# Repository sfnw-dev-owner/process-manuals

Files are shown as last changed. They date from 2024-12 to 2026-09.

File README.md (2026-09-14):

## Tiny Home Manuals

### Background

This is the home of all manuals used in the Sound Foundations Tiny Home build process. 

Each manual has its own separate folder. Text is stored in Markdown, and images are in a subfolder, so that they can be edited independently. 

Rendering is done through a pipeline of Pandoc and Typst, which generates a PDF file that combines the text and images into a printable document. 

### Authors

If you have questions about the manuals, please direct them to: 

* David Means (means@digitalelephant.org)
  * All manual text and home building processes
  * 2D images 
* Charlie Benditt (cbenditt@hotmail.com)
  * 3D images 
  * Whole-home model
* Ami Fischman (ami@fischman.org)
  * Technical questions related to this github repository, generating and editing manuals
* Daphne Chong (daphne.h.chong@gmail.com)
  * Originator of the 3d model for a Tiny Home

## Setup & Installation

You will need:

* Git source control software, either in [command line](https://git-scm.com/downloads) version or a [user interface like GitHub Desktop](https://github.com/apps/desktop)
* A text editor that can edit plain text without introducing other markup (eg Vi, Emacs, Notepad)
* A local computer to run this stuff on, and to keep a local copy of the repository.

## Formatting a manual

Our process begins with a text file containing the desired content, and Markdown commands to indicate formatting.  This source file is processed by a pipeline of two stages: first by Pandoc, which transform the markdown into Typst input, and then by Typst, a typesetting program that renders its input as a PDF file.  This pipeline is captured as a virtual machine, and is invoked as `render/go {source_file}`.  When this script is run, it either generates a PDF file with the same base name as the source_file, or else it coughs up some error report, saying why it could not.

### Common template file

Using a template creates a consistent look and feel for all of the manuals generated. The default settings for our documents are kept in `render/pandoc-defaults.yaml` and `render/typst-header.typ`. 

The template has instances of:

* Heading 1
* Heading 2
* Heading 3
* Heading 4
* Normal text (which bullet lists also use, see note below)
* Footer with automatic revision date insertion

### Bullet lists

Generally, a bullet list is defined in markdown with a prefix of `*` `-` or `+`. Sub-lists look the same, but indented (2 spaces, or a tab)

### Aligning images in Markdown

Images that aren't geared to letter sized paper might require adjusting. These are the current settings in `post-tilt-up` and `tilt-up` manuals (where images are generated as A5 size and designed for A4 paper, which has different dimensions than Letter).

#### Top of document 
* Treat all images in the document as "figures" 
* Align all figures in center for PDF files

#### Centering an individual image
For an individual image, you must leave an empty line before and after each image in the markdown, otherwise the center alignment won't work. 
```
// won't work for center alignment
![](images/image_39.png){width="78%" height="78%"}
![](images/image_39.png){width="78%" height="78%"}

// will work for center alignment
![](images/image_39.png){width="78%" height="78%"}

![](images/image_39.png){width="78%" height="78%"}

```
#### Resizing images to get more than one on a single page

As above, we use a **78%** scale to get more than one image on a single page, which allows for spacing for the (blank) captions generated by pandoc. 

```
![](images/image_39.png){width="78%" height="78%"}
```

This applies with the current Letter page size with 0.5" margins. 

## Generating 2-d drawings
We have moved to a mechanism that allows us to put a QCAD .dxf file under revision control, and to create PDF images automatically from the .dxf file.
The invocation for an image that is to be included is

```
`#fullpage("images/{qcad_filename}.dxf", layers:"{comma-separated list of layer names}")`{=typst}
```

By convention, the DXF file is placed in the **images** sub-folder

 The layers to be made visible in the drawing file are specified as a comma-separated list.  Spaces are allowed within each layer name, but there should not be any white-space between the layer name and the preceding or following comma.

 Also note that the `typst` syntax in the example above (anything passed to a \'#...{=typst}\` macro) requires a colon (`:`) between `layers` and the layer names, whereas the markdown syntax (e.g. ``) requires an equal sign (`=`).

## Rendering a Manual

### Generating the PDF file

Contents are taken from the `<manual_markdown_file.md>`, combined with any images referenced from the markdown, and rendered into a new `pdf` document.

To render the document:

* Open a command-line shell window
* `cd` to the directory where your markdown file is stored
* Type the command `../render/go <manual_markdown_file.md>`
* This generates a new file `<manual_markdown_file.pdf>` in the same folder as the `<manual_markdown_file.md>` file, with all of the correct formatting (based on styles in the template files), and the text and images referenced in the markdown. 

### Add the source file to source control

After generating a PDF file, check it throughly for formatting errors, correct them in the source (.md) file, and repeat the rendering, until you are satisfied.  Then, it would be good practice to delete the PDF file, before you even commit changed files locally.

Commit the source material only (the .md file and any images, qcad drawing files or other included files).  Do NOT commit the PDF generated above.

A github **workflow** will kick off an **action** which will generate a GitHub Release containing all rendered PDFs. See the latest release at https://github.com/sfnw-dev-owner/process-manuals/releases/latest.

If you create a brand-new .md file, it is good practice to add the corresponding .pdf filename to .gitignore. This will reduce the chance that
you inadvertently add a PDF to a *git commit*, polluting the source tree with a derived file.

## Editing 3D model and images used in Tilt Up & Post Tilt Up 
All of the 3D images and diagrams in the manuals are created using LayOut, based on this [Tiny Home Model](https://web.connect.trimble.com/projects/H3xXgzdyUMc/viewer/3d/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) built in SketchUp. 

You will need:

 * [SketchUp](https://www.sketchup.com) to edit the model. There are [free web-based editions of SketchUp](https://www.sketchup.com/en/plans-and-pricing/sketchup-free), although the model was built on a desktop using SketchUp Pro.
 * [LayOut](https://www.sketchup.com/en/products/layout), part of the SketchUp Pro package, for taking scenes built in the model and laying them out on to pages with various insets and annotations.
 * Permissions to edit the model. At the moment, only a limited number of people have access.

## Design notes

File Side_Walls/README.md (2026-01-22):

sidewall_[13].md correspond to the two different jigs for building
side-walls. They are nearly identical except for mirrored drawings and
funky board location being different.

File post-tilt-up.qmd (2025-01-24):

---
format:
  docx:
    reference-doc: manual-template.docx
    fig-align: center
from: markdown-implicit_figures
--- 

# Secure walls to platform

* Equip two crews of two people with screw guns and brown #10 x 3” screws, and have them install 4 screws in each bay of all four walls, through the bottom plate into the platform, as shown in the diagram.

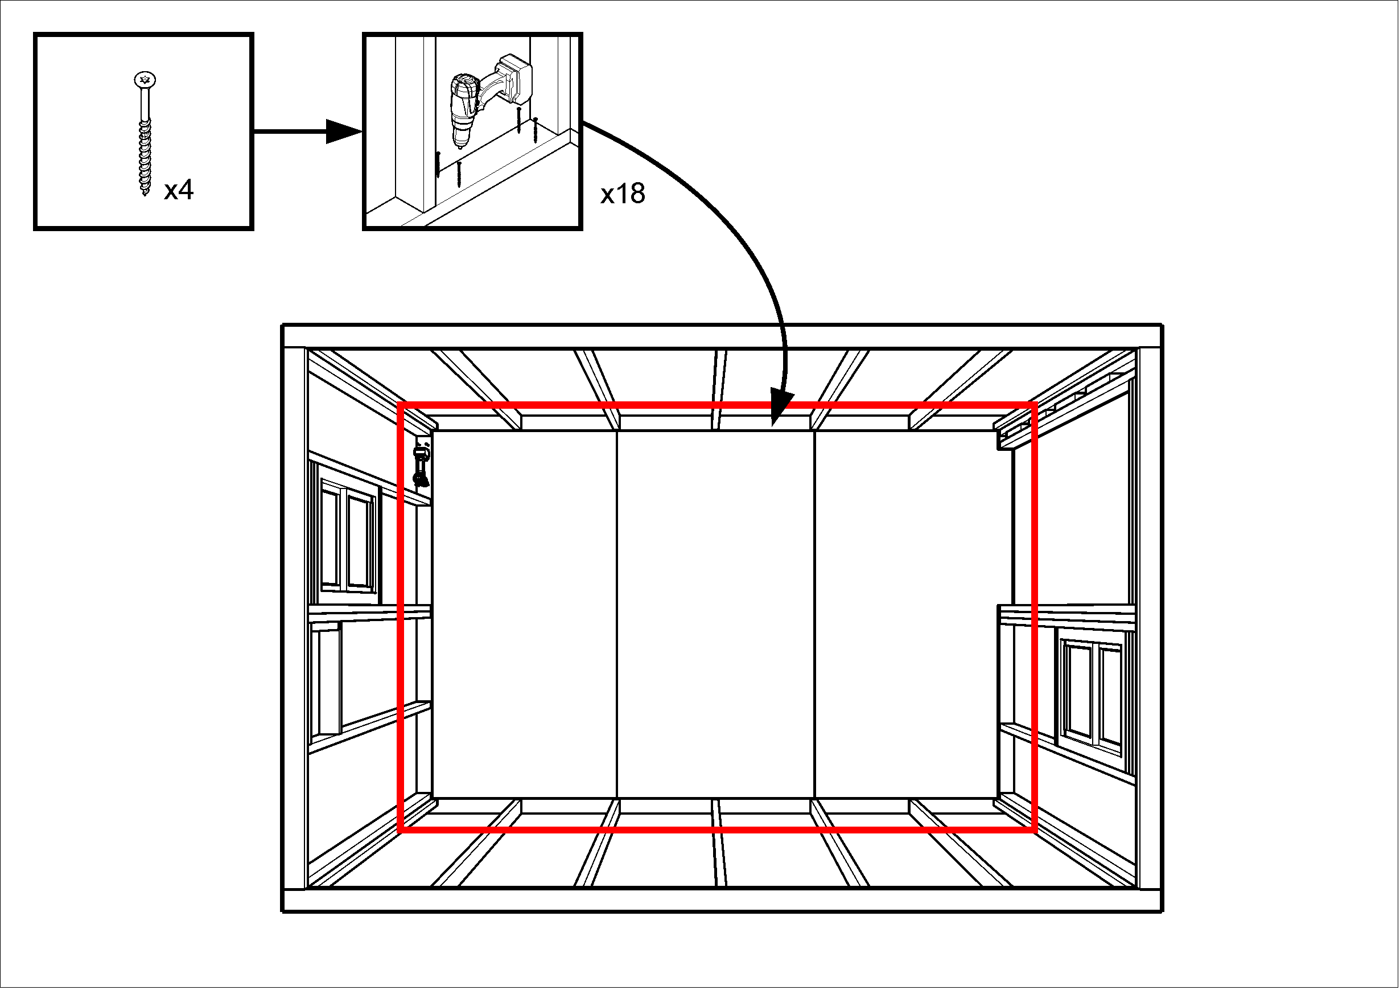
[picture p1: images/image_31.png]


{{< pagebreak >}}

* Have one person install 5 #10 x 3” screws in each wall corner, to reinforce these corners

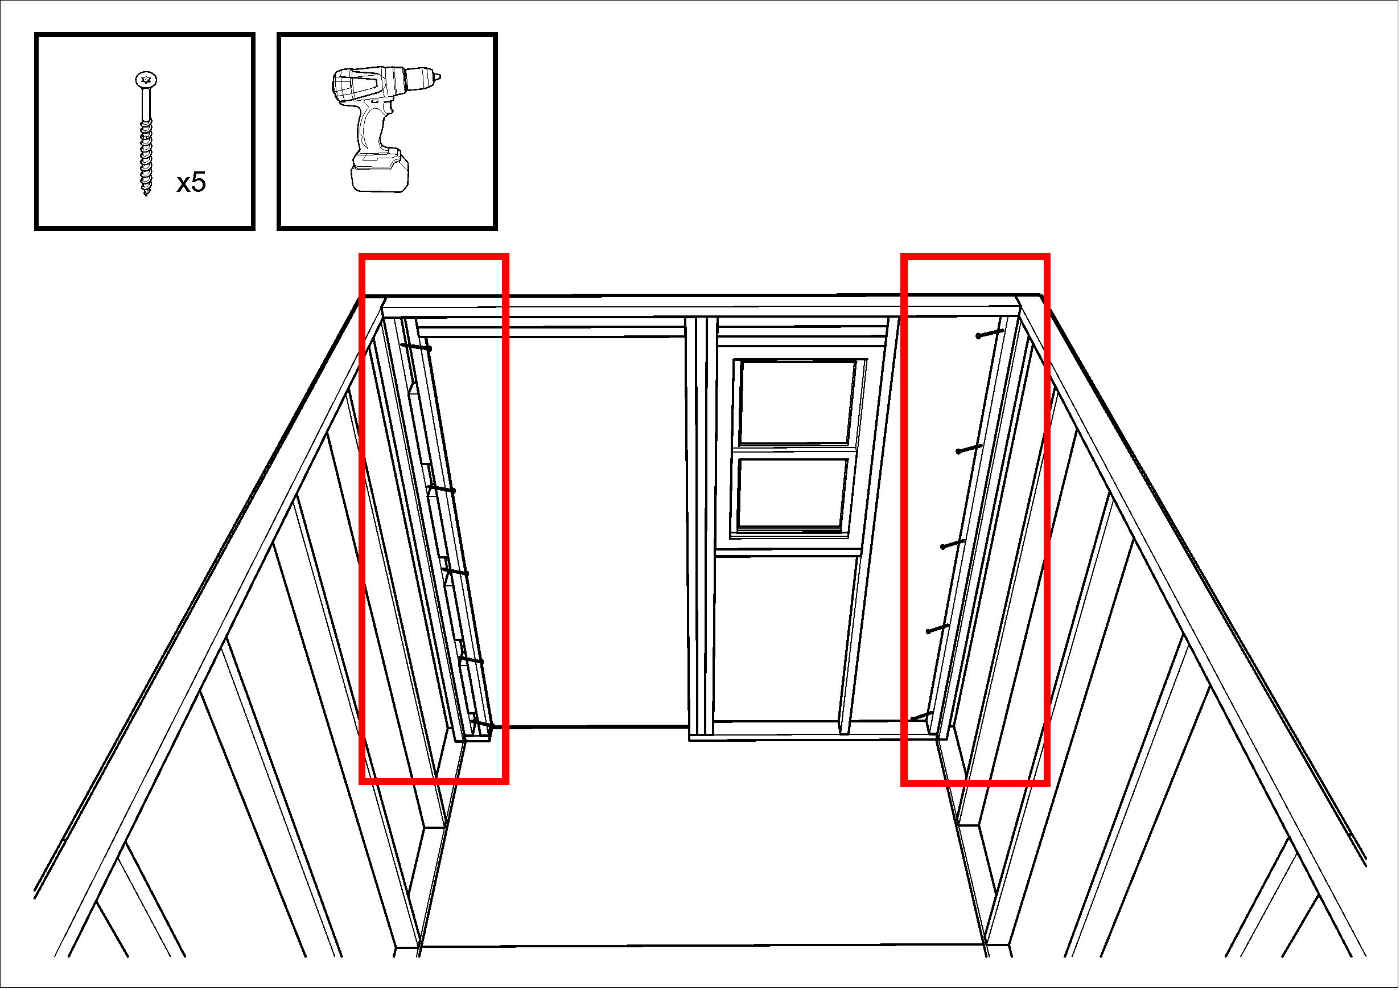
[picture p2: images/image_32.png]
 

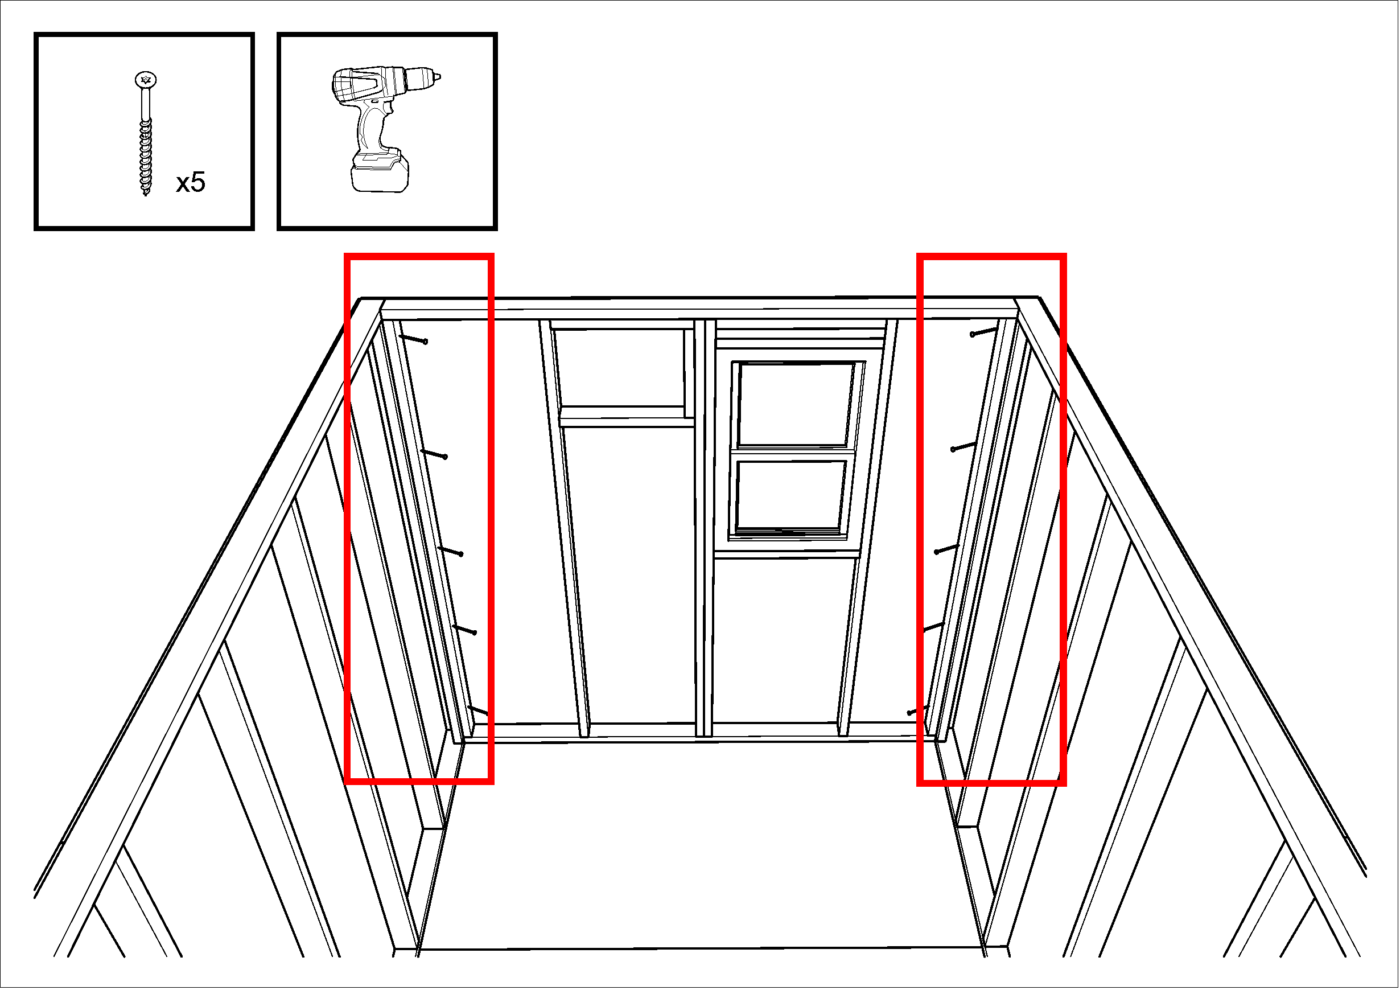
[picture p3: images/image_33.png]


<!--- 
This is an implied page break - avoids an empty page being generated
---> 

*	Using panel nails and working from the outside of the home, nail through the wall paneling into the base of the platform frame about 1” above the bottom of the paneling, every 8” all the way around the home.
*	Again, using panel nails and working from the outside of the home, nail the edges of the front and rear wall panels to the side-wall framing, about 1” in from the edges of the paneling, and 8” apart all the way from bottom to top of each corner.
*	Verify that the exterior paneling is nailed to the frame around the top and sides of the front door.  If not, nail that at this stage (every 8”).
*	Using a reciprocating saw (Sawzall), cut through the bottom plate of the front wall at each side of the doorway.  This should free the 2x4 so that it can be removed.  Use a knife to cut the Tyvek even with the top of the platform, and then use the Sawzall to cut the paneling at the bottom of the doorway so that it is flush with the top of the platform.
*	Using the angle-iron gauge (in the pencil cup in #4 workstation) and an ink marker, draw a line down the center of each of the “magic” studs.  These are the studs on the side walls at the rear of the second bay (4’ from the front wall).
*	Using a speed square, draw a 6” mark on the subfloor where the center of each stud is.  On the top plate of each wall, mark (freehand) where the center of each stud is.  These marks will be used by the people installing wall panels.
*	Using panel nails, nail the paneling to the platform across the bottom of the doorway.

{{< pagebreak >}}

# Install structural triangles

*	Position two 12-foot ladders, one at each end of the building.
*	Preset brown #10x3” screws in each of two structural triangles, as shown in the diagram a couple of pages on from here.  In the two center bays, there are four screws, angled enough that you could drive them in with an impact driver.  In the two outer bays, there are two screws angled in from one side of the triangle, starting about ¾” in from the edge of the bottom plate.  Then there are two screws driven in vertically about 1” toward the center from the seam between the bottom plate and the angled side of the triangle.

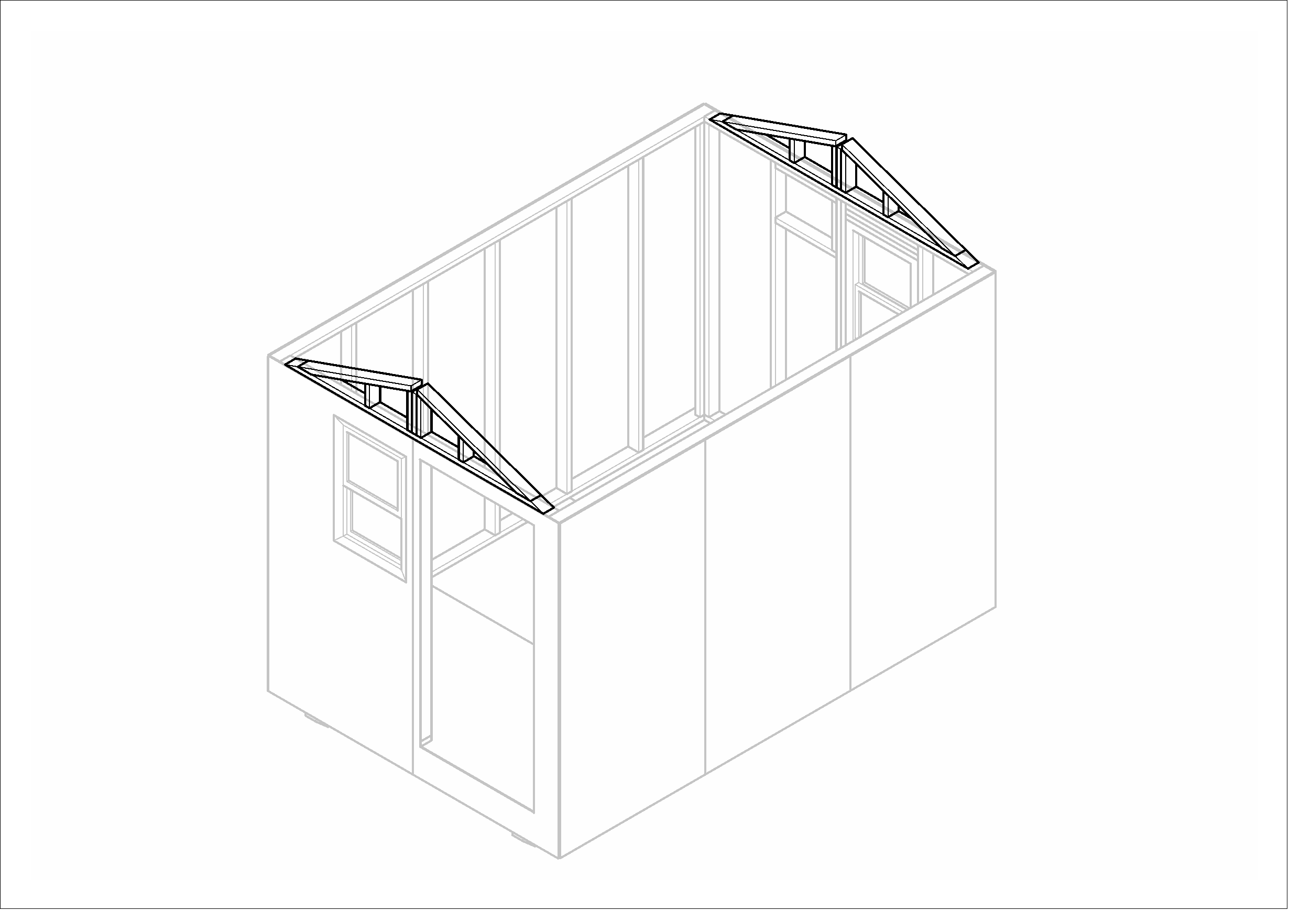
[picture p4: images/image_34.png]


{{< pagebreak >}}

*	Position a triangle on the front wall, and, with a helper inside the home, center it from side to side.

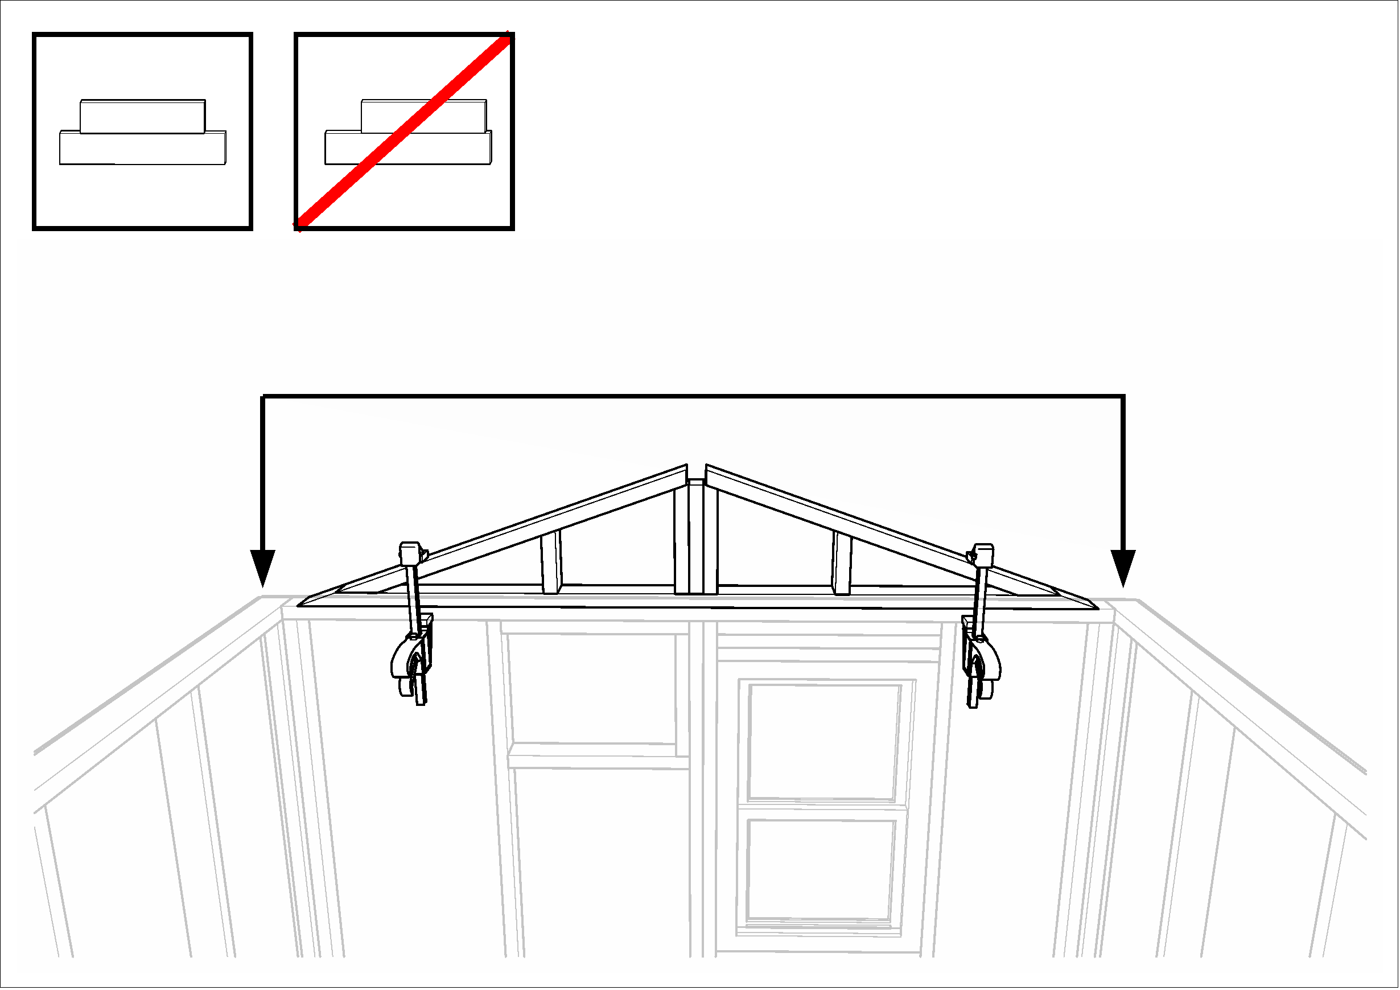
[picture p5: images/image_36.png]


{{< pagebreak >}}

*	Verify that the bottom plate of the triangle is flush with the inside wall framing all the way across the front wall.
*	Clamp the triangle to the wall top plate (or door opening) about 6" from each end.

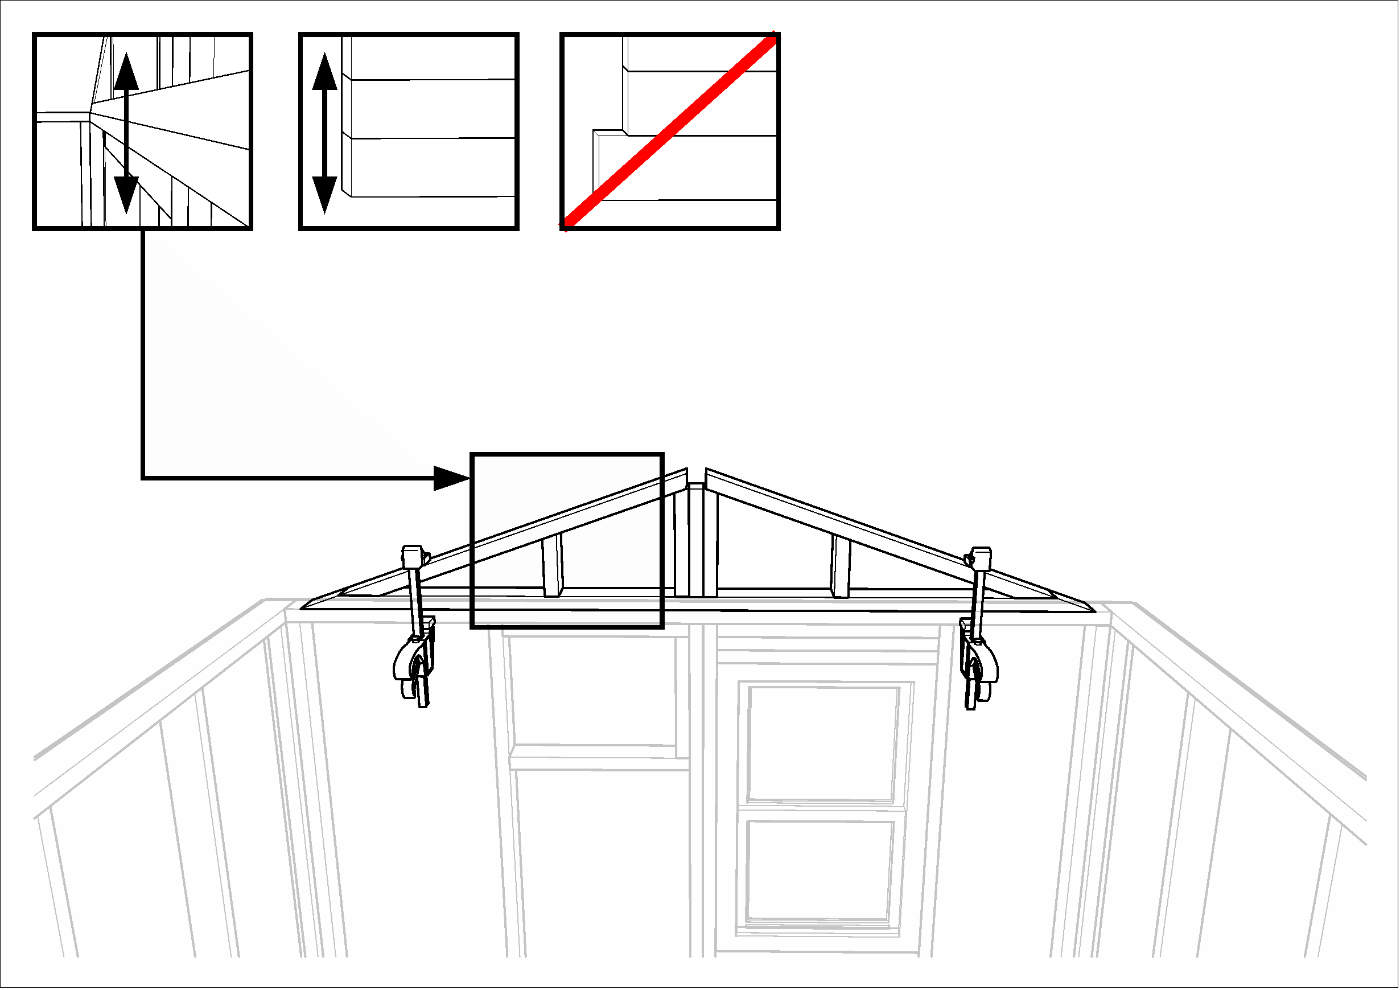
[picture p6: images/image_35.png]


{{< pagebreak >}}

*	From the ladder, drive all the preset screws into the wall framing to secure the triangle.
*	Repeat these last three steps on the rear wall.

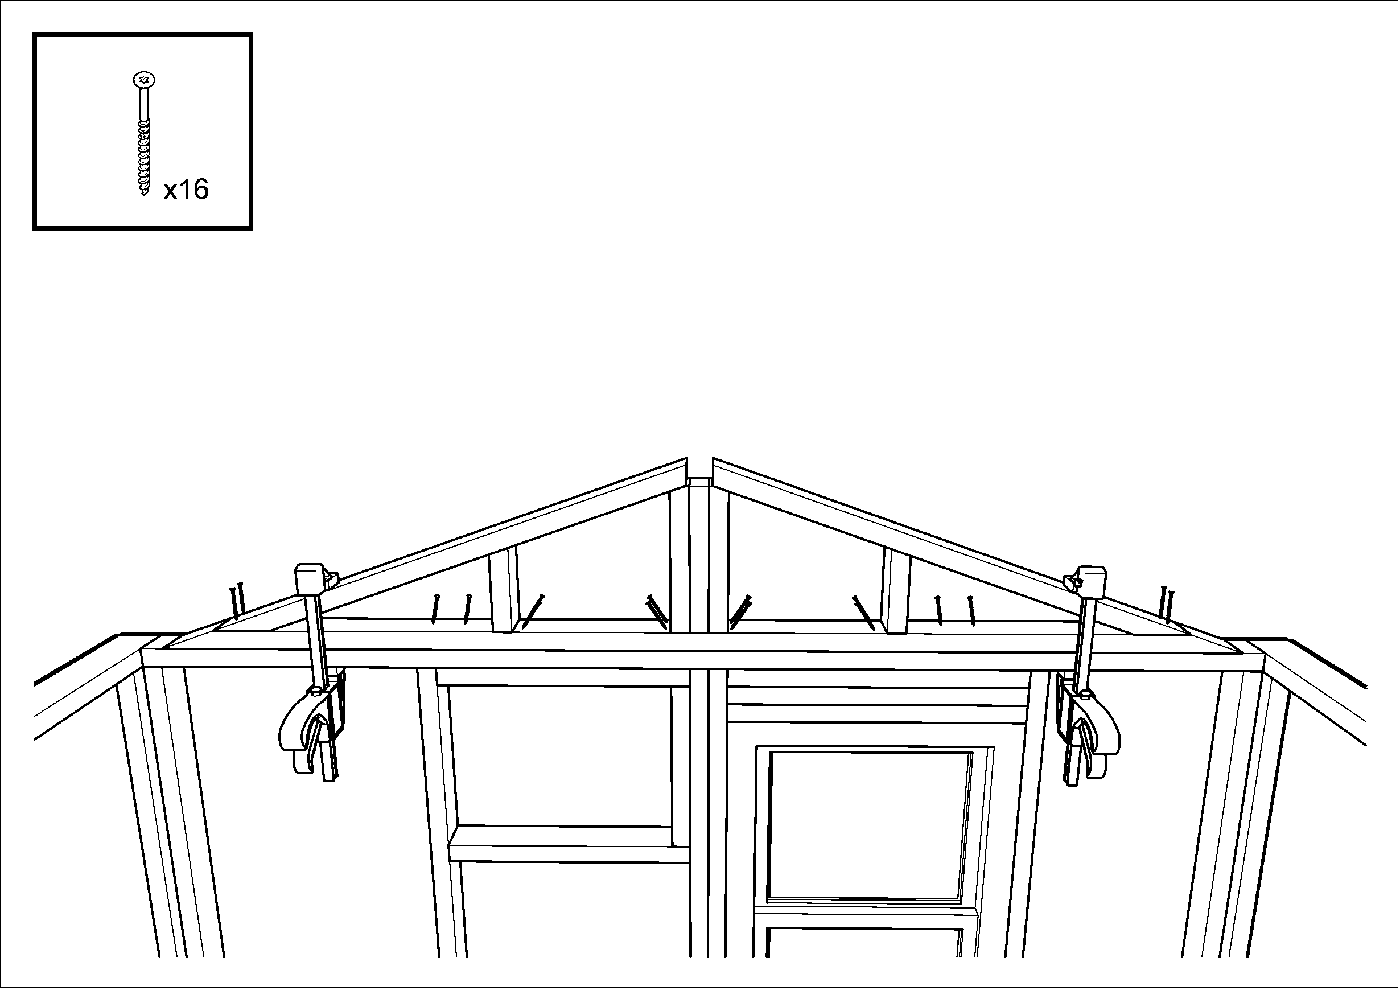
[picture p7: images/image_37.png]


{{< pagebreak >}}

While these tasks are being completed, have two crew members position a half-roof assembly against each of the side walls, with the 1x8 white board at the bottom and facing away from the wall.  Check that there is a pencil line drawn at 6 ¼” from the front of the 1x6 board (the top of the half roof) all the way down and across what will be the bottom of the half roof when it is installed

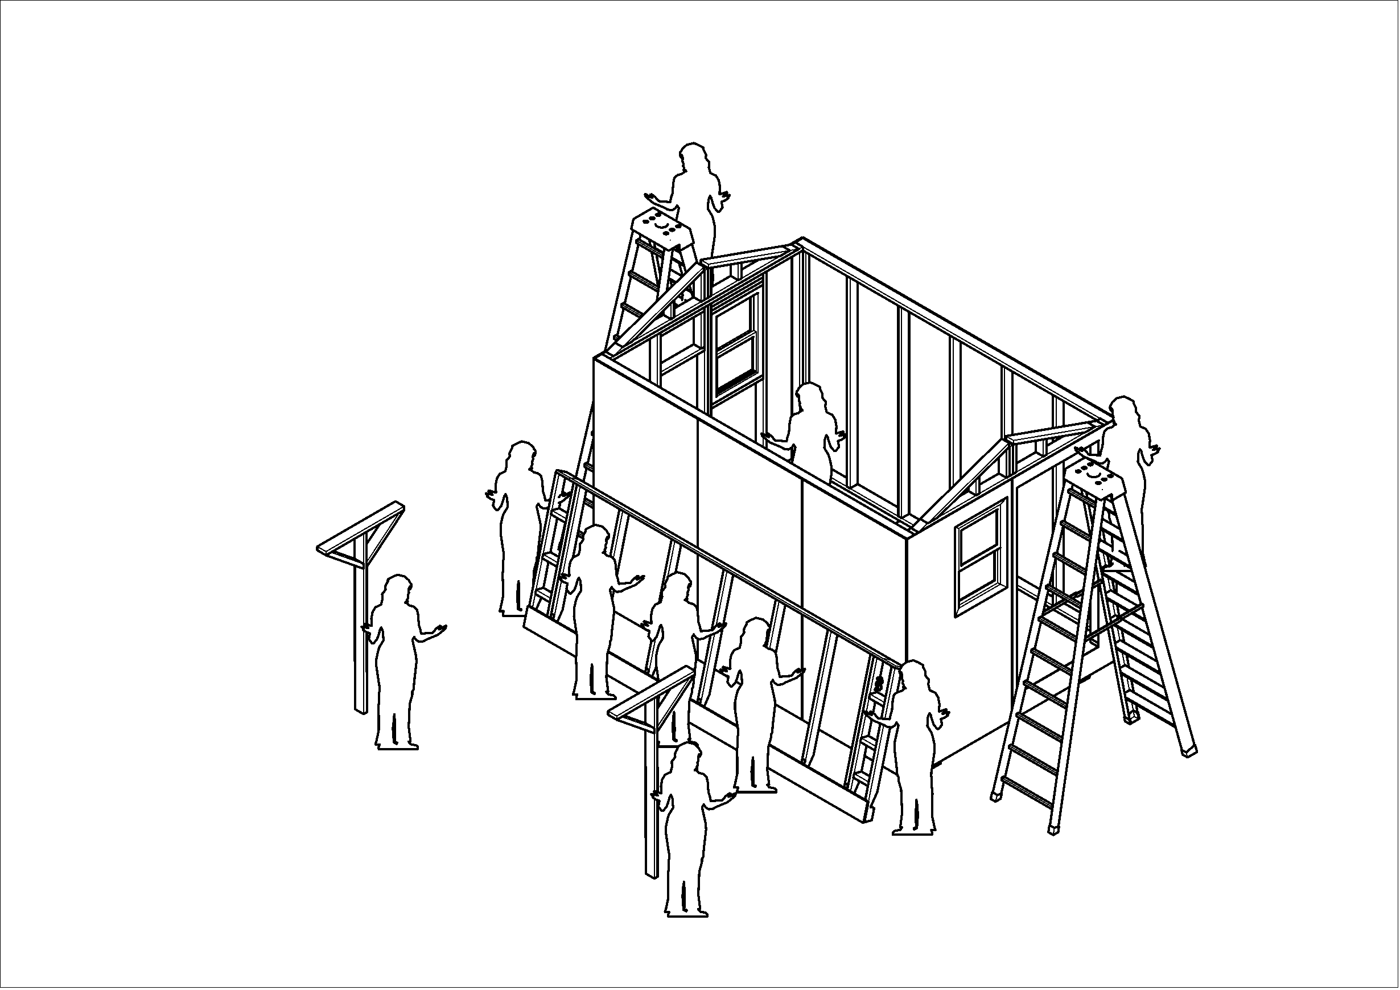
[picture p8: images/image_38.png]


{{< pagebreak >}}

# Raise half-roofs

*	Assign two experienced crew to the front and rear ladder positions.  Make sure each one has two clamps, a screw gun, and at least 4 yellow #8 x 1½" screws.
*	Assign a third crew member to a 3-step ladder inside the home, to assist in final positioning of each half roof.  Position this ladder between the studs, not aligned with a stud, to avoid having a roof rafter come down on the crew member’s head.
*	Introduce Funky Boards #3 and #4.
*	Gather the lifting crew; you will need 7 or 8 people
*	Explain to the rest of the crew how the half roof assemblies will be raised. Five or six people will lift the half roof up about 4 feet off the floor, and then two funky-board wielders will push it up so that the two ladder crew and the interior person can lift it the rest of the way up.  Warn these two to push up at a 45° angle, so that the half-roof slides onto the building instead of falling backwards onto the crew.  Remind the rest of the crew on the ground to take notes, because they will get to do the second half-roof.
*	Lift the first half-roof.

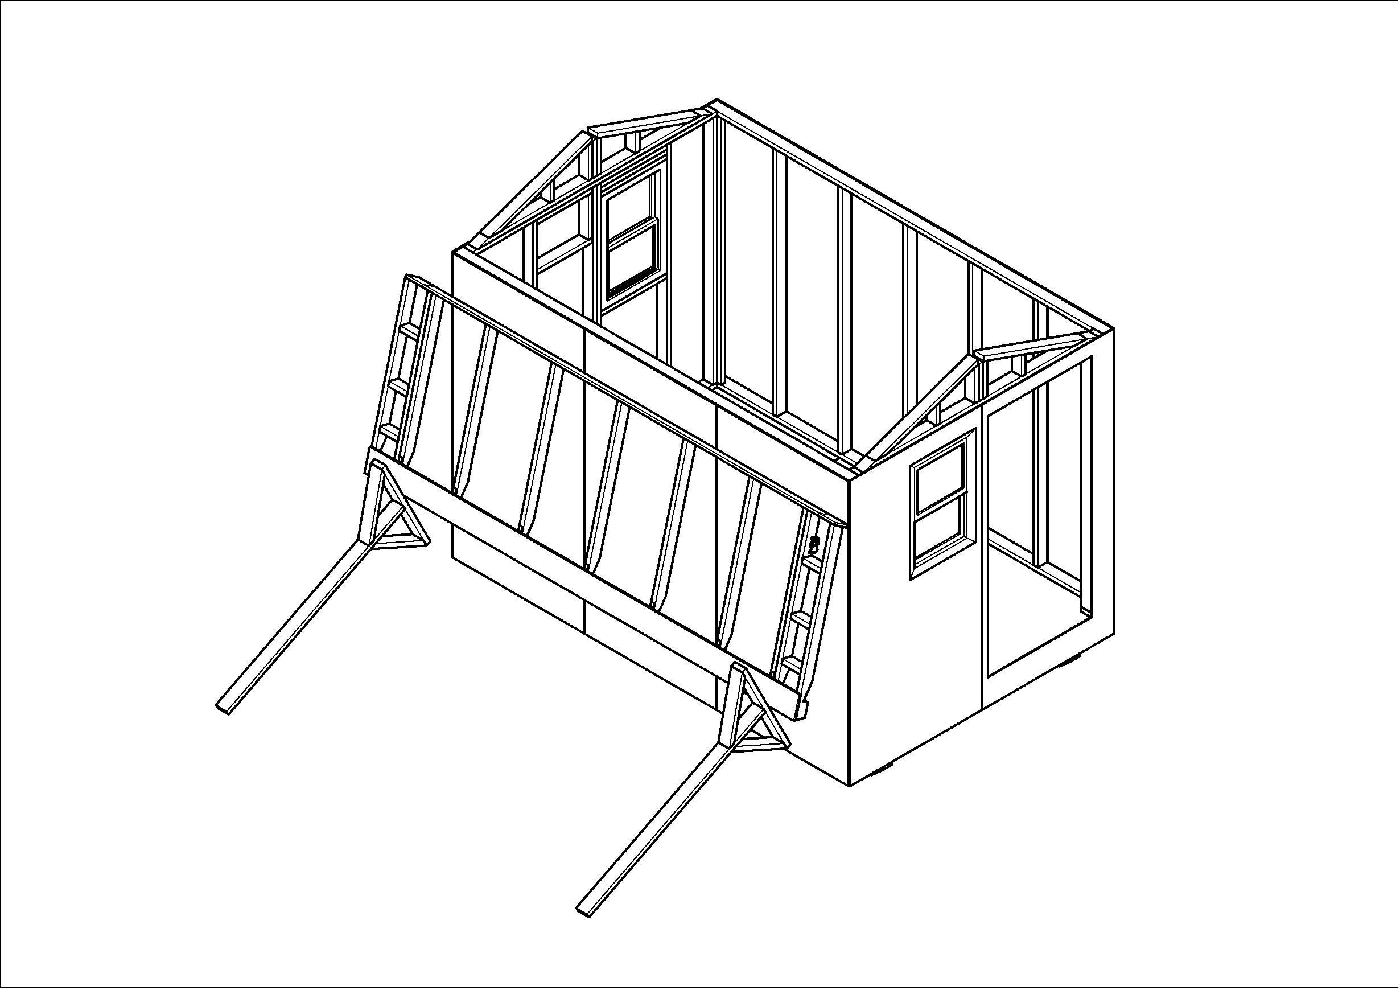
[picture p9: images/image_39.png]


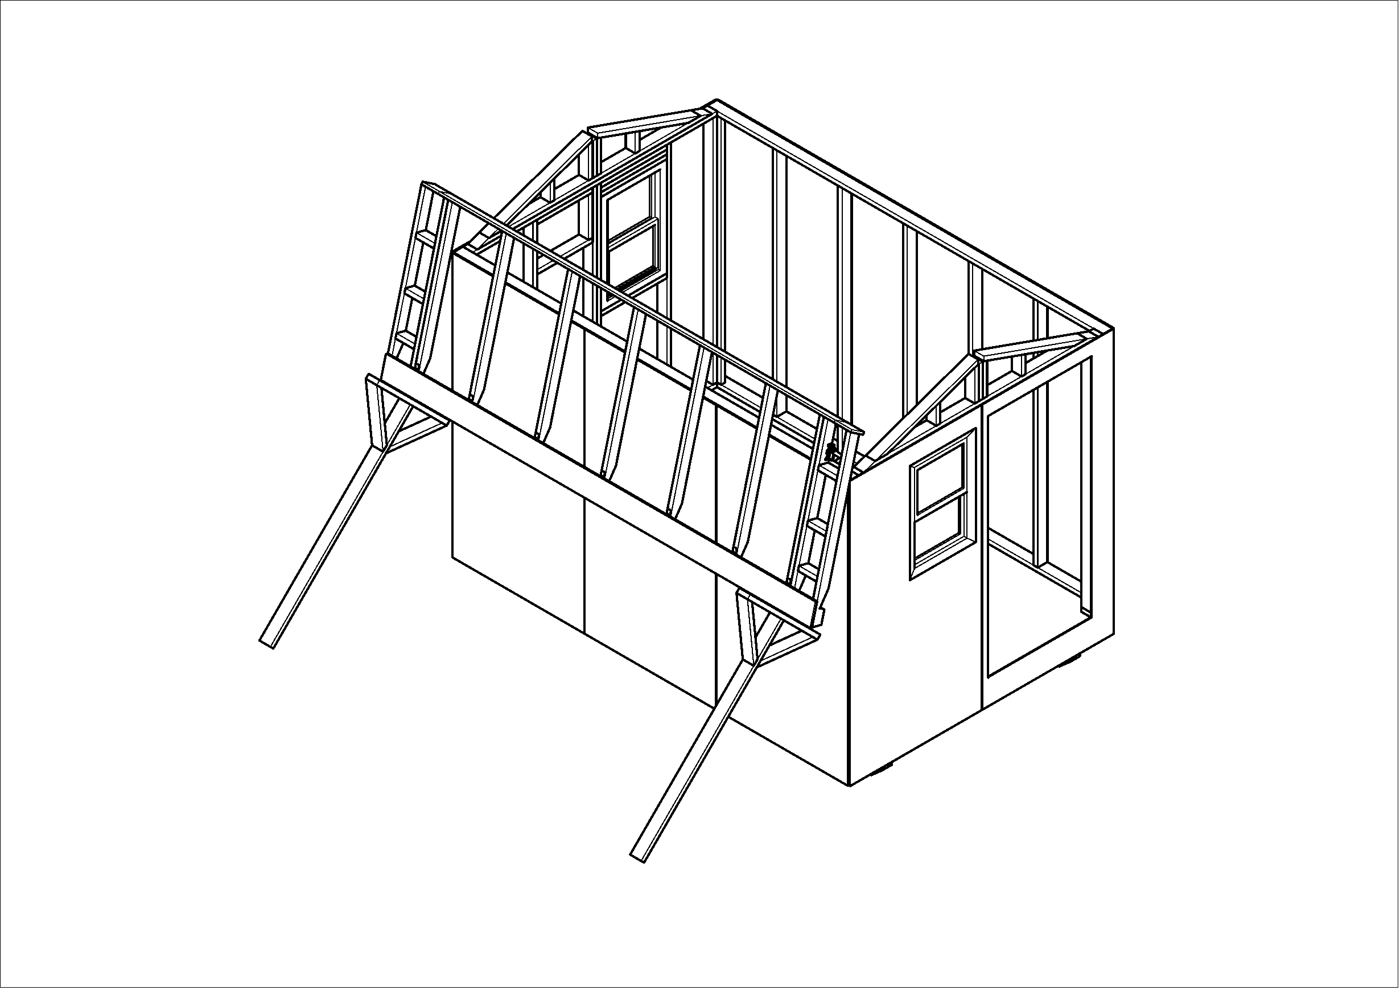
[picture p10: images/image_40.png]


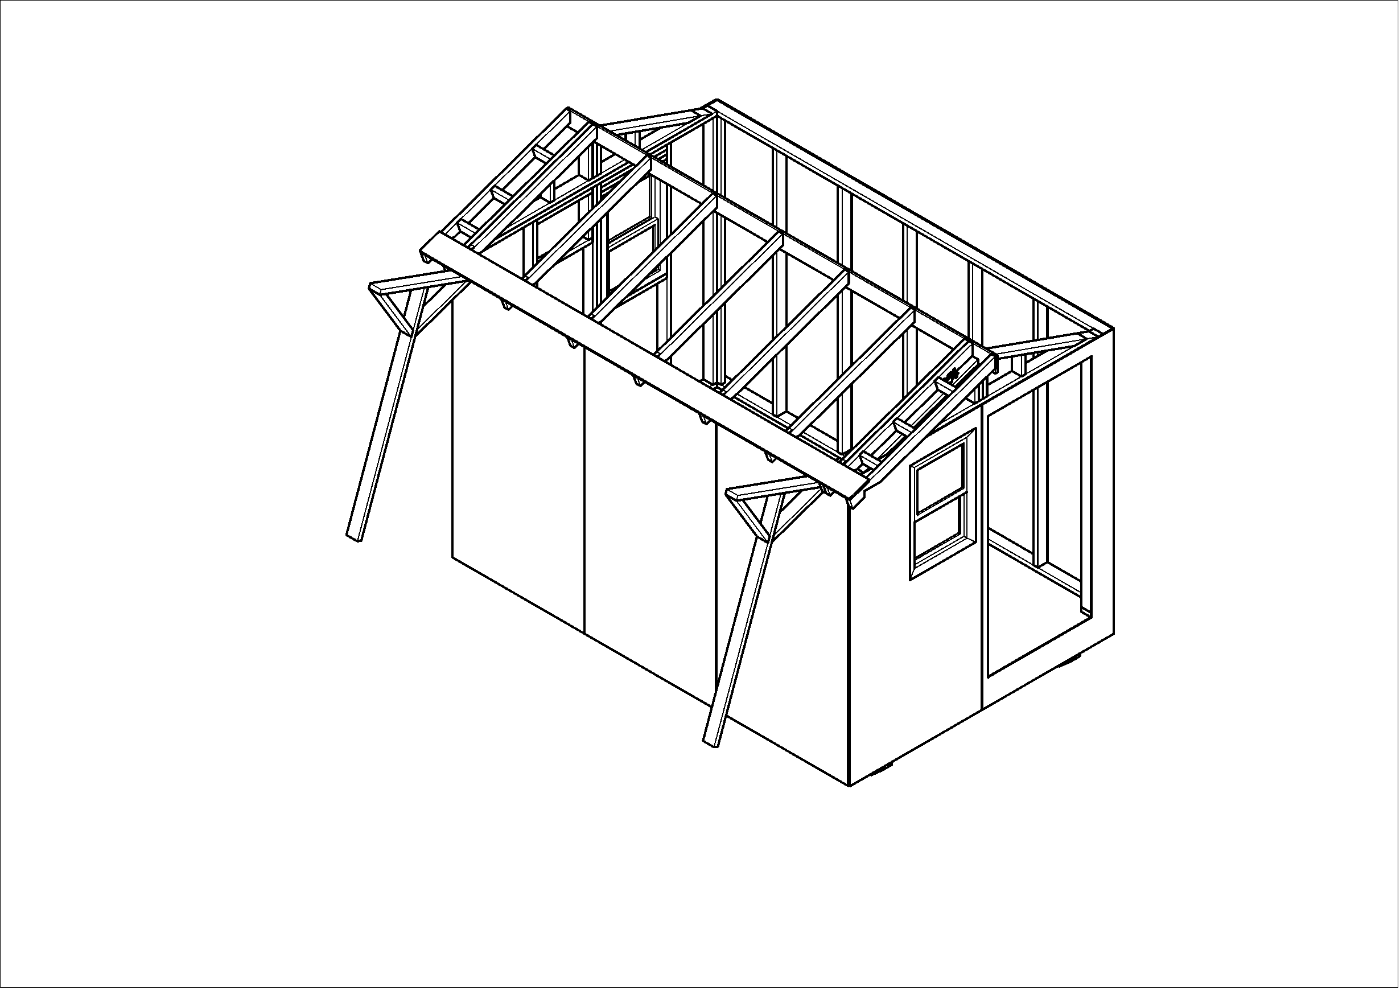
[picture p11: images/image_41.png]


{{< pagebreak >}}

*	The ladder crew guide the 1x6 white board into the central notches in the structural triangles.  If necessary, the ladder crew may ask for help from the people on the funky boards, to lift (temporarily) the rafter ends either at the front or rear so that the half roof is properly positioned.
*	Then the front ladder person aligns the assembly so that the mark on the half-roof is even with the outer edge of the front structural triangle.

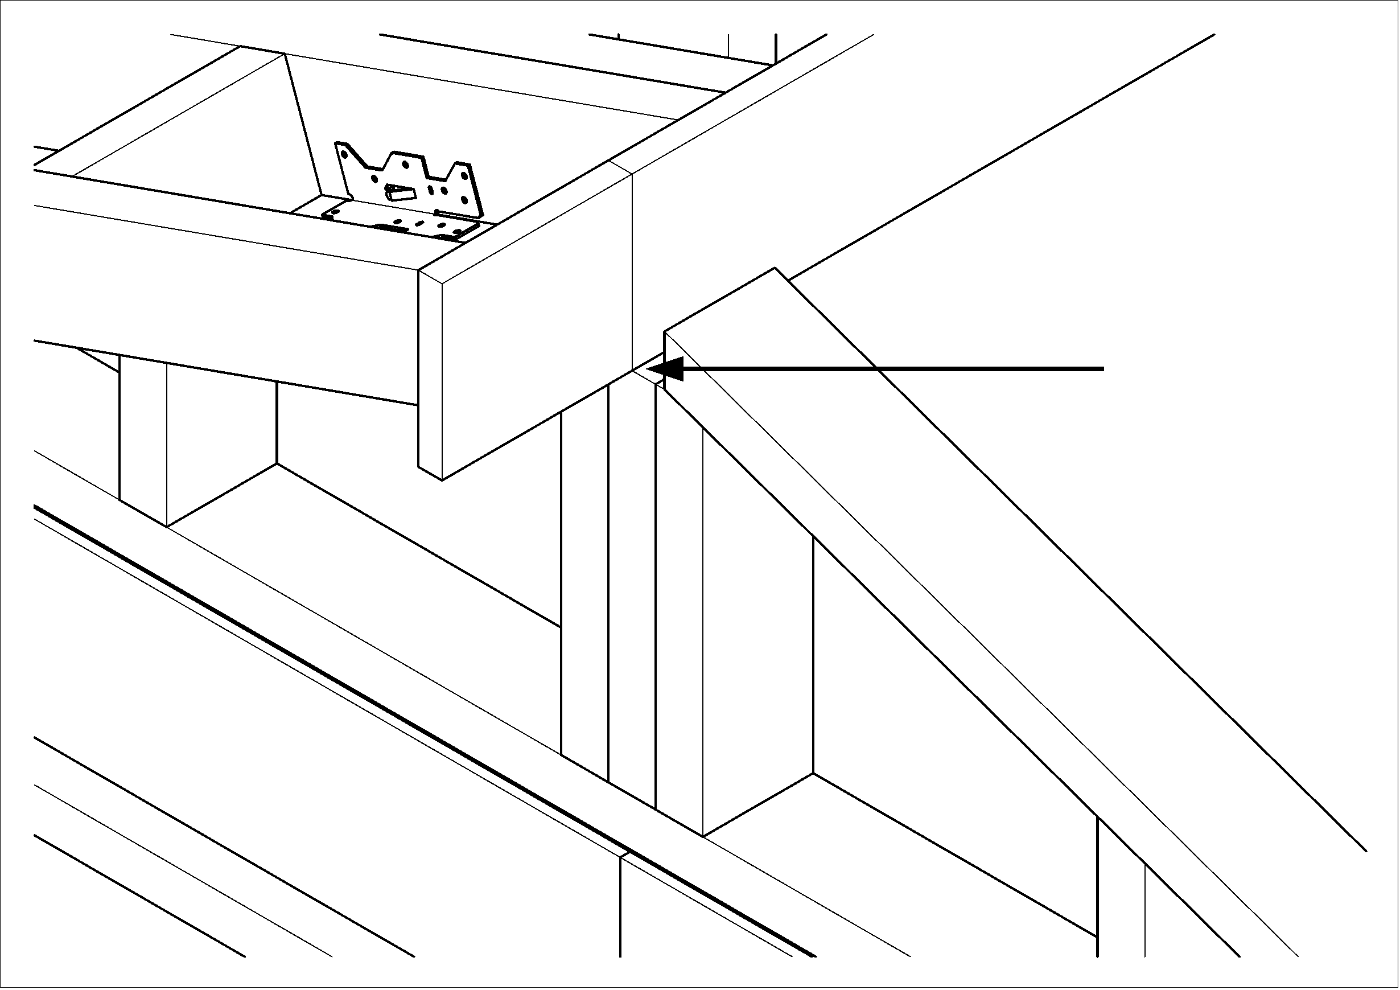
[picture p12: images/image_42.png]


{{< pagebreak >}}

*	Rotate ground crew members who were standing out, and position everyone on the other side of the home for the second half roof lifting.
*	Once the ladder crew have repositioned their ladders, lift the second half roof into position.

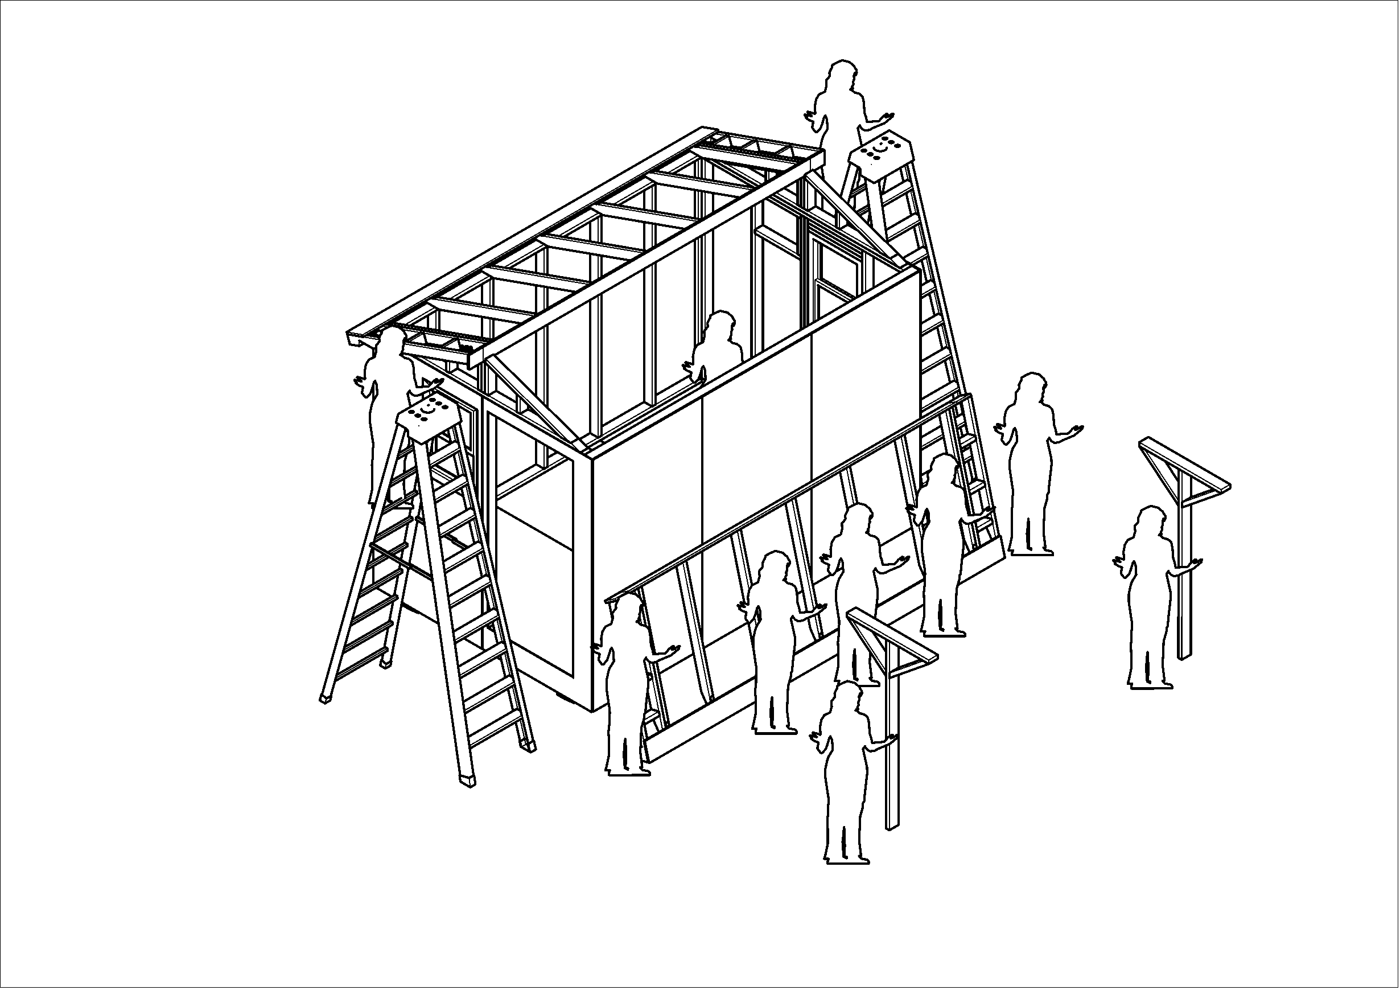
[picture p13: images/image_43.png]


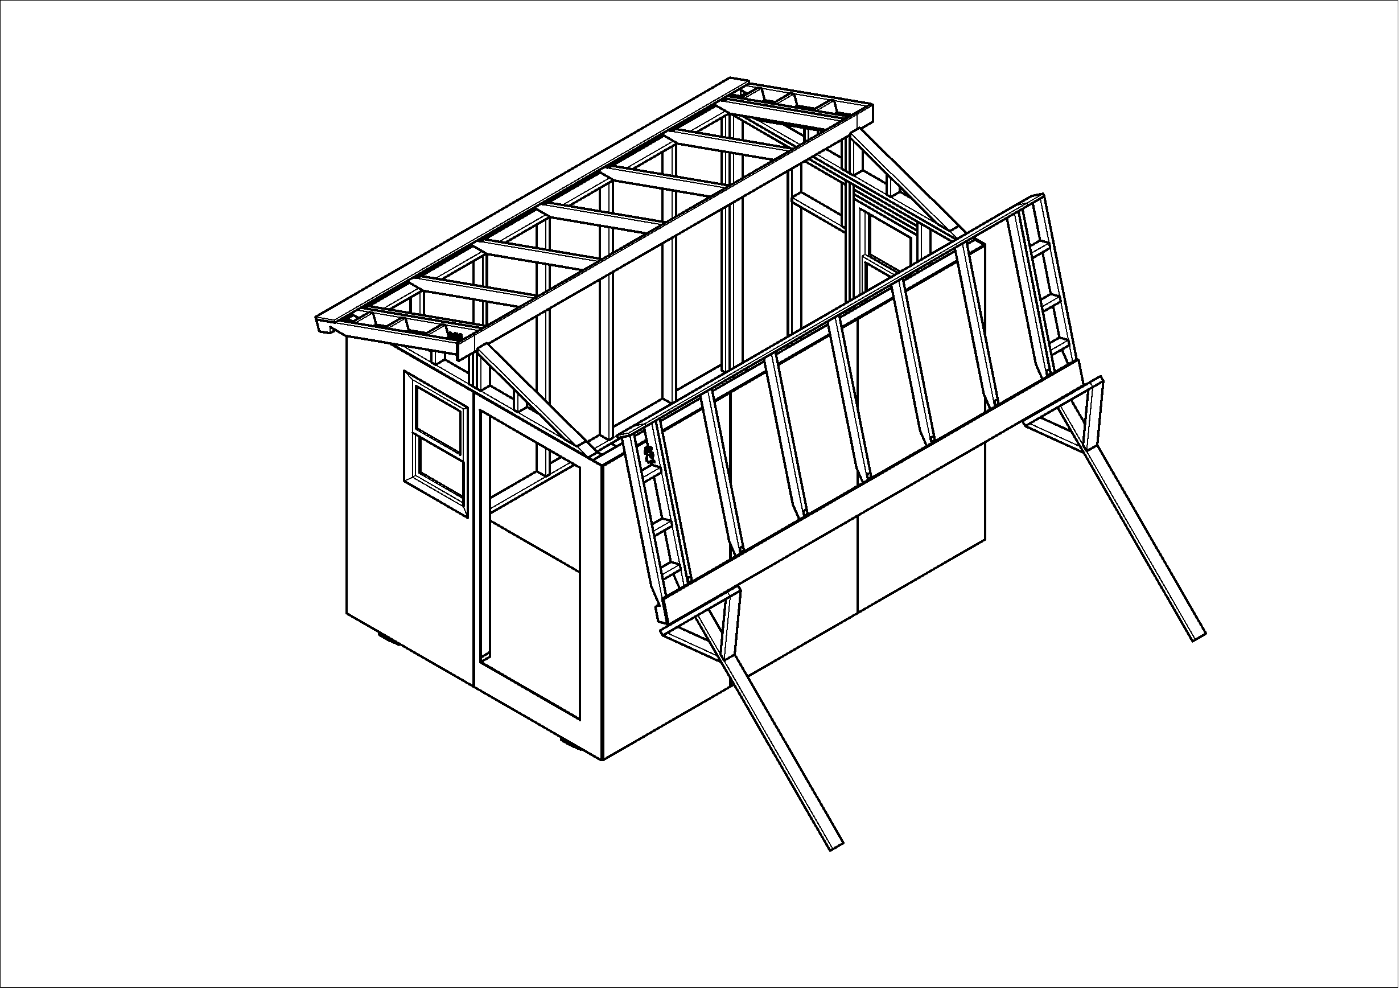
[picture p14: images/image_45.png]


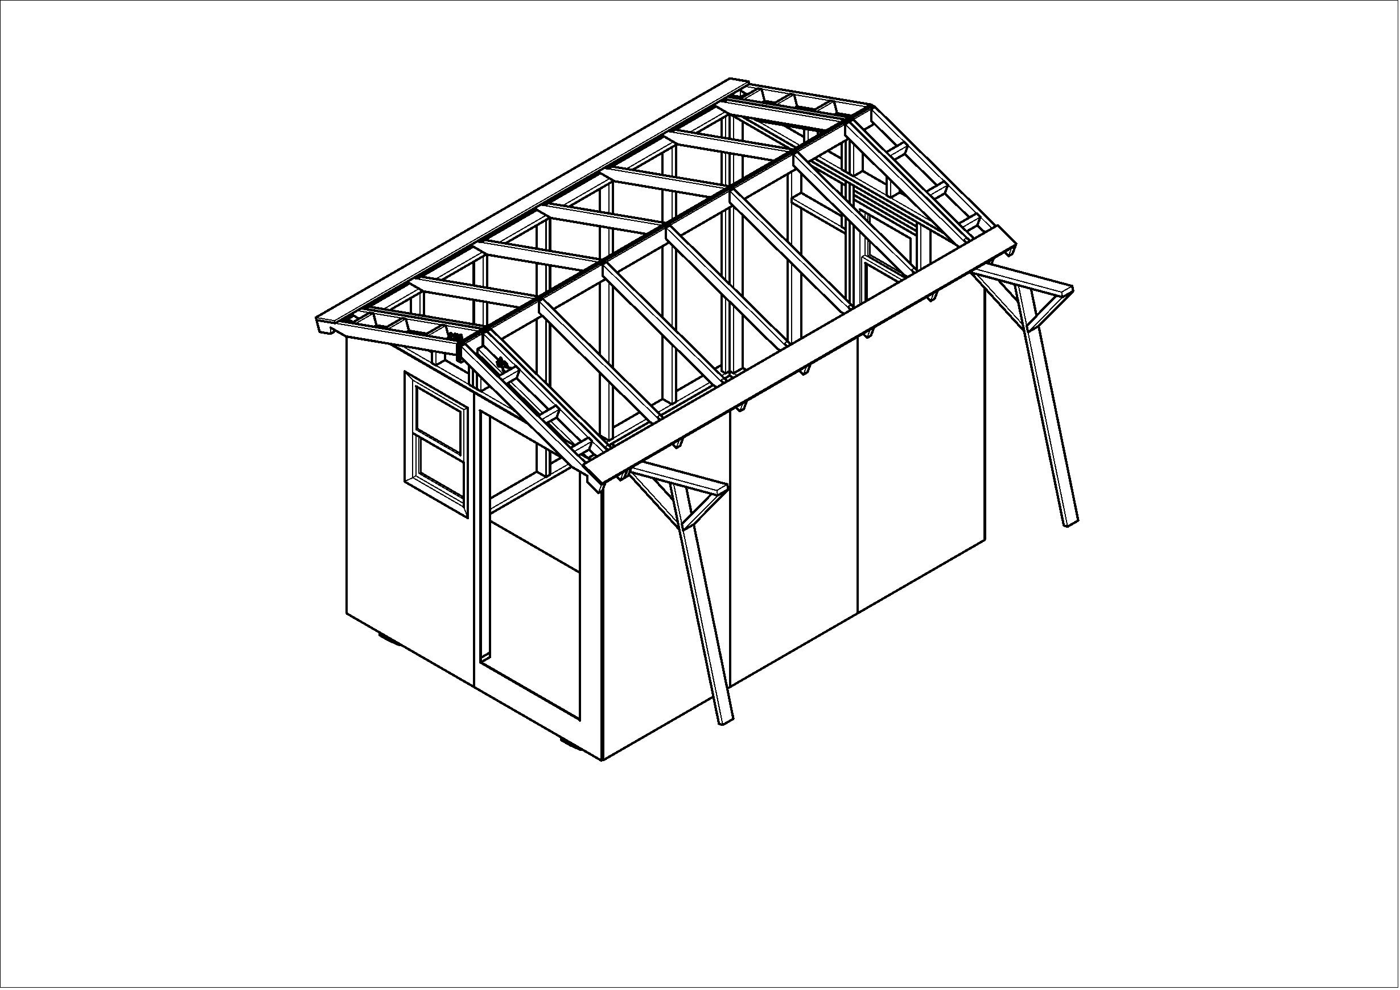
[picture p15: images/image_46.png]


{{< pagebreak >}}

*	The front ladder person leads the alignment of the two half roof assemblies, so that the ends of the 1x6 boards are flush.  Once this is done, both front and rear ladder crew clamp the 1x6 boards together both horizontally and vertically.  Placing the vertical clamp first allows the boards to slide past each other more easily before applying clamp pressure horizontally. Then drive 4 #8 x 1½ screws into the white boards, to secure the two halves together.

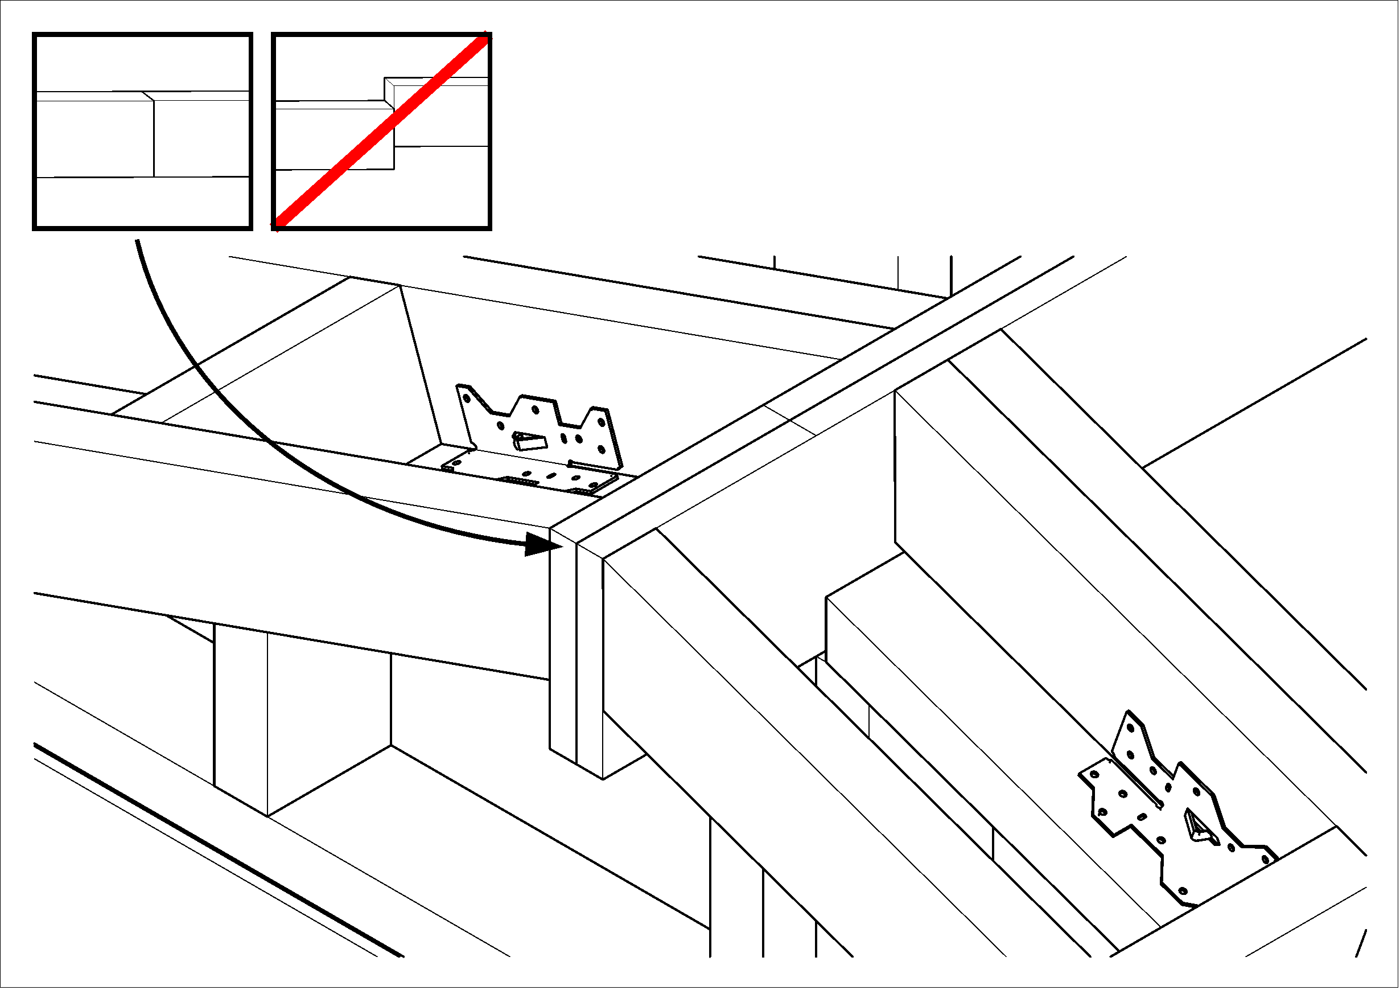
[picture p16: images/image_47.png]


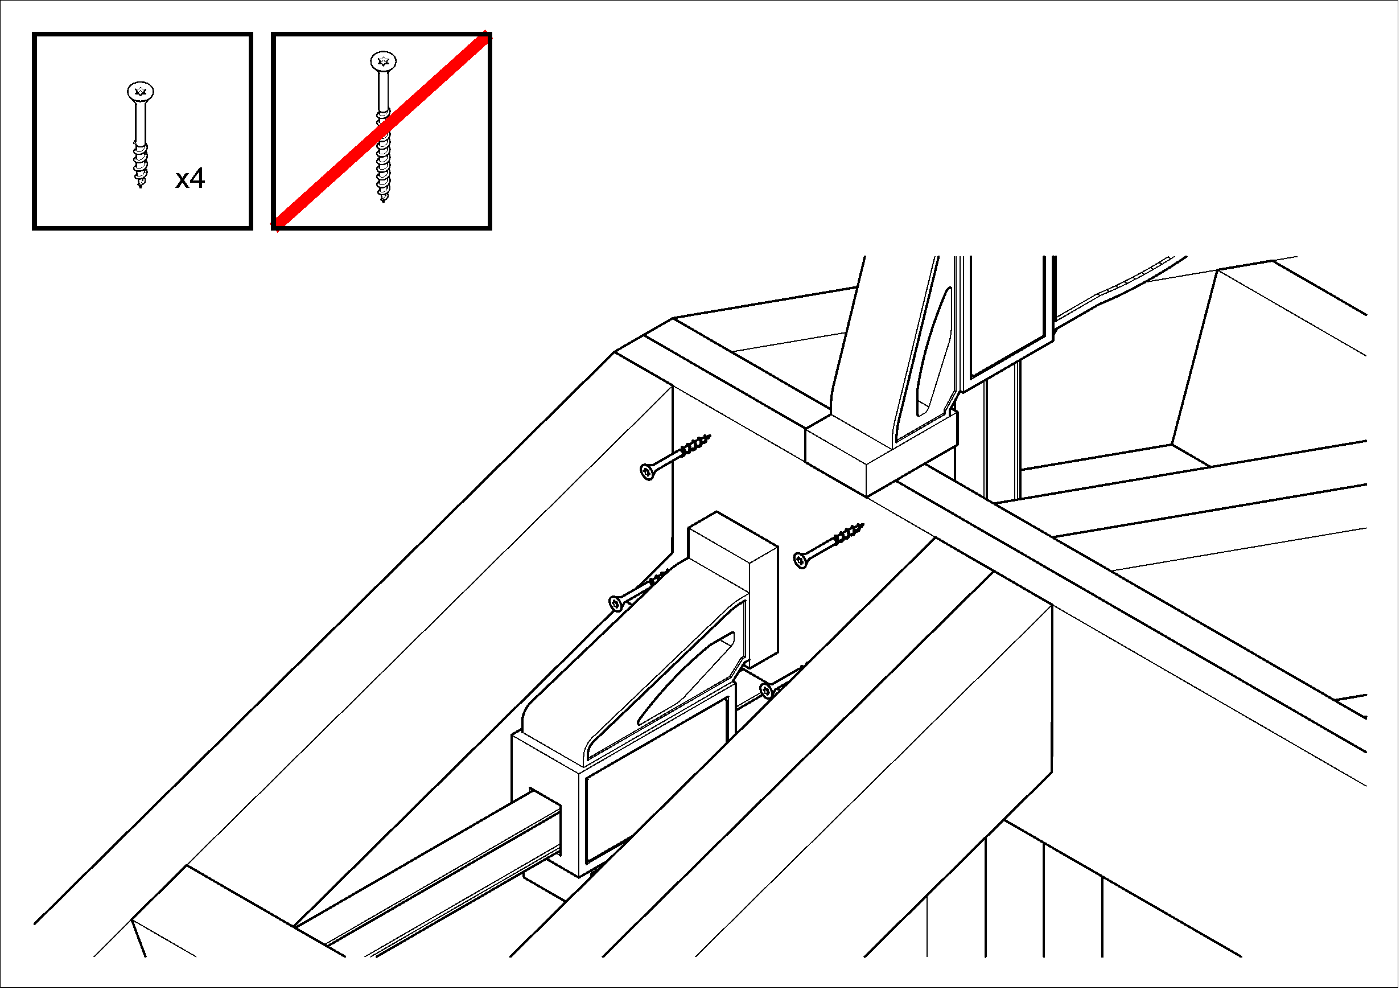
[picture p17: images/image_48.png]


{{< pagebreak >}}

# Screw ridge boards together to create center beam

*	In each bay (between the rafters), clamp the two white boards together, first vertically and then horizontally, to align them and make a tight joint.
*	insert four #8 x 1½" (yellow) screws, two above and two below the centerline, and about 4” from the rafters.  Alternate directions of the screws from one bay to the next.

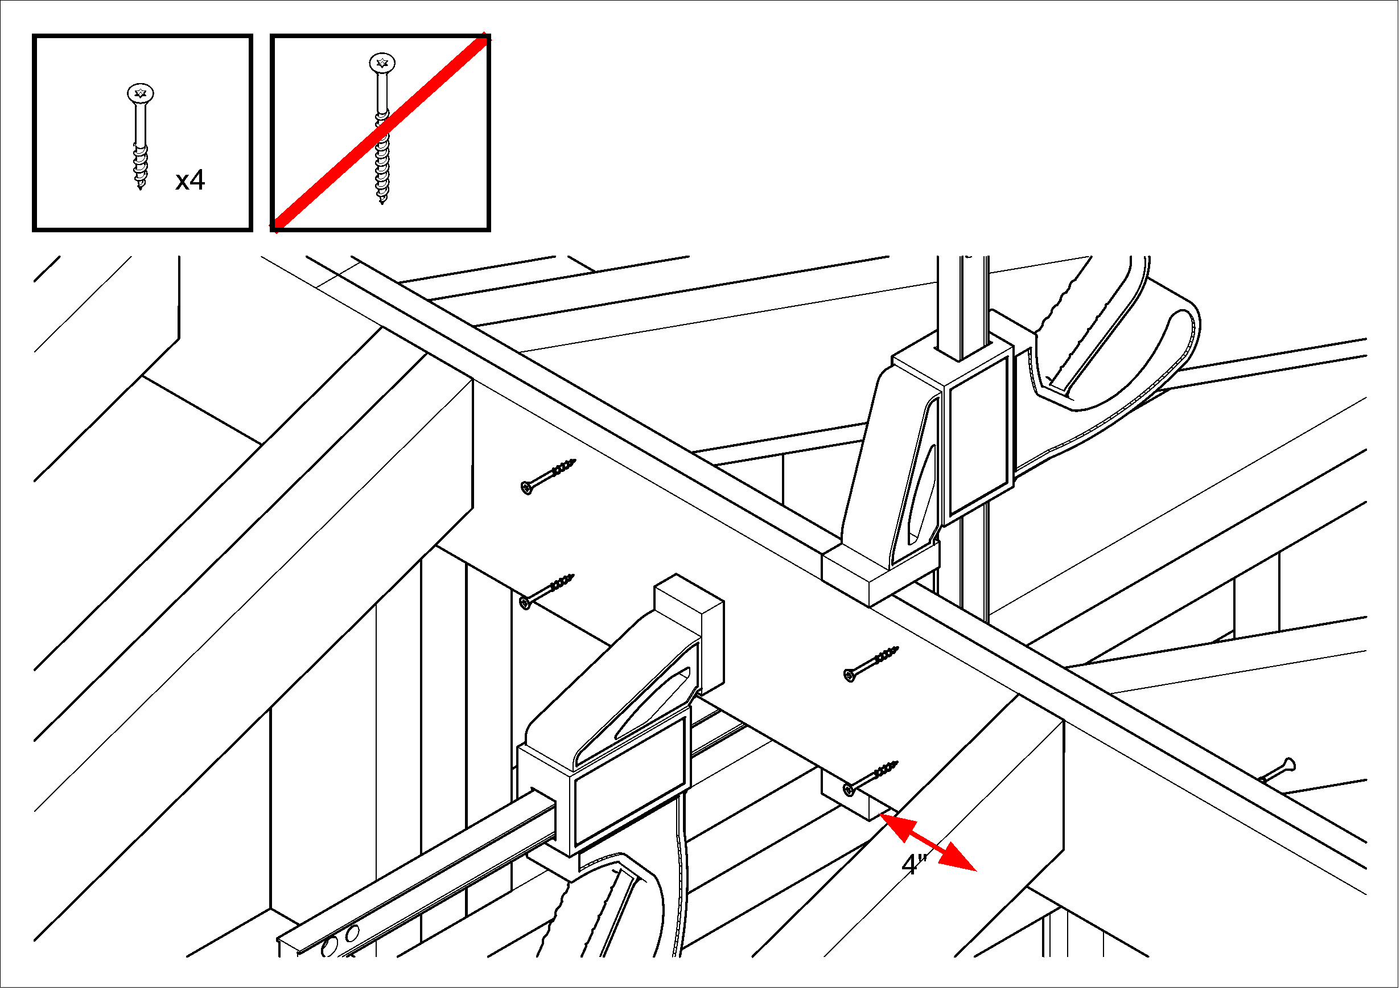
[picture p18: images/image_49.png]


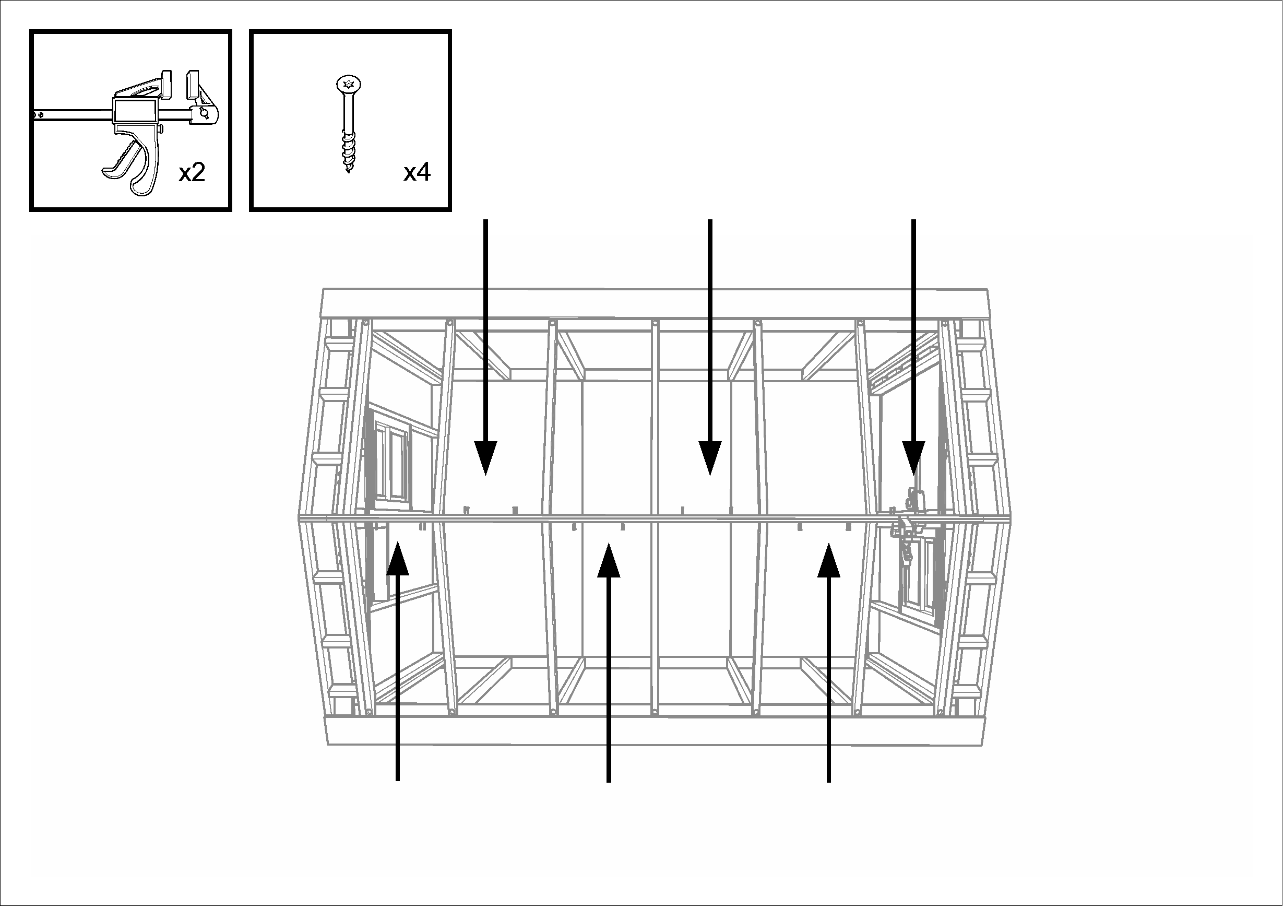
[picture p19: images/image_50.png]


{{< pagebreak >}}

# Secure half-roof assemblies

*	Using the angle-iron guide in Station #4, mark the centerline of the “magic” rafters; these are the ones to the rear of the second bay.
*	Align the “magic” rafters with the stud just below them.  Using a clamp, pull each of these rafters either forward or back so that it lines up exactly with the wall stud immediately below it.  If necessary, have a second person use a mallet to assist.  The place to aim the mallet is on the end rafter at the point where the lowest block is screwed to the rafter.  If you hammer on the rafter end, something will split.

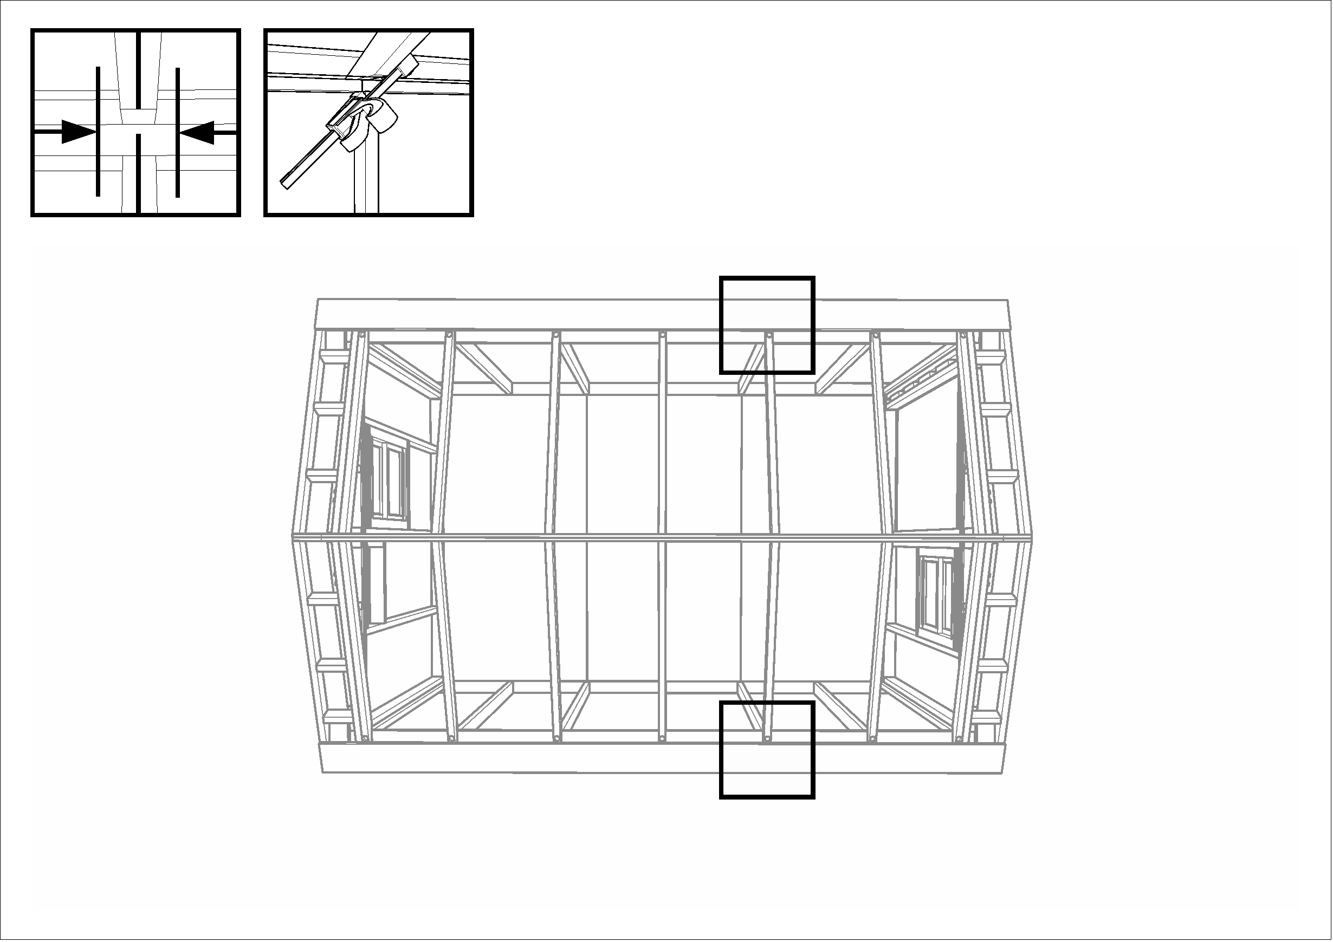
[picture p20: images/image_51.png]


{{< pagebreak >}}

*	Install lag bolts in these two rafters, screwing them down into the top plate of the side wall.

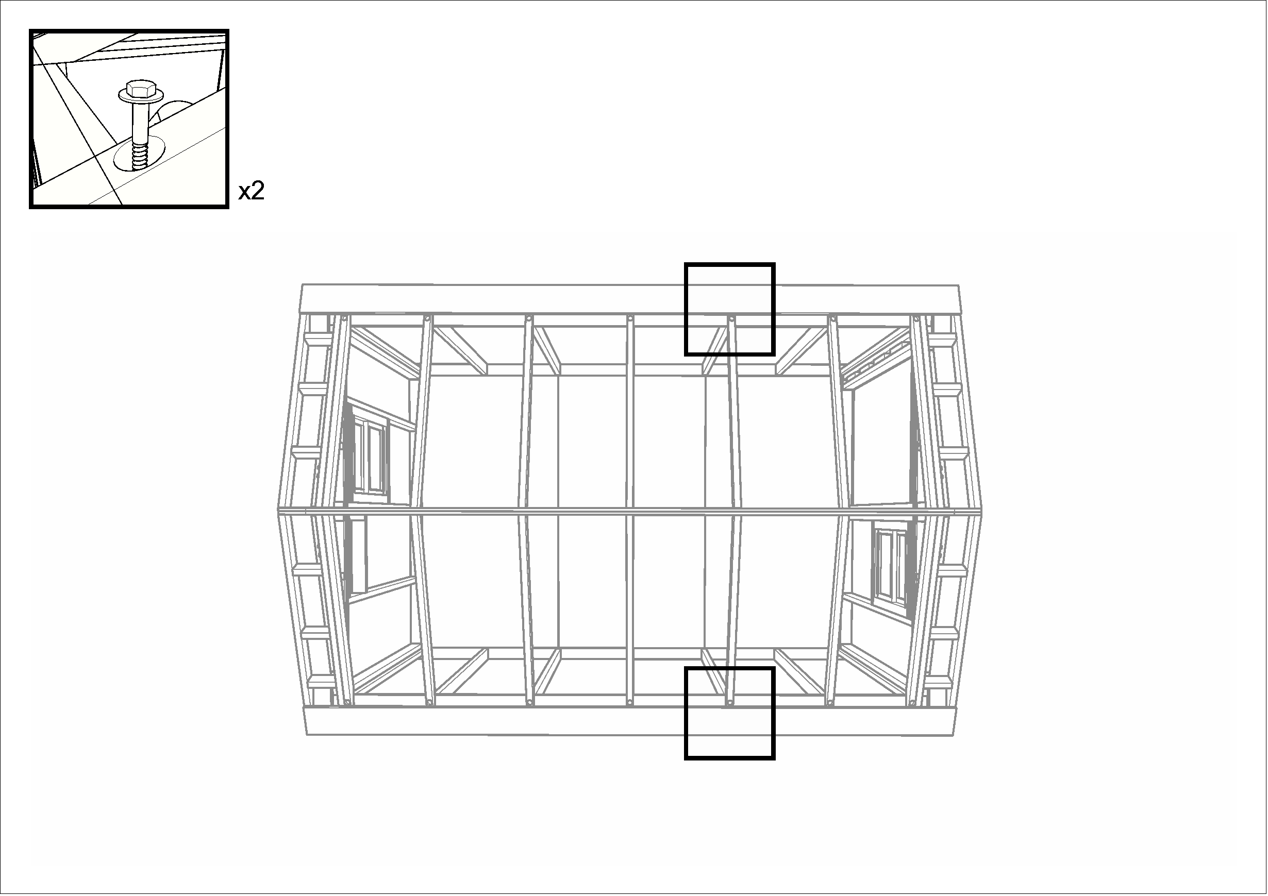
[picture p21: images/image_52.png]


{{< pagebreak >}}

*	At the peak of the roof, there are two steel brackets.  Install three galvanized hex-head screws in each bracket to secure the roof to the structural triangles.

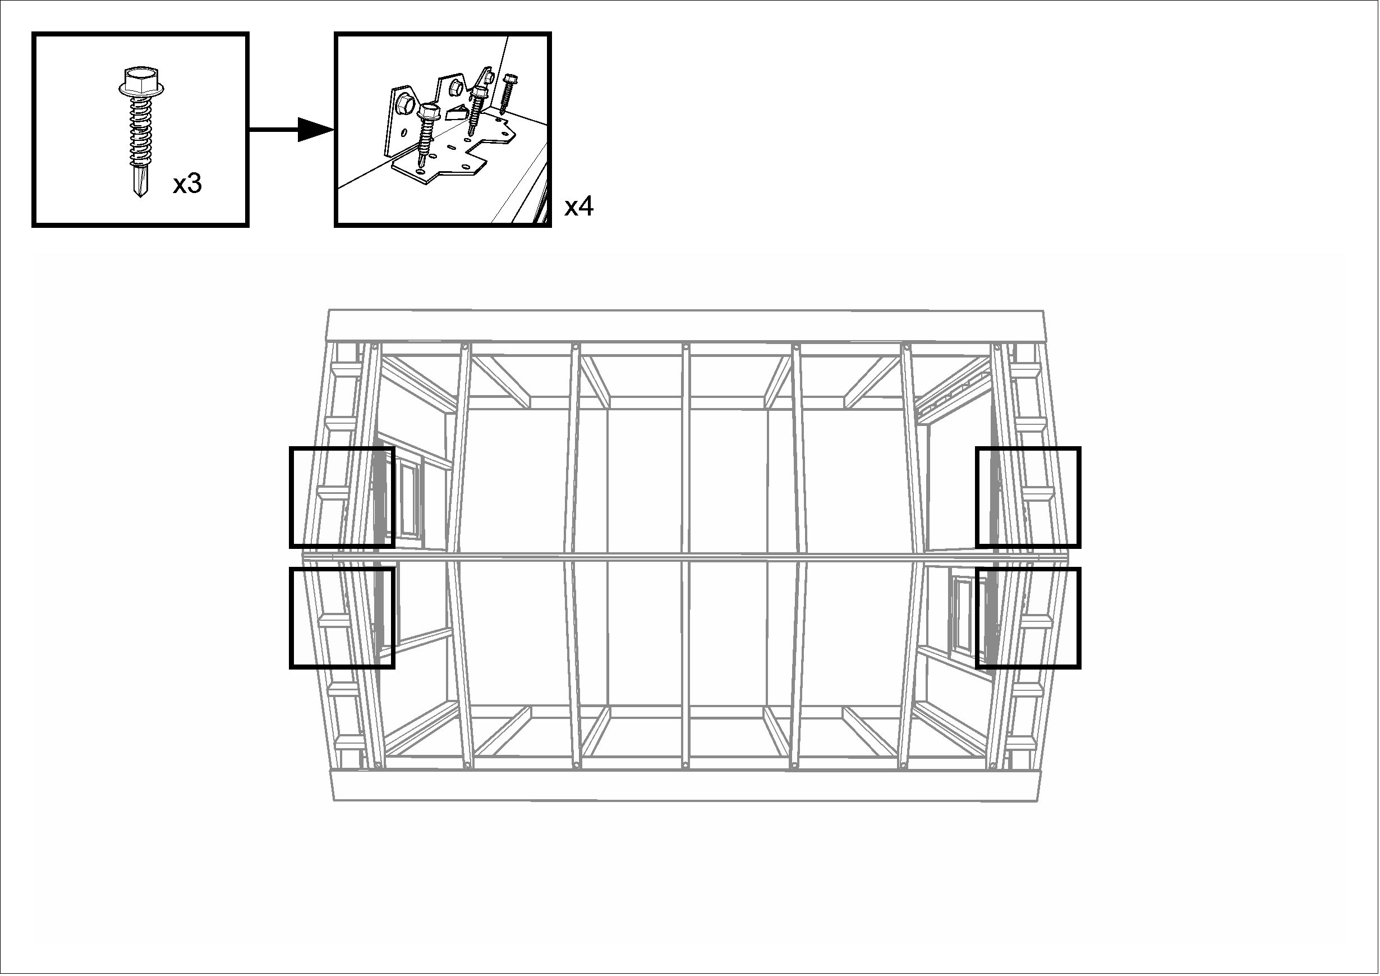
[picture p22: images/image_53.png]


{{< pagebreak >}}

*	After these brackets are secured, install lag bolts in all the other rafters.

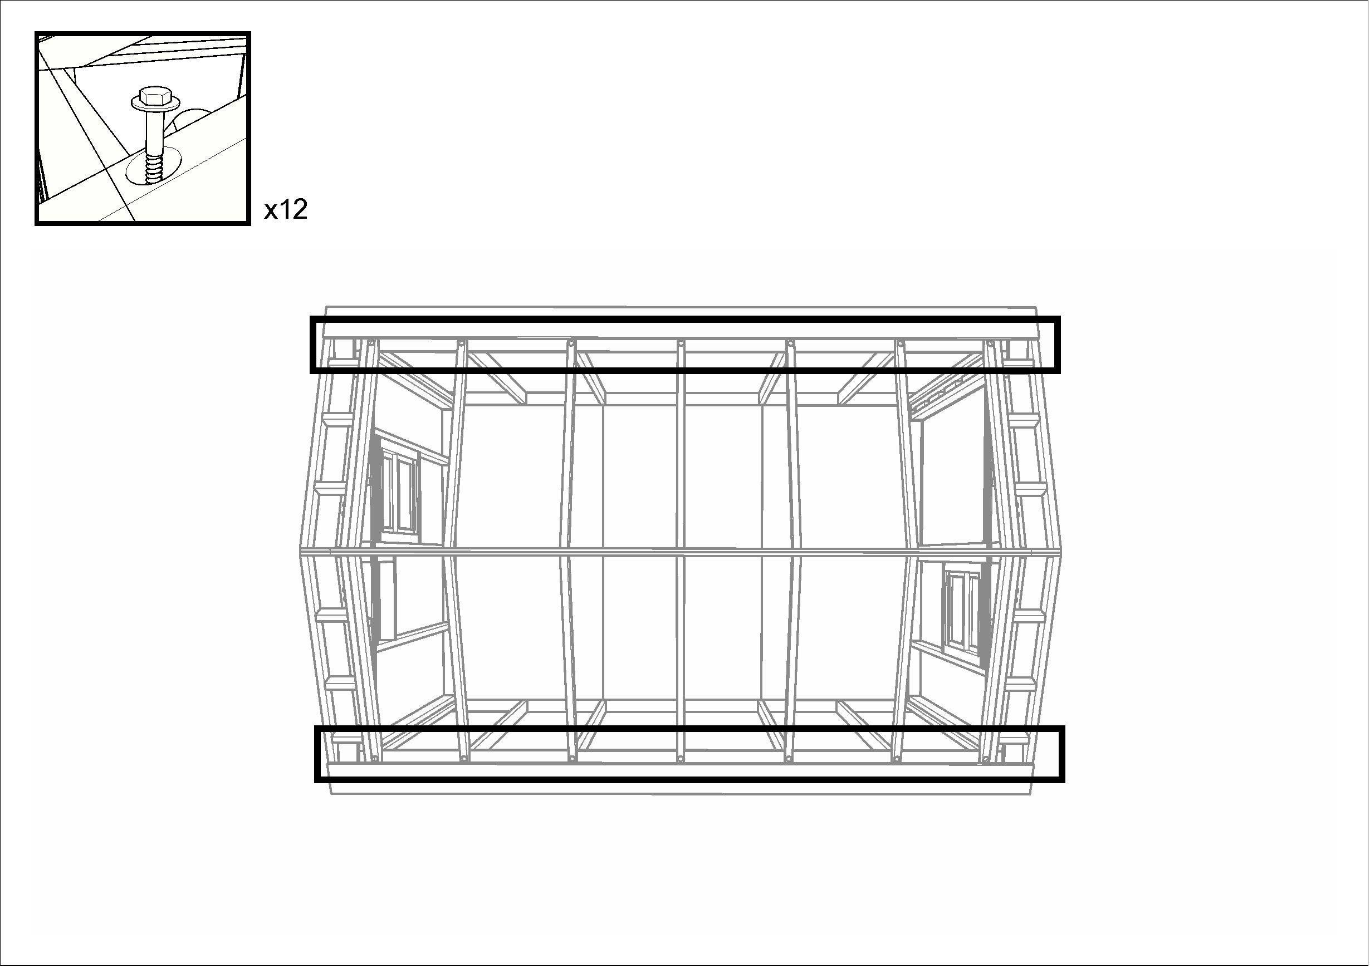
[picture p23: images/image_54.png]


{{< pagebreak >}}

# Install bird blocking

*	Collect a set of bird blocks from the tall shelves.  There should be four blocks labeled “E” (for the end bays) and eight blocks unlabeled (for the middle bays).
*	One crew member is stationed on a ladder outside the home; the other, inside, has a screw gun and a box of #10 x 3" screws.
*	The outside person positions each block, tapping gently with a mallet, so that it is flat against the top plate of the side wall, and tucked just under the edge of the white board at the bottom edge of the roof. If a block is shorter than the space between the rafters, it should be centered; if it is too long, cut it off with a chop saw

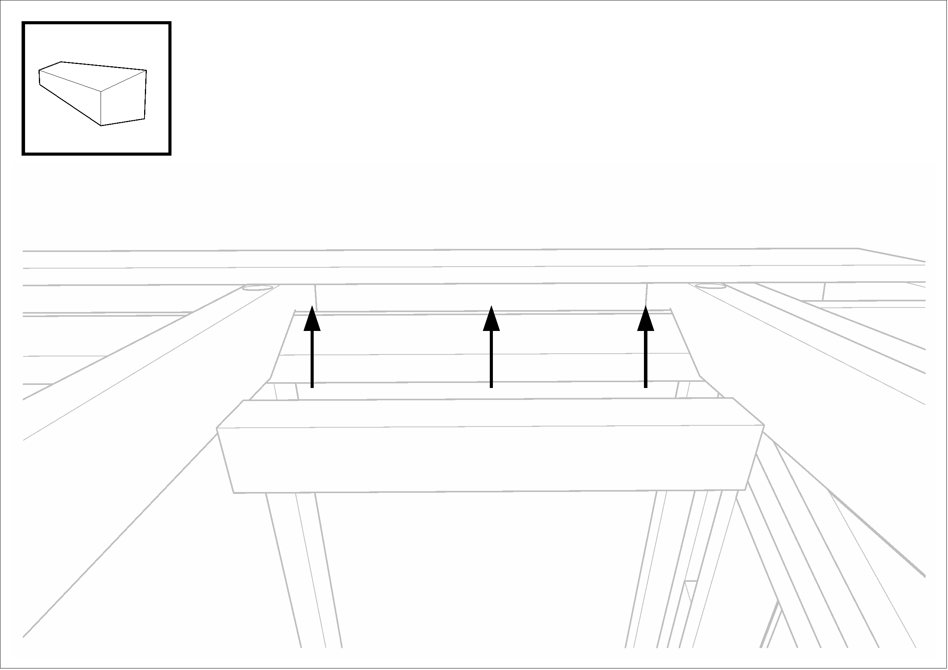
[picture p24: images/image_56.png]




{{< pagebreak >}}

*	When a block is in position, the inside person drives two brown screws up through the top plate of the side wall into the bird block.
*	The outside person then inspects the block to make sure that no screw ends are visible on the outside of the home.  If one is found protruding, it must be removed and reinstalled correctly.





{{< pagebreak >}}

# Install ridge vent blocks

*	Position a 1x8 white board (guide board) just down from the peak of the roof on one side; clamp it in place at both ends and in the middle.



*	Collect a set of vent blocks from the tall shelves.  There should be 4 marked “END” and 8 unmarked.
*	Preset three #10 x 3” screws in each vent block.



*	In each bay (between the rafters), position a vent block so that it just touches the guide board, clamp it in place, and drive the three screws into the white board.  If the vent block is too long, it can be cut off with a chop saw, but you may need to remove a screw for clearance.  It is important that the vent block end up tight against the white board.  If there is a gap, back the screws out, reclamp, and then drive the screws back in again.  This will ensure that the roof panels will actually fit when they are installed.



*	Move the guide board to the other side of the roof peak.
*	Install the remaining vent blocks on the other side of the roof peak.
*	Unclamp the guide board, and return it to the rack.



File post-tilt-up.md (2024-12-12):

# Secure walls to platform

* Equip two crews of two people with screw guns and brown #10 x 3” screws, and have them install 4 screws in each bay of all four walls, through the bottom plate into the platform, as shown in the diagram.

Secure walls - add 4 screws per bay

{{< pagebreak >}}

* Have one person install 5 #10 x 3” screws in each wall corner, to reinforce these corners

Secure Walls - front corners

Secure Walls - back corners

*	Using panel nails and working from the outside of the home, nail through the wall paneling into the base of the platform frame about 1” above the bottom of the paneling, every 8” all the way around the home.
*	Again, using panel nails and working from the outside of the home, nail the edges of the front and rear wall panels to the side-wall framing, about 1” in from the edges of the paneling, and 8” apart all the way from bottom to top of each corner.
*	Verify that the exterior paneling is nailed to the frame around the top and sides of the front door.  If not, nail that at this stage (every 8”).
*	Using a reciprocating saw (Sawzall), cut through the bottom plate of the front wall at each side of the doorway.  This should free the 2x4 so that it can be removed.  Use a knife to cut the Tyvek even with the top of the platform, and then use the Sawzall to cut the paneling at the bottom of the doorway so that it is flush with the top of the platform.
*	Using the angle-iron gauge (in the pencil cup in #4 workstation) and an ink marker, draw a line down the center of each of the “magic” studs.  These are the studs on the side walls at the rear of the second bay (4’ from the front wall).
*	Using a speed square, draw a 6” mark on the subfloor where the center of each stud is.  On the top plate of each wall, mark (freehand) where the center of each stud is.  These marks will be used by the people installing wall panels.
*	Using panel nails, nail the paneling to the platform across the bottom of the doorway.

{{< pagebreak >}}

# Install structural triangles

*	Position two 12-foot ladders, one at each end of the building.
*	Preset brown #10x3” screws in each of two structural triangles, as shown in the diagram a couple of pages on from here.  In the two center bays, there are four screws, angled enough that you could drive them in with an impact driver.  In the two outer bays, there are two screws angled in from one side of the triangle, starting about ¾” in from the edge of the bottom plate.  Then there are two screws driven in vertically about 1” toward the center from the seam between the bottom plate and the angled side of the triangle.

Structural Triangles - overview

{{< pagebreak >}}

*	Position a triangle on the front wall, and, with a helper inside the home, center it from side to side.

Structural Triangles - ensure center alignment

{{< pagebreak >}}

*	Verify that the bottom plate of the triangle is flush with the inside wall framing all the way across the front wall.
*	Clamp the triangle to the wall top plate (or door opening) about 6" from each end.

Structural Triangles - align flush with wall

{{< pagebreak >}}

*	From the ladder, drive all the preset screws into the wall framing to secure the triangle.
*	Repeat these last three steps on the rear wall.

Structural Triangles - drive screws into top plate

{{< pagebreak >}}

While these tasks are being completed, have two crew members position a half-roof assembly against each of the side walls, with the 1x8 white board at the bottom and facing away from the wall.  Check that there is a pencil line drawn at 6 ¼” from the front of the 1x6 board (the top of the half roof) all the way down and across what will be the bottom of the half roof when it is installed

Half Roof - crew positioning for left hand side roof

{{< pagebreak >}}

# Raise Half Roofs

*	Assign two experienced crew to the front and rear ladder positions.  Make sure each one has two clamps, a screw gun, and at least 4 yellow #8 x 1½" screws.
*	Assign a third crew member to a 3-step ladder inside the home, to assist in final positioning of each half roof.  Position this ladder between the studs, not aligned with a stud, to avoid having a roof rafter come down on the crew member’s head.
*	Introduce Funky Boards #3 and #4.
*	Gather the lifting crew; you will need 7 or 8 people
*	Explain to the rest of the crew how the half roof assemblies will be raised. Five or six people will lift the half roof up about 4 feet off the floor, and then two funky-board wielders will push it up so that the two ladder crew and the interior person can lift it the rest of the way up.  Warn these two to push up at a 45° angle, so that the half-roof slides onto the building instead of falling backwards onto the crew.  Remind the rest of the crew on the ground to take notes, because they will get to do the second half-roof.
*	Lift the first half-roof.

Half Roof - raise step 1

Half Roof - raise step 2

Half Roof - raise step 3

*	The ladder crew guide the 1x6 white board into the central notches in the structural triangles.  If necessary, the ladder crew may ask for help from the people on the funky boards, to lift (temporarily) the rafter ends either at the front or rear so that the half roof is properly positioned.
*	Then the front ladder person aligns the assembly so that the mark on the half-roof is even with the outer edge of the front structural triangle.

Half Roof - LHS ensure aligned with center beam

*	Rotate ground crew members who were standing out, and position everyone on the other side of the home for the second half roof lifting.
*	Once the ladder crew have repositioned their ladders, lift the second half roof into position.

Half Roof - RHS crew

Half Roof - RHS raise step 2

Half Roof - RHS raise step 3

{{< pagebreak >}}

*	The front ladder person leads the alignment of the two half roof assemblies, so that the ends of the 1x6 boards are flush.  Once this is done, both front and rear ladder crew clamp the 1x6 boards together both horizontally and vertically.  Placing the vertical clamp first allows the boards to slide past each other more easily before applying clamp pressure horizontally. Then drive 4 #8 x 1½ screws into the white boards, to secure the two halves together.

Half Roof - check both halves align

Half Roof - clamp and screw first segment

{{< pagebreak >}}

# Screw ridge boards together to create center beam

*	In each bay (between the rafters), clamp the two white boards together, first vertically and then horizontally, to align them and make a tight joint.
*	insert four #8 x 1½" (yellow) screws, two above and two below the centerline, and about 4” from the rafters.  Alternate directions of the screws from one bay to the next.

Half Roof - clamp and screw first segment

Half Roof - clamp and screw segment

{{< pagebreak >}}

# Secure half-roof assemblies

*	Using the angle-iron guide in Station #4, mark the centerline of the “magic” rafters; these are the ones to the rear of the second bay.
*	Align the “magic” rafters with the stud just below them.  Using a clamp, pull each of these rafters either forward or back so that it lines up exactly with the wall stud immediately below it.  If necessary, have a second person use a mallet to assist.  The place to aim the mallet is on the end rafter at the point where the lowest block is screwed to the rafter.  If you hammer on the rafter end, something will split.

Half Roof - mark magic rafters

*	Install lag bolts in these two rafters, screwing them down into the top plate of the side wall.

Half Roof - add lag bolts

*	At the peak of the roof, there are two steel brackets.  Install three galvanized hex-head screws in each bracket to secure the roof to the structural triangles.

Half Roof - secure brackets

*	After these brackets are secured, install lag bolts in all the other rafters.

Half Roof - secure brackets

{{< pagebreak >}}

# Install bird blocking

*	Collect a set of bird blocks from the tall shelves.  There should be four blocks labeled “E” (for the end bays) and eight blocks unlabeled (for the middle bays).
*	One crew member is stationed on a ladder outside the home; the other, inside, has a screw gun and a box of #10 x 3" screws.
*	The outside person positions each block, tapping gently with a mallet, so that it is flat against the top plate of the side wall, and tucked just under the edge of the white board at the bottom edge of the roof. If a block is shorter than the space between the rafters, it should be centered; if it is too long, cut it off with a chop saw

Bird Blocking - position

Bird Blocking - tap block into place

*	When a block is in position, the inside person drives two brown screws up through the top plate of the side wall into the bird block.
*	The outside person then inspects the block to make sure that no screw ends are visible on the outside of the home.  If one is found protruding, it must be removed and reinstalled correctly.

Bird Blocking - secure block with screws

Bird Blocking - all positions

{{< pagebreak >}}

# Install ridge vent blocks

*	Position a 1x8 white board (guide board) just down from the peak of the roof on one side; clamp it in place at both ends and in the middle.

Vents - clamp guide board

*	Collect a set of vent blocks from the tall shelves.  There should be 4 marked “END” and 8 unmarked.
*	Preset three #10 x 3” screws in each vent block.

Vents - preset screws and position

*	In each bay (between the rafters), position a vent block so that it just touches the guide board, clamp it in place, and drive the three screws into the white board.  If the vent block is too long, it can be cut off with a chop saw, but you may need to remove a screw for clearance.  It is important that the vent block end up tight against the white board.  If there is a gap, back the screws out, reclamp, and then drive the screws back in again.  This will ensure that the roof panels will actually fit when they are installed.

Vents - clamp

*	Move the guide board to the other side of the roof peak.
*	Install the remaining vent blocks on the other side of the roof peak.
*	Unclamp the guide board, and return it to the rack.

Vents - clamp

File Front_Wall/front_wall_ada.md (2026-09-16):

```{=typst}
#title-page[
  #text(36pt, weight: "bold")[Front Wall]
  #v(1em)
  #text(24pt)[Jig Instructions]
]
```

# FRONT WALL - SET UP LIST

- Put caulk by heater
- Caulking gun
- Framing nail gun
- Framing nails
- Panel nails
- Triangle
- Long Screws (brown)
- Short Screws (yellow)
- Screw gun with T25 bit
- Chalk line
- Stapler
- Staples
- Mallet
- Hammer

`#pagebreak()`{=typst}

## Step 1

- Place 2x4s in the designated spots on the perimeter.
- Line up the corners to be flush on top and sides
  - one person holds and the other nails.
- Put 1 FRAMING nail (the longer ones) in the upper middle of the stud to connect the corners.
- Check the perimeter squareness, by measuring the diagonal distance both ways. These should be equal. If not, adjust.
-  Put a second nail directly under each of the first nails in each corners.

#### HAZARDS:
- Bashed fingers: Keep fingers 6" from mallet
- Nail Injury: Keep fingers 12" from joint

`#fullpage("images/front_wall_ada.dxf", layers:"Framing,step_01")`{=typst}

## Step 2
- Place
  - inner 2 long 2x4s on both sides of the window area
  - 4 short 2x4s as shown
  - 3 short at the top and 1 in the middle.
- Clamp the 3 short boards at the top.
- Nail into both sides of the 3 short boards
  - 3 inside pointing out and 3 outside pointing in
- Squeeze the long boards (studs) up against the 3 short boards and put one nail through
 the stud on each side into the ends of each of the short boards.
- Put 2 nails into each end of the short 2x4 in the middle (through the studs at the bottom of the window opening).

#### HAZARDS:
- Bashed fingers: Keep fingers 6" from mallet
- Nail Injury: Keep fingers 12" from joint

`#fullpage("images/front_wall_ada.dxf", layers:"Framing,step_02")`{=typst}

## Step 3

- Team leader: When boards are in place, draw a straight vertical line on the top and bottom plates at the middle of each stud to indicate
where to put the nails
- Place the next stud as shown and clamp it to the adjacent stud.
  - Clamp **tight** on bottom of two middle studs
  - If clamping does not make the joint tight, use 3" brown screws to force the two studs together below the window.
  - Nail these two studs together in three places below the window opening from the side opposite the window.

- Secure all 3 studs on both sides of the window to the top plate
  - Use a clamp to squeeze any gap between the double studs near the top
  - 2 nails through the top plate into each stud
  - 2 nails through the bottom plate only into the single stud farthest from the door opening.

#### HAZARDS:
- Bashed fingers: Keep fingers 6" from mallet
- Nail Injury: Keep fingers 12" from joint
- Ladder Fall: Ascend/descend ladder without carrying tools

`#fullpage("images/front_wall_ada.dxf", layers:"Framing,step_03")`{=typst}

## Step 4

- Place 2 long boards (studs), one on either side of the door opening, and two header blocks
**and a plywood spacer** between them above the door opening.
- Push the long blocks above the door opening toward the window, and clamp them to the top plate.
Nail as shown: 3 nails down through the top plate, and 3 nails up through the blocks.
- **Do not** nail into the ends of the studs on either side of the door opening. That will come in the next step.

#### HAZARDS:

- Nail Injury: Keep fingers 12" from gun end

`#fullpage("images/front_wall_ada.dxf", layers:"Framing,step_04")`{=typst}

## Step 5

- Clamp the 3 studs in the center of the wall together, being certain that there is no gap, and nail as shown:
  - 3 nails from the window side, all below the window
  - 3 nails from the door side evenly spaced along the length of the stud. If there is any gap between the new stud and the two closer to the window,
drive a 3" brown screw into the stud nearest the door and tighten it to remove that gap.
- Place 4 spacer blocks between the outer wall stud and the door-opening stud. Leave an 8" space above the top block and below the bottom block.
Clamp each block between the two studs, and nail twice from each side.

#### HAZARDS:
- Nail Injury: Keep fingers 12" from gun end

`#fullpage("images/front_wall_ada.dxf", layers:"Framing,step_05")`{=typst}

## Step 6

- Insert the doorway stretcher into the doorway near the bottom, and make certain that the doorway is wide enough.
- Nail twice through the top plate and twice through the bottom plate into the studs on either side of the door opening.
- Nail twice through the bottom plate into the other two middle studs.
- Check the perimeter to be sure all the long studs have 2 nails at each end.
- Remove the doorway stretcher, and save it for the next wall crew.

#### HAZARDS:

- Nail Injury: Keep fingers 12" from gun end

`#fullpage("images/front_wall_ada.dxf", layers:"Framing,step_06")`{=typst}

## Step 7

- Line the Tyvek up to be flush with the top and overlap about 6" on the sides (outside the 2x4 guide posts).
- Roll out the Tyvek a few feet at a time, align the edge with the top plate, and staple 8" apart along the top plate, pulling it tight
  - at the end of the top, cut off the roll with about 6 inches extra on the side.
- Staple around the perimeter going around in a circle pulling gently so that the Tyvek is tight.
- Staple along ALL inner studs, and across the top and bottom of the window opening and across the top of the door opening.

#### HAZARDS:
- Staple Injury: Keep fingers 12" from stapling point

`#fullpage("images/front_wall_ada.dxf", layers:"Framing,step_07")`{=typst}

## Step 8
- Cut the Tyvek out along the inside edge of the window.
- Install peel-and-stick flashing around the window opening
  - Using the pattern board, cut two "inner long" pieces and two "inner short" pieces
  - Apply one of the short lengths of flashing to the bottom of the window opening with about half of the flashing sticking up above the framing,
wrapping the ends around the corners. Make sure that the flashing does not get stuck on the jig brackets
  - Be sure to press the flashing into each of the corners completely
- Use a knife to slit the flashing where it sticks up above the frame at each corner, and then fold the free section out over the frame and Tyvek.
- Apply a longer piece of flashing to each side of the window opening in the same way.
- Finally, apply the remaining short piece of flashing to the top of the window opening
- Cut 4 small pieces of the same flashing, and place one diagonally over each corner,
as shown in the drawing. Force the end down into the corner of the window opening.

**--- IMPORTANT** --- Be sure to put the flashing [ABOVE]{.underline}, not on the brackets of the jig.

- Cut the Tyvek out along the inside edge of the door opening. Save the cut-out piece; it can be used to create structural triangle covering later.

#### HAZARDS:
- Knife cut: Keep fingers clear of where the knife might slip

`#fullpage("images/front_wall_ada.dxf", layers:"Framing,step_08")`{=typst}

## Step 9
- Place Panel 1 with window cut out. Align with top edge of frame and side stops.
- Nail (PANEL NAILS)
  -   along top, sides and internal stud below the window.
  -   use chalk lines
  -   DO NOT nail around the window
- Caulk along the tongue edge of Panel 1.
- Place Panel 2, taking care that the joint between panels engages fully.  Line panel up with top of frame.
- Team Leader: Use a ladder to climb onto the siding, and, using your body weight to press the seam down, nail every 8" along the joint.
Keep nail heads ½" away from the seam to avoid splitting the siding. This probably means nailing at about a 30° angle, so that the nails
anchor into the frame, and do not split the edge of the 2nd panel.
-  Nail (PANEL NAILS)
  - along top and sides
  - use chalk lines
  - **DO NOT NAIL BELOW THE DOOR**
- Install three #8 (yellow) screws through the siding into the bottom plate.  Be sure these do not stick up above the panel; they will interfere with the router.  These screws will be removed after the wall is tilted up.

#### HAZARDS:
- Nail Injury: Keep fingers 12" from joint
- Ladder Fall: Ascend/descend ladder without carrying tools

`#fullpage("images/front_wall_ada.dxf", layers:"Framing,step_09")`{=typst}

## Step 10
- Team leader: Bore a hole through the siding where the arrows on the jig indicate, and rout out the door opening (do this now,
  to avoid fouling the router plate with caulk later.)
- Prepare the window. Remove all the labeling, and fully open the window. Set it screen-side down on the paneling.
- Apply caulk to the window flanges on the top and both sides
  - NOT at the bottom.
  - caulk line should be outside the line of slots in the window flange
  - caulk on the opposite side from the screen (the surface that will lie on the panel)
- Place the window in the opening
  - latch side down into the opening
  - Push the window either up or down to contact the framing, so that it is aligned, and then push the other way about 1/2",
    so that it will be possible to fit foam backer rod all the way around the window later.
- Put SHORT SCREWS around the window.
  - 4 on each side and 3 on the top and bottom.
- Team leader: Using a piece of 1x4 trim, draw a pencil line on all four sides of the window to show where the trim will go.
- Put flexible flashing around 3 sides of the window
  - **NOT** on the bottom of the window
  - Using the pattern board, cut two pieces “outer long” and one piece “outer short”
  - Place all flashing FLUSH against the corner stops on the window. It is not necessary for the flashing to be tight all the way down the window sides
  - Make sure the flashing does not extend over the pencil outline

`#fullpage("images/front_wall_ada.dxf", layers:"Framing,step_10")`{=typst}

## Step 11
- Pry gently on the top and bottom plates to raise the wall out of the jig, and place blocks under these boards.
- Staple Tyvek to underside of panels on the bottom and both sides. Trim Tyvek on all 3 sides.
- Nail every 8" on the two sides and top of the door opening.
- Caulk all nails after tilt-up.

`#fullpage("images/front_wall_ada.dxf", layers:"Framing,step_11")`{=typst}

# FRONT WALL CHECKLIST

1.  Perimeter 2x4s --- nail corners
2.  2x4 studs next to window
3.  3 short 2x4s above window --- CLAMP, nail
4.  1 short 2x4 below window, nail
5.  2 nails at both ends of long 2x4s next to window
6.  Inner studs
7.  CLAMP double studs - 2 nails **BELOW** window ONLY
8.  Small 2X4s over door, nail
9.  3^rd^ 2x4 stud in center of wall; nail
10. 4 small blocks at right side of door using CLAMP
11. 2 nails at the ends of all long studs
12. Tyvek staple perimeter and inside studs
13. Cut out Tyvek for window and door
14. Peel & Stick edge of window **(NOT** on jig brackets)
15. Panel 1 with window hole, nail (PANEL NAILS)
16. Caulk edge of panel 1
17. Panel 2 nail top, sides and internal studs **NOT below door**
18. Caulk edge of window, and place window into opening
20. Short SCREWS --- 4 on sides, 3 top and bottom
21. Rout door opening
22. Peel & stick 3 edges of window, **NOT** under window
23. Staple and trim Tyvek
24. Nail panel along sides and top of door opening
25. Caulk nails after tilt-up

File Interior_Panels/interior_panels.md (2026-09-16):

```{=typst}
#title-page[
#text(36pt, weight: "bold")[Interior Panels]
  #v(1em)
  #text(24pt)[Jig Instructions]
]
```

# INTERIOR PANELS

## Tools and supplies
- 2 3-step ladders
- 2 Screw guns, with T25 bit
- Power drill, with countersink bit
- Pry bar
- Pencil (to mark on ceiling and wall panels)
- Funky Boards #3 & #4 (T-bars for ceiling panels)
- Screw pattern boards (42" and 84")
- A/C cutout locator jig
- Work light
- 3" #10 screws (brown)
- 2" #8 screws (yellow)
- Panel cart with most of the cut and labeled interior panels
- 4 plywood half-triangle panels (2 left-hand and 2 right-hand)

`#pagebreak()`{=typst}

## Pre-Install Quality Checks

- Walk around the outside of the home and check if any screw ends are visible through the bird-blocks.  If any are found, remove and re-install correctly.
- Make sure all insulation is installed including the small spaces next to the door and in all the odd-shaped spaces in the structural triangles.
- Make sure that the reference line is marked on the 2^nd^ stud and 2^nd^
rafter back from the door. If not, mark these with felt-tip pen, using angle-iron guide.
- Inspect the vent blocks, to make sure that the plywood spacers are tight against the white boards at the peak of the ceiling. If light shows
between the vent block spacers and the white board, unscrew the brown screw at that spot, use a clamp to tighten the vent block, and re-drive
the brown screw into the vent block. 

## CEILING Panels R1 & R2 (two each)

**Use pencil only to mark on panels.  Ink markers cannot be painted over very easily.**

1. **Pre-drill** (this is important)
  - drill ½" to ¾" from the edge, slant drill slightly to the outside edge
1. Pre-set **LONG** screws
1. Install panels (Requires extra people)
    - Install R1s
      - at the back, factory edge on the interior stud line
      - tight up against the vents; use crowbar
    - Install R2s
      - factory edge at interior stud line up against R1
      - tight up against the vents; use crowbar

1. -- (**BEFORE WALL PANELS)** Inner ceiling panel screws
    - Use Screw Pattern Board to mark WITH PENCIL (**[NOT]{.underline}** marker) where the screws go. Align with visible rafter end at the top,
    and with marks on wall top plate.
    - Pre-drill and screw in **LONG** screws at each marked location.

`#fullpage("images/ceiling_panels.dxf", layers:"Panels,Notes")`{=typst}

## SIDE WALL Panels A, B & C

1. **Pre-drill** (this is important)
    - drill ½" to ¾" from the edge, slant drill slightly to the outside edge
1. Pre-set **SHORT** screws
1. Install B panel first
    - at the back of side wall, on the floor, with factory edge on the interior "magic" stud line
    - drive in screws at the "magic" stud first, then at the back corner.
    - at each interior stud, pre-drill and install a short screw 3/4" below the panel edge, to identify the stud locations as well as to hold the panel flat against the framing.
1. Install A panel
    - at the back of side wall, on top of B, with factory edge at interior "magic" stud line
    - make certain that the edges of A and B at the interior stud line are lined up exactly, and drive preset screws in, first at the "magic" stud, and then at the rear of the home.
    - pre-drill and install one screw at the bottom of the panel above the matching screw in the B panel below.  Be certain that the seam between the A and B panels is flat.  If not, you may need to loosen screws at one end of the panel, and reset the A panel so that it matches the B panel.
1. Install C panel
    - line up snug against A and B
    - drive in two screws at the top and two at the bottom along the seam first.  Then drive in screws at the front corner, and drive in the rest of the screws along the seam.

    REPEAT Steps 3, 4, and 5 on other side wall

1. Inner panel screws
    - Use Screw Pattern Board labeled "2 Down, 3 Up" to mark WITH PENCIL (**[NOT]{.underline}** marker) where the screws go.
    - For Panel B, use the installed screw and a mark on the floor, for a total of 4 screws per stud.
    - For panel A, use mark on top plate and installed screw on panel B as a guide, for 5 screws total per stud.
    - There is a separate long (84") Screw Pattern Board for Panel C.
    - Pre-drill and screw in **SHORT** screws.  If these screws cannot be made to sink into the framing behind the panel, you may use a brown 3" screw.

`#fullpage("images/wall_panels.dxf", layers:"01_Side_Panels")`{=typst}

## BACK WALL Panels G & H 

1. - **Pre-drill** (this is important)
    - drill ½" to ¾" from the edge, slant drill slightly to the outside edge
1. Pre-set **SHORT** screws
1. Install H panel
    - on the back wall, resting on the floor
    - at each interior stud, pre-drill and install a short screw ¾" below the panel edge, to mark the stud locations.
1. Install G, making sure the back window is OPEN
    - at the back wall on top of H
    - The window opening will be routed out later.
1. Inner panel screws
    - Use Screw Pattern Board labeled "2 Down, 3 Up" to mark WITH PENCIL (**[NOT]{.underline}** marker) where the screws go.
    - For Panel H, use the installed screw and a mark on the floor for alignment, for a total of 4 screws per stud.
    - For panel G, use mark on top plate and installed screw on panel H as a guide, for a total of 5 screws per stud.
    - On either side of the eventual window cutout, mark for screws every 8" instead of using the Screw Pattern Board. This should come
      out to 7 screws on each side of the window framing on panel G.
    - Pre-drill and screw in **SHORT** screws

`#fullpage("images/wall_panels.dxf", layers:"02_Rear_Panels")`{=typst}

## FRONT WALL Panels D & E

1. **Pre-drill** (this is important)
    - drill ½" to ¾" from the edge, slant drill slightly to the outside edge on the sides that will form corners with the side walls. On Panel E, drill perpendicular to the panel on the door side
    - Pre-set **SHORT** screws
1. Install E on the front wall, resting on the floor. Line up the edge of the panel with the door frame
    - at each interior stud, pre-drill and install a short screw ¾" below the panel edge, to mark the stud locations and secure the panel to the framing.
1. Install D, making sure the front window is OPEN
    - over the window and the top half of the doorway, on top of E
1. Inner stud screws
    - Use Screw Pattern Board labeled "2 Down, 3 Up" to mark WITH PENCIL (**[NOT]{.underline}** marker) where the screws go.
    - For Panel E, use the installed screw and a mark on the floor, for a total of 4 screws per stud.
    - For panel D, use mark on top plate and installed screw on panel E as a guide, but mark screw positions every 8" on either side of the door frame,
      and either side of the window frame.
    - Pre-drill and screw in **SHORT** screws
1.  Rout out the door (first), the windows, and the A/C cutout
    - Using a spade bit, drill from outside through the paneling, near the bottom left corner of each window
    - After the back window is routed out, use the A/C cutout jig to locate the drill spot, and drill a starter hole
1. Find and install a 4" piece of ½" plywood that goes below the remaining edge of the D panel on the narrow side next to the doorway.
    - This piece is 38¼" long and 4" wide, and may be found in a square barrel where the trim pieces are kept.  It may alternatively labeled **E2**.
      - Pre-drill along the long edges about 8" apart.
      - Install, making sure that the edge next to the doorway aligns with the routed doorway above it.

`#fullpage("images/wall_panels.dxf", layers:"03_Front_Panels")`{=typst}

## Triangle Panels

1. Pre-drill each panel along the edges as indicated in the diagram.
    - be certain to drill from the good side of the plywood, and insert screws from this side.
    - drill ½" to ¾" from the edge; on the long diagonal edge, slant the drill slightly toward the outside of the panel.
    - on the other two edges, drill perpendicular to the panel.
    - preset **short** screws in all the drilled holes, making sure to insert them from the good side of the panel.
1. Install the first half-triangle on the front or rear wall
    - set the half-triangle right on the top edge of the wall panel.
    - line up the shortest edge with the center of the roof beam.
    - This alignment will leave a gap near the ceiling.  This gap will get covered by the trim.
1. Install the second half-triangle next to the first, being sure to line it up tight against the half-triangle already in place.
1. Repeat on the rear or front wall.

`#pagebreak()`{=typst}

`#fullpage("images/wall_panels.dxf", layers:"04_Triangle_Panels")`{=typst}

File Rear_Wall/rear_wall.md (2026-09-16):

```{=typst}
#title-page[
  #text(36pt, weight: "bold")[Rear Wall]
  #v(1em)
  #text(24pt)[Jig Instructions]
]
```

# REAR WALL - SET UP LIST

- Put caulk by heater
- Caulking gun
- Framing nail gun
- Framing nails
- Panel nails
- Triangle
- Drill motor with spade bit
- Screw gun with T25 bit
- Long screws
- Short screws
- Chalk line
- Stapler
- Staples
- Mallet
- Hammer
- Pry bar

`#pagebreak()`{=typst}

# Step 1

- Place 89" 2x4s on the jig for the top and bottom of the wall.
- Select the straightest 84" 2x4 board (stud), and reserve it for Step 4.
- Place 84" 2x4 studs on the jig for each side of the wall.
- Line up the corners to be flush on top and sides
    - one person holds and the other nails.
- Put 1 FRAMING nail (the longer ones) at each corner through the top and bottom 2x4s to connect the corners, about 1/3 of the way down
- Check that the perimeter is square by measuring the diagonals; they should be the same
- Put a second nail directly under each of the first nails, about 2/3 of the way down

`#fullpage("images/rear_wall.dxf", layers:"Framing,step_01")`{=typst}

# Step 2

- Place 2 studs (84") into the jig, one on either side of the window opening. If studs are bowed, place so that bow is to the inside of the window area.
- Team leader
    - When studs are in place, draw a straight vertical line at the middle of each stud to indicate where to put the nails.
- Place
    - 3 short 2x4s at the top of the window opening (if one is shorter, put it in the middle of the set of three)
    - 1 short 2x4 at the bottom of the window opening
- Push the 3 short boards away from the center of the wall against the stud, and clamp them and the top plate together.
- Nail these short boards to the top plate
    - 3 nails through the top plate into the top of the 3 boards
    - 3 nails inside pointing out
- Squeeze the studs up against the 3 short boards and put one nail through the stud into each short board. Repeat on the other end.
- Put 2 nails into both endseach end of the short 2x4 in the middle (at the bottom of the window).
    - make sure that the short board is flush with the studs before nailing each end

`#fullpage("images/rear_wall.dxf", layers:"Framing,step_02")`{=typst}

# Step 3

- Secure the studs on both sides of the window
  - 2 nails into each stud at the top
  - 2 nails into those same studs at the bottom
- Place next stud as shown in diagram
- CLAMP and put 3 nails into the double studs
  - ONLY in the lower half BELOW the window.
- Put 2 FRAMING nails at each end of this stud, through the top and bottom plates, on the marked lines.

`#fullpage("images/rear_wall.dxf", layers:"Framing,step_03")`{=typst}

# Step 4

- Place the straight stud selected in Step 1 between the double stud
    and the wall edge, as shown in the diagram.
- Place a 20-1/2" block horizontally against the top plate, as shown
    in the diagram. Clamp it in place, and nail it to the top plate (2 nails).
- Place a 13-3/4" block vertically against the double stud and up against the block above.
Clamp it to the double studs and nail it to these studs (2 nails).
- Place a second 20-1/2" block horizontally below the vertical block as shown, and nail it to this block (2 nails), and then through the newly
  installed stud (2 nails), as shown in the diagram.  Make certain that the block is flush with the surface of the stud.
- Finally, put two nails through the top plate and two nails through bottom plate into the new stud.

`#fullpage("images/rear_wall.dxf", layers:"Framing,step_04")`{=typst}

# Step 4b
- There should be a crate of blocks under the jig.  If not, cut blocks from under the front chop saw in half for this step.
- Position a 6½" block on each side below the air conditioner opening as shown in the diagram, and nail each block to the adjacent stud with 2 nails.
- Position a third 6½" block next to the one on the window side, and nail this block
 to its neighbor, again with two nails

`#fullpage("images/rear_wall.dxf", layers:"Framing,step_04b")`{=typst}

# Step 5
- Place the Tyvek roll along the window side of the frame, and roll out a few feet.
- Line the Tyvek up to be flush with the top and overlap about 6" on the sides, so that the Tyvek extends beyond the alignment posts
  on the window side of the jig.
- Roll out a few feet at a time and staple 8" apart along the top plate, pulling the Tyvek
  so that it will be tight. When you reach the other end of the wall, cut off the roll OUTSIDE the alignment posts, leaving about 6" extra on the side
- Staple around the perimeter pulling so that it is tight
- Staple along ALL of the inner studs, across the top and bottom of the window, and across the bottom of the A/C blocking

`#fullpage("images/rear_wall.dxf", layers:"Framing,step_05")`{=typst}

# Step 6

- Cut out the Tyvek where the window goes on all 4 sides
- Using the pattern board, cut flexible flashing for the sides and top and bottom of the window opening ("inner long" and "inner short").
- Put flashing around the window opening.
    - half of each strip sticks up above the framing
    - flashing wraps around the corners
    - use a knife to slit the flashing above the frame at each corner, and fold down (or out) over the Tyvek.

**IMPORTANT** --- Be sure to put the flashing [ABOVE]{.underline}, not on the brackets on the jig.

- Add 4 small pieces of flashing at the corners of the window, as shown in the figure, to reinforce the corners

`#fullpage("images/rear_wall.dxf", layers:"Framing,step_06")`{=typst}

# Step 7

- Place Panel 1 with window cut out
    - align top of panel with top plate of frame
    - align outside edge with the alignment posts
- Nail (PANEL NAILS)
    - along top, outside edge, bottom, and internal stud below the window every 8"
    - use chalk lines
    - DO NOT nail around the window or on center edge
- Caulk along the center edge of Panel 1.
- Place Panel 2
- Nail (PANEL NAILS)
    - along top every 8"
    - Using body weight, seal the center seam and nail at an angle, about ½" away from the panel edge
    - along outer edge, bottom, and internal stud, every 8"
    - use chalk lines
- Position the A/C nailing template over the top center of the wall, against the jig stop marked, and make pencil marks
  at the spots indicated at the edges of the template. Nail (PANEL NAILS) at each mark.

`#fullpage("images/rear_wall.dxf", layers:"Framing,step_07")`{=typst}

# Step 8

- Place the window screen-side down on a convenient spot on the wall.
    - apply caulk on the opposite side from the screen, the edge that will lie on the panel. Caulk only the sides and the top, NOT on the bottom flange
    - caulk line should be just inside the line of slots in the window flange
    - Tip the window into the window opening, latch side down, taking care to avoid getting caulk on fingers or gloves.
    - Push the window up and toward the wall edge to contact the framing, so that it is aligned, and then push the other way about 1/2",
    so that it will be possible to fit foam backer rod all the way around the window later.  Alignment is easiest if, when the window is pushed
    against the frame, you use a pencil to mark both ends of the top and outer edge before centering the window.
- Put SHORT SCREWS around the window
    - 4 on each side and 3 on top and bottom
- Team leader: Using a piece of 1x4 trim, draw a pencil line on all four sides of the window, to show where the trim will go
- Put flexible flashing flat on 3 sides of the window.
    - Using the pattern board, cut two "outer long" pieces and one "outer short" piece.
    - Align each piece against the corners of the window, sides first, then the top
    - Make sure it does not extend beyond the pencil lines
    - NOT on the bottom of the window
- Gently pry the top and bottom plates to raise the wall out of the jig, and place blocks under these boards.
- Staple Tyvek to underside of panel, both sides and bottom, being sure that the staples go into the thicker part of the siding, not into
  the tongue or into the grooves.
- Trim Tyvek on both sides and bottom
- Caulk all nails after tilt-up

`#fullpage("images/rear_wall.dxf", layers:"Framing,step_08")`{=typst}

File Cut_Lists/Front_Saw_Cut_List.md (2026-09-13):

---
no-title-page: true
---

# FRONT SAW CUT LIST: CUT FOR 2 HOMES

On a single lumber cart, cut these lengths of 2x4:

| Quantity | Dimensions | Notes |
| --- | --- | --- |
| 4 | 2x4x89 in | Use 8' 2x4 |
| 30 | 2x4x84 in | Use 8' 2x4 |
| 8 | 2x4x24 in | Use 8' 2x4 |
| 2 | 2x4x13¾ in | Use 8' 2x4, or scrap |
| 4 | 2x4x20½ in | Use block from Back Saw, or scrap |

`#v(4em)`{=typst}

# 1x4 TRIM -- SHIPMENT

From 12' material, cut parts in this order:

| Length | Use | Notes |
| --- | --- | --- |
| 94¼" | Corner Board | Save cutoff pieces, in 4 equal stacks |
| 39½" | Window Side | Use 2 stacks of cutoffs |
| 31½" | Window Top | Use 1 stack of cutoffs; bevel top at 30˚ |
| | Window Bottom | Leave 4th stack uncut |

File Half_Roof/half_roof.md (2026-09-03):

```{=typst}
#title-page[
  #text(36pt, weight: "bold")[Half-Roof Assembly]
  #v(1em)
  #text(24pt)[Jig Instructions]
]
```

# SET UP LIST
- Screw gun with T25 bit and small socket
- Long screws
- Short screws
- 2 A35Z angle brackets
- Galvanized SD #10 Screws
- Mallet
- Clamps
- Drill
- 3 different drill bits in plastic container

`#pagebreak()`{=typst}
 
# Step 1
- Put white 1x6 board into the top of the jig. Note that there are also 1x8 boards in the same rack. Do not use these wider boards for this step
- Tap it down with mallet.

`#fullpage("images/half_roof.dxf", layers:"Framing Layer,Step 01")`{=typst}

# Step 2

- Prepare 2 notched 2x4 rafters by securing an angle plate to the left side of one and the right side of the other, as shown in the diagram, using 3 SD #10 Galvanized screws. **Make sure that the bottom of the angle plate is flush with the bottom of the rafter**.

- Put in these 2 rafters one slot in from each end. Place 2 additional rafters in the end slots, as shown in the drawing.
  - put a place holder (short 2x4) in the spot of the double rafter to stabilize first rafter

- Pre-drill (countersink drill bit) 2 holes in the white board at each of the 4 rafters.
  - top of white board and top of rafter flush
  - top hole 1 inch below top of white board
  - holes in a vertical line, one inch apart
  - holes angled down following 2x4 rafter centerline

- Drive in LONG SCREWS
  - tilted down following the 2x4 rafter centerline
  - making sure top of rafter is flush with top of white board
  - be sure that the screw head is flush with the white board vertical surface.  If it protrudes at all, the half-roof assemblies will not join properly.

`#fullpage("images/half_roof.dxf", layers:"Framing Layer,Step 02")`{=typst}

# Step 3
- Place three small blocks between the two end rafters. Start at the top, and for each block
  - Place a small 6½ inch 2x4 block between the rafters, in the space between a pair of angle irons.
  - Adjust the position of the block so that it is flush with the rafters at each end. Clamp the rafters below the block
  - Drive 2 brown (\#10) screws through the rafters into each end of the block
  - position screws so that they go into the block near its vertical centerline
  - insert screws about 2 fingers apart, one below the other

`#fullpage("images/half_roof.dxf", layers:"Framing Layer,Step 03")`{=typst}

# Step 4

- Remove the placeholder blocks from the rafter sockets

- Put a 3^rd^ rafter right next to the inner rafter of the 2 with the cross blocks.
  - Be certain that these two rafters are flush with each other, and that they both have tips aligned with the white board.

- Clamp those 2 rafters together

- Drive in 4 brown (\#10) screws spaced along the length of those rafters, to attach them together
  - Drive screws from inside the double rafters
  - All 4 screws above bottom cross block

- Place all the inner rafters

- Same as previous rafters, pre-drill 2 holes in the white board at each of the inner rafters
  - white board and rafter flush at top of white board
  - top hole 1 inch below top of white board
  - holes in a vertical line, one inch apart
  - holes angled down following 2x4 rafter centerline

- Drive in 2 **brown (\#10) screws** at each rafter
  - tilted down to follow the 2x4 rafter centerline

- Remove all paper stickers from the ends of the rafters

`#fullpage("images/half_roof.dxf", layers:"Framing Layer,Step 04")`{=typst}

# Step 5

- Note that there are 1x6 white boards in the same rack that holds the 1x8 boards.  Do not use the narrower board for this step.

- Place a 1x8 white board on the rafter ends at the bottom 
  - line up and clamp the right end and then the left end
  - make sure white board is flush with the outside rafter on the right end

- Working your way from the right end (top of the diagram), align the bottom edge of the white board flush with the end of each rafter. Pre-drill
through the white board and drive a **short (yellow) screw** into each rafter
  - use funky board \#9 to push the white board out to be flush with the end of each rafter, or push the white board toward the top of the assembly
if it hangs over the rafter end

`#fullpage("images/half_roof.dxf", layers:"Framing Layer,Step 05")`{=typst}

# Step 6

- Pre-drill and drive in a 2nd **short (yellow) screw** at each rafter
  - repeat all the way across the top of the 1x8 white board

- If white board extends past the left edge of the outside rafter, use a router to trim it flush.

`#fullpage("images/half_roof.dxf", layers:"Framing Layer,Step 06")`{=typst}

# Step 7

- Pre-drill holes for lag bolts on each of the inner rafters
  - See diagram
  - Use 13/16" spade bit
  - Bottom edge of hole 1/2" above the 1x8 white board
  - drill perpendicular to the floor, not the white board
  - drill bits in plastic container at station 5

- Using the larger straight drill bit, drill down into each of those holes through the rafter
  - bit in the plastic container
  - drill perpendicular to the floor

- Make a mark on the bottom inside of the 1x6 white board (at the top of the jig) 6¼ inches in from each end. This will help to align the half roof
when it is installed on the home. There is a pattern block that will make this easy; that block fits over the end of the 1x6 white board.

`#fullpage("images/half_roof.dxf", layers:"Framing Layer,Step 07")`{=typst}

# Remove Half Roof

- Remove the half roof by going down the top with a crowbar
  - Gently lift as you make your way to the other end
  - Do not force the top white board, especially at the ends.
    If gentle prying does not free the board, raise the end rafters from the bottom to free the assembly.

- On both ends, lift the high side upwards
  - towards being perpendicular with the floor
  - it will work its way off the jig 

`#pagebreak()`{=typst}

# HALF ROOF --- CHECKLIST

1.  White board --- 6 inch
2.  Install angle brackets (one left, one right)
3.  2 rafters each end
4.  Pre-drill 2 holes each rafter
5.  Long screws through white board
6.  Small blocks between end rafters
7.  Double rafters, place & screw
8.  Inner rafters
9.  Pre-drill and screw
10. Remove stickers
11. White board --- 8 inch
12. Pre-drill, short screws
13. Countersink pre-drill --- see diagram
14. Drill through each countersink hole
15. Alignment marks on 6 inch white board
16. Remove half roof from jig

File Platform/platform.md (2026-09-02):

```{=typst}
#title-page[
  #text(36pt, weight: "bold")[Platform]
  #v(1em)
  #text(24pt)[Jig Instructions]
]
```
# PLATFORM - SET UP LIST
- Put construction adhesive (Liquid Nails) by heater
- Caulking gun
- Framing nail gun
- Framing nails
- Screw gun with T25 bit
- Screws --- 3" with T25 head
- Screws --- hex head for brackets
- Brackets
- Chalk line
- Mallet
- Great Stuff cans
- 12" spacer blocks marked "SAVE"
- Jenga blocks

`#pagebreak()`{=typst}

# Step 1

- Set 2x6s into the jig to form the perimeter. Check the long 2x6s for straightness. If not straight, be sure to place them so that the curve
is inward at the center of each board. Put 1 FRAMING nail in each of the corners
    - one person holds flush on top and sides, other person nails
- Check the frame for square: measure the diagonals; they should be the same. Adjust as necessary.
- Put 2 more nails (total of 3) in a vertical line at each of the 4 corners.

`#fullpage("images/platform.dxf", layers:"Jig-Framing,Step_01")`{=typst}

# Step 2
- Put a second 2x6 inside the ones on each short end
    - CLAMP them together
    - nail these 2x6 together 4 places at each end of frame, centered vertically
- Team leader
    - using the triangle, mark a line on the outside of the long 2x6s at the middle of the ends of each joist to show where the nails go.

`#fullpage("images/platform.dxf", layers:"Jig-Framing,Step_02")`{=typst}

# Step 3
- Put in all the inner 2x6 joists
- Put 3 nails in a vertical line on each end of each joist
    - make sure joists are flush with side rail before nailing

`#fullpage("images/platform.dxf", layers:"Jig-Framing,Step_03")`{=typst}

# Step 4

- Put pre-cut skids into the steel building carriages
    - longer part of the angled edges up
    - position each 4x6 skid so that the vertical mark on the skid lines up with the front of each carriage at the eventual front of the home.
- Install the alignment jigs, first to the front of the skids, and then to the back.
    - At the front, the cross bar should stick up above the tops of the  skids, and the two alignment blocks should be flush with the skid tops.
    - The skids should both be between the two alignment blocks.
- Place chocks under the wheels of one carriage, to keep if from moving.
- Measure diagonally from jig corner to corner and adjust the other carriage so that the jig is square.  Place chocks under its wheels.
- Pry the frame out of the framing jig, and lift the frame onto the pre-cut skids
    - At the front, the frame should be up against the alignment jig crossbar. At all four corners, the frame should fit into the metal angles.
    - Verify that the skids do not stick out beyond the back of the frame. If they do, they were not trimmed correctly, and this must be corrected.
- Measure the diagonals of the frame, and make sure that they are the same, so that the frame is square.
    - After any adjustments, **make sure** the frame is tight against the front jig crossbar.

`#fullpage("images/platform.dxf", layers:"Step_04-Framing,Step_04-overlay")`{=typst}

# Step 5

- Team Leader
    - make an X where the metal brackets should go
    - FOLLOW LOCATIONS on DIAGRAM
    - alternate inside of the skid and outside of the skid all the way to the rear
    - make sure to make a mark on the inside of the double joist at the rear.

`#fullpage("images/platform.dxf", layers:"Step_04-Framing,Step_05")`{=typst}

# Step 6
- At each X, screw in a metal bracket
    - use 6 small hexagonal screws for each metal bracket
    - 3 on the bottom 3 on the top, attaching the frame to the skids

`#fullpage("images/platform.dxf", layers:"Step_04-Framing,Step_06")`{=typst}

# Step 7

- Place blocks labeled "SAVE" in each bay, except the front and back bays
    - on top of each skid, centered between the joists.
    - DO NOT NAIL
    - In the front and back bays, place the "SAVE END" blocks

`#fullpage("images/platform.dxf", layers:"Step_04-Framing,Step_07")`{=typst}

# Step 8

- Put rigid insulation foam pieces into each bay
    - Cut the foam if not pre-cut. Use templates
    - 2 at 11^1^/~2~ inches wide by 92^1^/~2~ long
    - 7 at 14 inches wide by 92^1^/~2~ long
    - use an Exacto knife with blade all the way out
    - Cut the ends to fit the length, and install with silver side UP.
- Using GREAT STUFF spray cans
    - put lines to fill in at all the junctions between the foam and the joists.
    - Start with tip of spray can at the middle, and pull towards you.
    - DO NOT SET THE SPRAY CANS ON WORK STATIONS

`#fullpage("images/platform.dxf", layers:"Step_04-Framing,Step_08")`{=typst}

# Step 9
- Under the 1^st^ plywood panel ONLY
    - put Liquid Nails construction adhesive on each of the joists and along the side rails, only along the first 3 bays. 
- Place the 1^st^ plywood panel (3/4" CDX plywood)
    - use panels from pile labeled PLATFORM
    - line it up to be flush with the outer edges and the middle of the inner joist.
- Put a nail in that inner joist corner. Use that as the pivot point to line up the panel
- Nail about 8 inches apart along 2 edges using 3" framing nails.
- Put a chalk line at the intermediate joists
    - get up on platform and closely straddle the chalk line (joist) to push the plywood board down while nailing
    - walk backwards while nailing 8 inches apart.
- Nail along all chalk lines in a pattern going diagonally towards the opposite corner from where you started

`#fullpage("images/platform.dxf", layers:"Step_04-Framing,Step_09")`{=typst}

# Step 10

- Apply Liquid Nails construction adhesive to the joists that will be under the 2^nd^ plywood panel
- Place the 2^nd^ panel
    - at one side of the platform, put one nail into the 2^nd^ panel at the corner close to the 1^st^ panel
    - use this pivot point at the junction of the 2 panels to align the 2^nd^ panel
    - along the seam, nail about every 8 inches, slightly angled in towards the junction line
- Nail along edges and chalk lines

`#fullpage("images/platform.dxf", layers:"Step_04-Framing,Step_10")`{=typst}

# Step 11

- Apply Liquid Nails construction adhesive to the joists that will be under the 3^rd^ plywood panel
- Place the 3^rd^ panel
    - at one side of the platform, put one nail into the 3^rd^ panel at the corner close to the 2^nd^ panel
    - use pivot point at the junction of these panels to align the 3^rd^ panel
    - along the seam, nail about every 8 inches, slightly angled in towards the junction line
- Nail along edges and chalk lines

`#fullpage("images/platform.dxf", layers:"Step_04-Framing,Step_11")`{=typst}

# Step 12

- Router the edges of the platform. Ideally this would be done the next day, to let the liquid nails dry, but if tilt-up will be happening same-day, do it now.
  - Wipe off any liquid nails that's been squeezed out around the platform's perimeter.
  - Router the edges.
  - Clean the router's blade & table using an exacto knife and paper towel / rag. Try to leave all of the knife, router blade, and router table free of adhesive.

- Draw a line 3½ inches from the edge on all sides
    - use the marking jig; it hangs from the back saw table. Using a felt-tip pen, hold it against the inside of the jig,
    and slide the jig along the sides of the platform.

`#fullpage("images/platform.dxf", layers:"Step_04-Framing,Step_12")`{=typst}

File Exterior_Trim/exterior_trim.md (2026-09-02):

```{=typst}
#title-page[
  #text(36pt, weight: "bold")[Exterior Trim]
  #v(1em)
  #text(24pt)[Instructions]
]

#let horizontal-center(path, vspace: 1in) = {
  if (vspace != none and vspace != 0) {
    v(vspace)
  };
  align(center)[#rect(stroke: none)[#image(path)]];
}
```

# CORNER TRIM INSTALLATION

Check to be sure that the paneling has been routed (on the right edge as you face
the front or back of the home), so that it does not extend beyond the
sidewall paneling.

All exterior trim boards are together on a rack at the West end of the factory.  Corner boards are precut to 93¼ˮ.  Window trim pieces for tops and sides
are also precut; the top trim has a 30° bevel on one long edge.

Trim boards have an outer and an inner side.  The outer side has vertical grooves in the surface.  The inner side is not as attractive, and caulk should always be applied to that inner side.

`#pagebreak()`{=typst}

## Step 1 -- Corner Board \#1
* The cut end of the 1x4 (without paint) should be at the top. It is better protected from the weather that way.
* At each corner, mark upper edge of 1x4 to fit around inner rafter
    - Line board up flush with end wall and below the double rafters (use alignment block) mark top of the board for a vertical cut
    - Set board next to the rafter and flush with the bottom of the wall panel, mark at bottom of rafter for a horizontal cut
    - Mark back of 1x4 to identify which corner it belongs to.
* Draw cutout lines and cut out corners with a jigsaw
* Put EXTERIOR caulk as shown.
* Flip board so that the caulk will be against the side wall, and position so that it is flush with the end wall (use alignment block.)
* Nail (PANEL NAILS)
    - 2 nails about 2ˮ from top
    - 1 nail every 8ˮ down the middle
    - 2 nails about 2ˮ from the bottom

`#horizontal-center("images/back_corner.dxf", layers:"Building,Roof_Framing,Corners_1"); #pagebreak()`{=typst}

## Step 2 -- Corner Board \#2
* The cut end of the 1x4 (without paint) should be at the top. It is better protected from the weather that way.
* Put EXTERIOR caulk as shown, and flip board so that caulk will be against the end wall.
* Line up the bottom of board with the bottom of Board #1.
* Starting at the top (use alignment block) to line up outside (corner) edge of the Board #2 with the surface of Board #1, nail (PANEL NAILS)
    - 2 nails about 2ˮ from top
    - 1 nail every 8ˮ down the middle
    - 2 nails about 2ˮ from the bottom.
* Repeat for the other three corners of the home.  Note that on two of those corners, the caulking will be a mirror image of that shown.

`#horizontal-center("images/back_corner.dxf", layers:"Building,Roof_Framing,Corners_2"); #pagebreak()`{=typst}

# REAR WINDOW TRIM

## Step 1 & 2 -- Side Trim Pieces

* Using precut side pieces, put EXTERIOR caulk as shown.
* Place side piece snug up against the window. Use a block to align the top of each piece with the top of the window.
* Nail (PANEL NAILS)
    - 2 nails 1-½" below top
    - 1 nail in the middle of the board every 8"
    - 2 nails 1-½" above the bottom.

## Step 3 -- Top Piece

* Using precut beveled top piece, apply EXTERIOR caulk behind the beveled edge and at both ends, as shown.
* Position with right edge flush with side trim.  **Do not** allow this top trim to extend past the right-hand side trim.  It will interfere with the trim around an air conditioner, when that is installed.
* Nail (PANEL NAILS)
    - 2 nails 1-½" in from each end
    - 2 nails in the middle of the board.

## Step 4 -- Bottom Piece

* Measure between the 2 side pieces under the window, and cut a piece of 1x4 that length.
* DO NOT caulk this piece.  Nail (PANEL NAILS) it in place
    - 2 nails 1-½" in from each end
    - 2 nails in the middle of the board.

`#fullpage("images/rear_window.dxf", layers:"Window Trim")`{=typst}

# FRONT WINDOW TRIM

**Stop here** Do not install this trim until the door is in place!  Consult the separate section on installing a door.

## Step 1 \-- Top trim

* Using precut beveled top piece, apply EXTERIOR caulk behind the beveled edge and at both ends, as shown.

* Nail (PANEL NAILS)\
    - 2 nails 1-½" in from each end\
    - 2 nails in the middle of the board.

## Step 2 \-- Side trim away from door

- Using a pre-cut side trim piece for side of window away from door
- Apply EXTERIOR caulk as shown for Rear Window
- 2 nails 1-½" below top
    - 1 nail in the middle of the board every 8"
    - 2 nails 1-½" above the bottom.

## Step 3 \-- Side trim between window and door

- Use a pre-cut side trim piece
- Apply EXTERIOR caulk as shown for Rear Window. Center and nail as above

## Step 4 \-- Bottom piece

* Measure between the two side pieces under the window, and cut a piece of 1x4 that length
* DO NOT CAULK this piece. Nail it in place (PANEL NAILS)
    - 2 nails 1-½" in from each end
    - 2 nails in the middle of the board
    
`#fullpage("images/front_window.dxf", layers:"Window Trim")`{=typst}

# EXTERIOR TRIANGLES - FRONT & BACK

NOTE - Pre-cut Tyvek, metal flashing and triangle siding are on the back shelves near the white boards.

## Step 1: Tyvek

* Staple pre-cut Tyvek triangles to the structural triangle.
* Staple along top and bottom edges and down the center studs; hammer in all staples flush.

## Step 2: Z-Flashing

* Install pre-cut piece of metal flashing
    - short leg down so that flashing rests on top of the\ T1-11 siding at the top of the wall and the short leg extends down over the siding
* Center the flashing between the rafter ends
* Nail (PANEL NAILS) 3 places: near each end, and in middle

`#fullpage("images/triangles.dxf", layers:"Framing,Step_1_2")`{=typst}

## Step 3: T1-11 Triangles

* Install large pre-cut triangular piece of T1-11 siding
    - cover long leg of Z-flashing
    - bottom of siding a pencil-width above the Z-flashing fold
    - if necessary, trim siding piece so that it fits against the structural triangle
    - Nail (Panel Nails) every 8" along rafters, bottom of triangle, and along center blocking.

* Install small pre-cut triangular piece of T1-11 siding
    - line up the bottom edges
    - make the seam tight
    - Nail (Panel Nails) in two places

* Caulk (EXTERIOR caulk) all exposed nails and seam

## Step 4: Soffits

* Install precut soffit boards under rafters at each end of building.
  * Mark location of cross blocks between rafters
  * Position soffit board with angle-cut end tight against ridge beam and long edge tight against T1-11 siding. Trim as necessary to fit,
    so that soffit does not protrude past outer surface of outside rafter.  Otherwise, the fascia boards will not fit against the rafters
    when the roof goes on.
  * Nail (Panel Nails) 3 places into outside rafter, and one nail into each cross block

`#fullpage("images/triangles.dxf", layers:"Framing,Step_3_4")`{=typst}

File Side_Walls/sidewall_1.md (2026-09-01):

```{=typst}
#title-page[
  #text(36pt, weight: "bold")[Side Wall #1]
  #v(1em)
  #text(24pt)[Jig Instructions]
]
```
# SIDE WALL - SET UP LIST

- Put caulk by heater
- Caulking gun
- Framing nail gun
- Framing nails
- Panel nails
- Triangle
- Screw gun with T25 bit
- Long screws
- Short screws
- Chalk line
- Stapler
- Staples
- Mallet
- Hammer
- Clamps
- Router

`#pagebreak()`{=typst}

## Step 1

- Place 144" top and bottom plates in the jig, being sure that any bow in these boards bends inward, as marked on the jig.
- Place 84" 2x4s (studs) in the designated spots on the perimeter, with thin face up.
- Place an 84" 2x4 flat (wide face up) at each of the short ends. Be sure that this flat board is all the way down against the bottom of the jig.
  Placing these boards now insures that they will fit into the jig.
- Put in 1 FRAMING nail (the longer ones) in each corner of the frame.  Do not nail into the flat 2x4.
    - line up to be flush on top and sides
    - one person holds and the other nails
    - in the upper middle of the stud to connect the corner
    - in each of the 4 corners
- Put a second nail directly under each of the first nails.

`#fullpage("images/side_wall.dxf", layers:"0_Framing,Step_01")`{=typst}

## Step 2

- CLAMP the flat and perpendicular boards
- TEAM LEADER - Pre-drill for 2 long SCREWS into each end of the flat board, and 8 SCREWS along the short side at the bottom to connect perpendicular 2x4 with the flat one. These 8 holes should be about 3/4" above the bottom edge of the perimeter studs.
- Drive long screws into all these holes.
- While this goes on, crew place the remaining studs in the jig (step 3).

`#fullpage("images/side_wall.dxf", layers:"0_Framing,Step_02" )`{=typst}

## Step 3

- Place the inner 2x4 studs
  - make sure the 2x4s on both sides of the middle stud are fairly straight; they will be the magic studs
- Team leader: Draw vertical lines on the top and bottom plates at the center of each of the inner studs to designate nail placement

`#fullpage("images/side_wall.dxf", layers:"0_Framing,Step_03")`{=typst}

## Step 4

- Put 2 FRAMING nails on the line at each stud
     --- put second nail directly under the first
     --- one person holds the stud so that it is flush while the other nails
- Check that all studs have two nails (or screws) in each end.

`#fullpage("images/side_wall.dxf", layers:"0_Framing,Step_04")`{=typst}

# Step 5

- Place the Tyvek
  - start by stapling it flush with the top
  - unroll a few feet at a time as it gets stapled, not all at once
- Staple as you unroll
  - 3 staples in the corners and a staple every 8 inches.
- Stretch the Tyvek so that it is tight.
- Staple top, side, bottom, side
- Staple along the length of ALL of the inner studs

`#fullpage("images/side_wall.dxf", layers:"0_Framing,Step_05")`{=typst}

## Step 6

Put PANEL nails (shorter ones) in the nail gun

- Place Panel 1, with the tongue (lower thin bit) toward the center of the wall
- Put Funky Board #1 in the slot to line up the first panel. (Funky Board found at the end of jig)
- Line the panel up flush with top, and tight against the Funky Board.
  - put 1 panel nail in the top corner next to where the 2^nd^ panel goes as a pivot point, adjust.
- Nail the panel to the studs
  - along the top, sides and down each inner stud.
  - use chalk lines to designate where the inner studs are.
  - get on top, straddle the stud to push the panel down and walk backwards nailing along the stud/chalk line
  - work your way diagonally from one corner to the opposite one.
- Place a thin line of EXTERIOR caulk
  - along the outside edge of the tongue and groove part

NOTE: DO **NOT** nail inside the grooves, nail about 1/2" from the edge of the groove, angling the nail gun if necessary to be sure that each nail
hits the center of the stud (where the chalk line is.)

`#fullpage("images/side_wall.dxf", layers:"0_Framing,Step_06a")`{=typst}

## Step 7

- Place Panels 2 & 3 such that the sunken groove is the same as all the others on the panel
- Repeat the above nailing process with this 2^nd^ panel and the 3^rd^ one
- Staple the Tyvek to the underside of the panels at the bottom
- Trim all Tyvek to be flush with edges
  - on the sides, trim the Tyvek flush with the framing.
- Team leader
  - router the side of the paneling so that it is flush with stud underneath
- Smooth out caulk along the panel joints, using a scrap of Tyvek or a paper towel. Do not caulk the nail heads if tilt-up is scheduled for the same day.

`#fullpage("images/side_wall.dxf", layers:"0_Framing,Step_07a")`{=typst}

# SIDE WALL ASSEMBLY CHECKLIST

- Perimeter boards
- Nail corners
- Place flat board both short ends
- Clamp
- 2 long screws at flat board ends
- 8 long screws into flat and perpendicular boards
- Place all inner boards, good ones at magic studs
- 2 nails at ends of all boards
- Staple Tyvek- top, sides and inner studs
- Panel 1 --- funky board #1
- Nail (PANEL NAILS) top, sides, inner studs
- Caulk Panel 1 edge
- Panel 2
- Nail (PANEL NAILS) top, sides, inner studs
- Caulk Panel 2 edge
- Panel 3
- Nail (PANEL NAILS) top, sides, inner studs
- Staple & trim Tyvek
- Router side edges

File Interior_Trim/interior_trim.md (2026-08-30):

```{=typst}
#title-page[
  #text(36pt, weight: "bold")[Interior Trim]
  #v(1em)
  #text(24pt)[Instructions]
]

#let imgCtr(path) = {align(center + horizon)[#image(path)]}
```

# SETUP LIST

- Interior Trim:
    - Drill with countersink bit
    - Screw gun with T25 drive bit
    - Finish nailer and finish nails
    - Level
    - Measuring Tape
    - Pencil

- Install Vent Cap:
    - Drill with countersink bit
    - Screw gun with T25 drive bit
    - Measuring Tape
    - Pencil
    - Spirit Level
    - Support Block installation pattern
    - Vent Cap Drill pattern
    - \#10 x 3" Screws (brown)

`#pagebreak()`{=typst}

# INTERIOR TRIM

- 1st Install **[MEDUSA]{.underline}** (foam backer rod) in the spaces between the front and back windows and the window framing.
Use a piece of flooring or a putty knife to make insertion easier.
- Use **TRIM** nail gun and **TRIM** nails
- Nailing Pattern for ALL inside trim:
    - 2 nails at one end
    - 1 every 8"-12" in the middle
    - 2 at the other end
- Note that '2" trim' is not actually 2" wide, but is a little narrower.  Where two pieces butt up to each other, make sure that the widths match.

## **Install trim in the following order**

## Baseboards

- Set down spacers under the baseboard along each wall to provide a small space between the baseboard and the floor, so that the flooring can "float".
These spacers are squares of thin flooring marked with an **O**, and can be found in a plastic bucket in Workstation #4.
- Measure along a sidewall from back to front near the floor. Using long 4" white baseboards, cut a piece this length and nail in place to the side wall. 
- Repeat on the other side wall.
- Measure between the side baseboards at the rear wall. Measure long (about 1/16") so it will fit snugly. Cut a length of baseboard and nail.  Save the cut-off piece for the front wall.

`#fullpage("Images/combo_trim.dxf", layers:"0,0_Panel_layer1-3,1_Baseboards")`{=typst}

## Rear Window Shelf

Check that MEDUSA (foam backer rod) is installed around the window unit.

- Use pre-cut rear shelf

1. Pre-drill three holes using countersink bit, as shown in the diagram
   - Position shelf in window opening, and screw in 3 **LONG** screws next to bottom of the window

2.Cut 2x4 support block for under the shelf

   - Subtract 1 inch from shelf width ( ½" on each side )
   - Center block under the shelf with long side against the wall, **and 1/2" shelf overhang on each end.**
   - Mark on the wall where the ends of the 2x4 should be, and then mark on the 2x4 where the lines of paneling screws fall (stud markers).
   - Preset 2 **LONG** screws in a vertical line into the block at each of the stud markers
   - Position the 2x4 up against the underside of the shelf, and lined up with the end marks on the wall
   - Drive the screws into the wall to secure the support block
   - Be sure there is no space between the wall and the support block

3. Pre-drill and insert a **LONG** screw next to the wall down through the shelf and into the 2x4 on each side of the window, about 2" in
from each edge of the shelf (#3).

`#fullpage("Images/rear_window.dxf", layers:"0,1_Paneling,2_Shelf")`{=typst}

## Rear Window Trim

- Use precut pieces (3-1/8 x 35) to line the sides of the window opening
1. Nail 1 piece to each side of the window opening, edge flush with wall, and tight at the bottom. (2 nails at top, 1 every 8", 2 at the bottom)
2. Measure (very close to window) between the sides for the top of the window liner. Cut one piece of window liner that length and nail in place.
3. Measure the sides of the window from shelf to top of window opening.
    - Cut a piece of 2" trim this length for each side, and check that when these are in place, a third piece of trim will be exactly flush with the
      inner edge of the lining at the top of the window.
    - Nail 2" trim to both sides of the window, keeping the trim flush with the inside of the window lining boards.
4. Measure above the window from the outer edges of the vertical trim
    and add one inch. Cut 2" trim and nail above the window with 1/2" overhang on each side, keeping the trim flush with the top window lining.

`#fullpage("Images/rear_window.dxf", layers:"0,1_Paneling,3_window_liner,4_window_trim")`{=typst}

## Top trim (2" trim boards)

- Start on the side walls at the back. Select an 8' x 2" trim piece and a shorter piece of the same width
1. Set the long trim board against the rear wall, and push it up so it is tight against the ceiling. Nail.
2. When back upper trim is installed, measure from end of that piece to the front wall
    - Cut a piece of trim of the same width about 1/16" longer than the measurement, and snap it into place
    - Line up the bottom edge with the trim already in place, and nail the shorter piece in place
3. (& 4) Repeat 1 & 2 on the other wall

<!-- -->
5. Select another long piece of 2" trim that is the same width as the trim on the side walls.
    - Measure between the upper trim at the back wall.
    - Cut long (about 1/16" over) so that the trim fits snugly 
    - Nail trim into place

`#fullpage("Images/combo_trim.dxf", layers:"0,0_Panel_layer1-3,2_Top_Trim")`{=typst}

# Vertical Trim (2" trim boards)

1. **Side walls first** - measure from the top of the baseboards to the bottom of upper trim in back corner, add 1/16".
   - Cut and nail. Repeat on the other side wall.
   - Measure at the vertical seam between the side panels from top of baseboard to bottom of upper trim.
   - Cut and nail. Use a level to be sure this trim is vertical.
2. Repeat on the other wall.
3. On the **back wall** - Measure from the top of the baseboards to the bottom of upper trim in the corner.
Cut and nail a piece of trim in each corner.  Push this trim against the sidewall trim as you are nailing, to insure a tight seam.

`#fullpage("Images/combo_trim.dxf", layers:"0,0_Panel_layer1-3,3_Vertical_Trim")`{=typst}

# Horizontal Trim

## 1. Back wall

- Measure from back corner vertical trim on one side to the other back corner vertical trim.
- Cut a piece of 2" trim this length plus 1/16" for a snug fit.
- Measure the height of the seam between upper and lower wall panels above floor, and mark on the wall panel at 1" less than this dimension
  near each corner, on either side of the vertical trim covering the wall seam, and in the center of the wall.
- Remember this measurement for other walls.
- Line back wall trim piece up so that its bottom edge is on these marks, and nail in place
  
## 2 & 3. Side walls at the back

- Measure from the back corner trim to middle vertical trim (add 1/16" so it fits snugly), and cut 2" trim to this dimension
- Measure and mark on the wall on both sides of the vertical trim, at the same dimension used on the back wall.
  Make another mark halfway between the two ends of the panel.
- Line side wall trim piece up so that its bottom edge is on these marks, check that it lines up visually with the
  corresponding trim on the back wall, and nail in place.

Do NOT install mid-level horizontal trim between vertical trim
and front wall. This will be done after Front Wall trim.

`#fullpage("Images/combo_trim.dxf", layers:"0,4_Horizontal_Trim")`{=typst}

# Triangle trim

- Collect precut pieces of 2" X 42" trim from the rack: 2 left, 2 right, 6 straight.  These will be used for rear and front triangle trim.  Cut (from scraps) 2 strips 12" long.
- Position two angled pieces on the back wall and nail in place. (#4)
    - A helper can push the trim up so that it is tight against the ceiling.
- Position a straight piece (42") on the ceiling and tight against each of the angled piece just installed. Nail it in place.
    - A helper can push the trim tight against the piece just installed, so that the trim is tight all along the joint
- Install a 12" piece of 2" trim vertically to cover the seam between the triangles (#5)
- Save remaining trim pieces for the front wall triangle

`#fullpage("Images/combo_trim.dxf", layers:"0,4b_Triangle_Trim")`{=typst}

# Front Wall 

## Prepare and Inspect

- Check that **MEDUSA** (foam backer rod) is installed around the window.
- `#text(16pt)[The door must be installed before the steps below.]`{=typst}

## Baseboard

1. Measure near the floor from the center of the door jamb to the sidewall baseboard.
    - Position two spacers on the floor where the baseboard will go
    - Cut a piece of baseboard and nail in place.  
    - Do this first, to avoid hitting your head on the shelf above.

## Shelf and Window

- Use pre-cut front shelf.
- Test fit the shelf
    - If the extension does not touch the wall, trim the edge that sits in the window frame
    - Otherwise, if the gap between the window and the edge of the shelf is too big, trim the extension (jigsaw)
2. Pre-drill and countersink 3 places at shelf edge near the window.
    - Position shelf in window frame, and screw in with 3 **LONG** screws next to bottom of the window.
3. Cut 2x4 shelf support block, subtracting 1/2" from shelf width
    - Place 2x4 under the shelf with 4 inch side against the wall
    - This block **must be** flush with door side of the shelf
    - There will be 1/2" shelf overhang on the side wall side
    - Mark on the 2x4 where the line of paneling screw falls (stud marker).
    - Mark about 2" in from each end and 3/4" from the top of the 2x4
    - Preset **LONG** screws into the block as shown in the diagram
    - Position the block up against the bottom of the shelf
    - Drive the screws into the wall
    - Be sure that the 2x4 is tight against the wall.  If not, back the screw out and re-install it, putting pressure on the 2x4
4. Pre-drill and install 3 **LONG** screws next to the wall going through the shelf and into the 2X4 on both sides of the window as shown in diagram
5. Nail precut pieces of window liner (3-1/8 x 35) to the side walls of the front window opening
    - Be sure that the front edge of these pieces is flush with the interior of the wall panel
    - Place the precut piece of window liner tight against the shelf, leaving any gap at the top
6.  Measure (very close to window) between the sides for the top of the window piece. Cut one piece of window liner that length and nail in place

`#imgCtr("Images/front_window.dxf", layers:"1_Paneling,2_Shelf,3_window_liner,4_Front_Trim_B")`{=typst}

`#pagebreak()`{=typst}

# Front Wall Trim -- Part I

1.  Measure horizontally from one upper corner to the other. Cut and nail 2" trim.
1.  Behind the door, measure from baseboard corner to the center of the doorjamb. Cut a piece of 4" baseboard this long.
    - Position a spacer beneath the baseboard
    - This piece will be nearly square; make sure the cut edges are vertical, and nail it in place
1.  Measure horizontally from the inner edge of the window opening to the center of the door jamb next to the window ( \~5½ inches)
     - Rip a 10" x 96" trim board to this width on the table saw; save the narrower piece (\~4½ inches) for step 4
     - Measure from the top horizontal trim to the baseboard and cut the wide trim to this length
     - Mark where a cutout must be made on this wide trim for the front shelf and support block
     - Cut out a notch for the shelf using a jigsaw. Nail in place, being sure that the edge next to the window is flush with the window liner.
1.  Measure the height on the front wall behind the door from upper trim to the baseboard. Check that the narrow board from step 3 will span from the center of the door jamb to within 3/8" of the wall. If it is too narrow, cut and install the 2" trim piece in step 5 first.
     - Cut this piece to length, and nail in place, halfway across the door jamb
1.  Measure from the baseboard to the upper trim on the sidewall in the corner behind the door. Cut a length of 2" trim and nail. This should cover any gap at the corner.

`#fullpage("Images/combo_trim.dxf", layers:"0,5_Panel_layer_6&7,6_Front_Trim_A")`{=typst}

# Front Wall Trim -- Part II

1. Measure above the door from the sidewall trim to the 5½" board. Cut 2" trim and nail in place over the door, and with the bottom edge halfway over the door frame.
2. Measure, cut, and install 2" trim on the top and wall-side of the front window flush with window opening liner
     - top trim has ½" overhang on the right side

3. Measure, cut, and install 2" trim on the side wall in the corner next to the shelf end.
4. Measure, cut, and install 2" trim on the front wall in the corner next to the window.
5. Triangle trim
     - Use remaining trim pieces saved after rear wall triangle trim.
     - Position the angled pieces and nail to the front wall.
     - Nail a straight piece (42") on the ceiling tight against each angled piece just installed.
     - Position a 12" piece of 2" trim vertically over the center seam in the front triangle and nail.
 
`#fullpage("Images/combo_trim.dxf", layers:"0,5_Panel_layer_6&7,7_Front_Trim_B")`{=typst}

# Final Trim

1.  Measure, cut, and place the final horizontal trim piece in the middle of one side wall, lining it up with the long middle trim on that wall.
    - Marks should be on the wall to indicate the bottom of this trim piece (from Horizontal Trim section, above)
1.  Repeat for the other side wall
1.  Measure, cut, and place the horizontal piece that goes under the front window shelf
    - Measure up from the top of the baseboard the same distance that was used for the side wall trim, and mark near the corner and near the door.
    - Align the bottom of the trim with the marks at waist level. Nail in place.
1.  DON'T FORGET - Measure, cut, and nail in place a small piece of trim on the front wall behind the door, to match the middle trim on the side wall.
1.  Nail the remaining two pieces of 2" straight trim (42") over the ceiling seams, tight against the top trim strips on each side wall,
and extending up near the roof vent.

`#fullpage("Images/combo_trim.dxf", layers:"0,8_Panel_layer_9,9_Final_trim")`{=typst}

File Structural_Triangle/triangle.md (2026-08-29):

---
no-title-page: true
---

<!-- This file is mostly for posterity in case we decide to adapt its input -->
<!-- .dxf in future.  (it harks back to a time when triangles were nailed -->
<!-- but too often the triangle would get nailed to the jig, so now we -->
<!-- screw and don't have a manual for that, instead relying on jig -->
<!-- markup). -->











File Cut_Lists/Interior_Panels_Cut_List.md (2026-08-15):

---
no-title-page: true
---

# Interior Panels Cut List

This cut list will produce paneling for two homes. Get 3 orange carts
for this work.

### Horizontal Cuts

Set up the panel saw for horizontal cuts. Using the templates, cut in
this order and stack on a temporary cart:

| Quantity | Height | Width |
| --- | --- | --- |
| 6 | 43 ½" | 96" |
| 4 | 44" | 96" |
| 7 | 38 ¼" | 96" |

### Vertical Cuts

Set up the panel saw for vertical cuts. For each home, cut the following
panels and mark each with the panel designator letter, and indicate the
cut edge. Stack these panels on one cart per home in this order (back to
front):

| Width | Length | Label | Source |
| :--- | :--- | --- | :--- |
| 48" | 88" | D | Uncut panel from plywood stack |
| 38 ¼" | 46 ¼" | E | Cut two E panels from one 38¼ x 96 |
| 48" | 88" | G | Uncut panel from plywood stack |
| 38 ¼" | 88" | H | Temporary cart (thinnest panels); see below for cut-off. |
|  4" | 38 ¼" | E2 | Remainder from H panel above; take to table saw per below |
| 44" | 86 ½" | C | Temporary cart (widest panels) |
| 48" | 92" | A | Uncut panel from plywood stack |
| 38 ¼" | 92 | B | Temporary cart (thinnest panels) |
| 44" | 86 ½" | C | Temporary cart (widest panels) |
| 48" | 92" | A | Uncut panel from plywood stack |
| 38 ¼" | 92" | B | Temporary cart (thinnest panels) |
| 43 ½" | 44" | R2 | Temporary cart (middle width panels) |
| 43 ½" | 44" | R2 | Remainder from previous R2 |
| 43 ½" | 92" | R1 | Temporary cart (middle width panels) |
| 43 ½" | 92" | R1 | Temporary cart (middle width panels) |

### Table saw

The cut-off piece from the H panel above will be 38 ¼" by 8 ½".  Rip
two 4" pieces on the table saw, using the 4" Trim template. The two
halves will be used on the left side of the door, under the D
panel. Label them as "E2" and put one on each cart. Extras
can go in the standing short-materials bin by the long-materials
shelves.

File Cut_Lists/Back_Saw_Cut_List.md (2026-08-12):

---
no-title-page: true
---

# BACK SAW CUT LIST: CUT FOR 2 HOMES

## Platform Frame Cart:

| Quantity | Dimensions | Notes |
| --- | --- | --- |
| 24 | 2x6x93 in | Use 8' 2x6 |
| 4 | 2x6x144 in | Use 12' 2x6 |

## Back Saw Cart:

| Quantity | Length | Notes |
| --- | --- | --- |
| 4 | 89 in | Use 8' 2x4 |
| 32 | 84 in | Use 8' 2x4 |
| 4 | 37 ¾ in | Take 20½" scrap to front saw cart |
| 8 | 24 in | Scrap, or use another 8' 2x4 |

## Bird Block: (take to Band Saw for 18.5° angle cut)

| Quantity | Dimensions | Notes |
| --- | --- | --- |
| 16 | 2x4x22¼ in | Use 8' 2x4 |
| 8 | 2x4x18 in | Use 8' 2x4 |

## Rafters:

| Quantity | Dimensions | Notes |
| --- | --- | --- |
| 44 | 56 ¾ in, 18.5° cut one end | Use 10' 2x4, for 2 pieces |

Mark rafter cutout using pattern, then take to Band Saw.

## Vent Blocks:

| Quantity | Dimensions | Notes |
| --- | --- | --- |
| 16 | 21 7/8 in | for middle bays |
|  8 | 18 1/8 in | for end bays|

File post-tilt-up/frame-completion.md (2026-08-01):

```{=typst}
#title-page[
  #text(36pt, weight: "bold")[Frame Completion]
  #v(1em)
  #block(width: 60%)[#align(left)[#text(24pt)[Secure Walls\
  Install Structural Triangles\
  Install Half-roofs]]]
]
```

# Secure Walls to Platform

* Equip two crews of two people with screw guns and brown #10 x 3” screws, and have them install 4 screws in each bay of all four walls,
  through the bottom plate into the platform, as shown in the diagram.



`#pagebreak()`{=typst}

## Reinforce Corners
* Have one person install 5 #10 x 3” screws in each wall corner

```{=typst}
#scale(70%, reflow: true)[#image("images/image_32.png")]
#align(center)[Front Wall]
#scale(70%, reflow: true)[#image("images/image_33.png")]
#align(center)[Rear Wall]
#pagebreak()
```

## Nail Exterior to Platform
* Using panel nails and working from the outside of the home, nail through the wall paneling into the base of the platform frame
  about 1” above the bottom of the paneling, every 8” all the way around the home.
* Again, using panel nails and working from the outside of the home, nail the edges of the front and rear wall panels to the side-wall framing,
  about 1” in from the edges of the paneling, and 8” apart all the way from bottom to top of each corner.
* Verify that the exterior paneling is nailed to the frame around the top and sides of the front door.  If not, nail that at this stage (every 8”).

## Prep Interior
* Using a reciprocating saw (Sawzall), cut through the bottom plate of the front wall at each side of the doorway.  This should free the 2x4 so that it can be removed. These cuts should be exactly vertical, to preserve the doorway opening width.
* Use a knife to cut the Tyvek even with the top of the platform, and then use the Sawzall to cut the paneling at the bottom of the doorway
  so that it is flush with the top of the platform.
* Using the angle-iron gauge (in the pencil cup in #4 workstation) and an ink marker, draw a line down the center of each of the “magic” studs.
  These are the studs on the side walls at the rear of the second bay (4’ from the front wall).
* Using a speed square, draw a 6” mark on the subfloor where the center of each stud is.  On the top plate of each wall, mark (freehand)
  where the center of each stud is.  These marks will be used by the people installing wall panels.
* Using panel nails, nail the paneling to the platform across the bottom of the doorway.

`#pagebreak()`{=typst}

# Install Structural Triangles

## Setup 
* Position two 12-foot ladders, one at each end of the building.
* Preset brown #10x3” screws in each of two structural triangles, as shown in the diagram a couple of pages on from here.  In the two center bays,
  there are four screws, angled enough that you could drive them in with an impact driver.  In the two outer bays, there are two screws angled
  in from one side of the triangle, starting about ¾” in from the edge of the bottom plate.  Then there are two screws driven in vertically
  about 1” toward the center from the seam between the bottom plate and the angled side of the triangle.



`#pagebreak()`{=typst}

## Align Triangle

* Position a triangle on the front wall, and, with a helper inside the home, center it from side to side.



`#pagebreak()`{=typst}

* Verify that the bottom plate of the triangle is flush with the inside wall framing all the way across the front wall.
* Clamp the triangle to the wall top plate (or door opening) about 6" from each end.



`#pagebreak()`{=typst}

## Attach Triangle

* From the ladder, drive all the preset screws into the wall framing to secure the triangle.
* Repeat these last three steps on the rear wall.



`#pagebreak()`{=typst}

## Prepare for Half-Roof Installation

While these tasks are being completed, have two crew members position a half-roof assembly against each of the side walls, with the 1x8
white board at the bottom and facing away from the wall.

Check that there is a pencil line drawn at 6¼” from the front of the 1x6 board (the top of the half roof) all the way down and across
what will be the bottom of the half roof when it is installed.

Inspect the screws that hold the 1x6 board to the rafters, to make sure that the screw heads do not protrude from the surface of the board.
If any are found, drive them in so that the heads are flush with the board surface.

Fetch the two Funky Boards (#3 and #4), and position them near the side-wall jig.



`#pagebreak()`{=typst}

# Raise Half-Roofs
* Assign two experienced crew to the front and rear ladder positions.  Make sure each one has two clamps, a screw gun,
  and at least 4 yellow #8 x 1½" screws.
* Assign a third crew member to a 3-step ladder inside the home, to assist in final positioning of each half roof.  Position this ladder
  between the studs, not aligned with a stud, to avoid having a roof rafter come down on the crew member’s head.
* Introduce Funky Boards #3 and #4 to the crew.
* Gather the lifting crew; you will need 7 or 8 people
* Explain to the rest of the crew how the half roof assemblies will be raised. Five or six people will lift the half roof up about 4 feet
  off the floor, and then two funky-board wielders will push it up so that the two ladder crew and the interior person can lift it the rest
  of the way up.  Warn these two to push up at a 45° angle, so that the half-roof slides onto the building instead of falling backwards onto the crew.
  Remind the rest of the crew on the ground to take notes, because they will get to do the second half-roof.
* Lift the first half-roof.

```{=typst}
#scale(78%, reflow: true)[#image("images/image_39.png")]
#scale(78%, reflow: true)[#image("images/image_40.png")]
#pagebreak()
```
## Align First Half-Roof
* The ladder crew guide the 1x6 white board into the central notches in the structural triangles.  If necessary, the ladder crew may ask for help
  from the people on the funky boards, to lift (temporarily) the rafter ends either at the front or rear so that the half roof is properly positioned.
* Then the front ladder person aligns the assembly so that the mark on the half-roof is even with the outer edge of the front structural triangle.



`#pagebreak()`{=typst}

## Raise Second Half-Roof

* Rotate ground crew members who were standing out, and position everyone on the other side of the home for the second half roof lifting.
* Once the ladder crew have repositioned their ladders, lift the second half roof into position.



```{=typst}
#scale(78%, reflow: true)[#image("images/image_45.png")]
#scale(78%, reflow: true)[#image("images/image_46.png")]
#pagebreak()
```
## Connect Half-Roof Assemblies

* The front ladder person leads the alignment of the two half roof assemblies, so that the ends of the 1x6 boards are flush.  Once this is done,
  both front and rear ladder crew clamp the 1x6 boards together both horizontally and vertically.  Placing the vertical clamp first allows
  the boards to slide past each other more easily before applying clamp pressure horizontally. Then drive 4 #8 x 1½ screws into the white
  boards, to secure the two halves together.





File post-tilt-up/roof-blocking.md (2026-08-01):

```{=typst}
#title-page[
  #text(36pt, weight: "bold")[Roof Blocking]
  #v(1em)
  #block(width: 60%)[#align(left)[#text(24pt)[Create Ridge Beam\
  Attach Rafters to Walls\
  Install Bird Blocks\
  Install Vent Blocks]]]
]
```

# Create Ridge Beam

* In each bay (between the rafters), clamp the two white boards together, first vertically and then horizontally, to align them and make a tight joint.
* insert four #8 x 1½" (yellow) screws, two above and two below the centerline, and about 4” from the rafters.  Alternate directions of the screws
  from one bay to the next.





`#pagebreak()`{=typst}

# Align Half-Roof with Walls

* Using the angle-iron guide in Station #4, mark the centerline of the “magic” rafters; these are the ones to the rear of the second bay.
* Align the “magic” rafters with the stud just below them.  Using a clamp, pull each of these rafters either forward or back so that it
  lines up exactly with the wall stud immediately below it.  If necessary, have a second person use a mallet to assist.  The place to aim
  the mallet is on the outermost rafter at the point where the lowest block is screwed to the rafter.  If you hammer on the rafter end,
  something will split.



`#pagebreak()`{=typst}

# Install Magic Stud Lag Bolts

* Install lag bolts in these two rafters, screwing them down into the top plate of the side wall.



`#pagebreak()`{=typst}
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

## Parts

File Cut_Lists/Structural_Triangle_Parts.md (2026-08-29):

---
no-title-page: true
---

# STRUCTURAL TRIANGLE PARTS

`#align(center)[== CUT FOR 6 HOMES (12 triangles)]`{=typst}

`#align(center)[#rect(stroke: 0.5pt, inset: 4pt)[#image("images/triangle_parts.dxf", layers:"0,Z-Labels")]]`{=typst}

Cut these (rough) lengths of 2x4, and place them on a yellow cart.

| Quantity | Label | Length | Notes |
| --- | --- | :--- | :--- |
| 12 | B | 89 5/8" | Use 8' 2x4 |
| 12 | A | 96" (no cut needed) | Use 8' 2x4 |

Using the green chop saw and jig (set up for 18.5° angle cuts), trim
both ends of these. The longer one is used below for A pieces

Set the (red) back chop saw to an 18.5° angle, and trim the following,
setting each 2x4 on the saw table standing on its shortest edge:

| Quantity | Label | Length | Notes |
| --- | --- | :--- | :--- |
| 24 | A | 41" | Cut two pieces from each blank, being sure that the long point previously cut is against the back rail and even with the stop |
| 24 | D | 6-³⁄₁₆" | From scraps or 12" scrap blocks |
| 24 | E | 11-⁹⁄₁₆" | From 12" blocks |

Set the back chop saw back to 0°. Cut

| Quantity | Label | Length | Notes |
| --- | --- | :--- | :--- |
| 12 | C | 11-⁵⁄₁₆" | Use 12" scrap blocks |
| 24 | E | 11-⁵⁄₁₆" | Cut the tip off the slanted end of each piece |

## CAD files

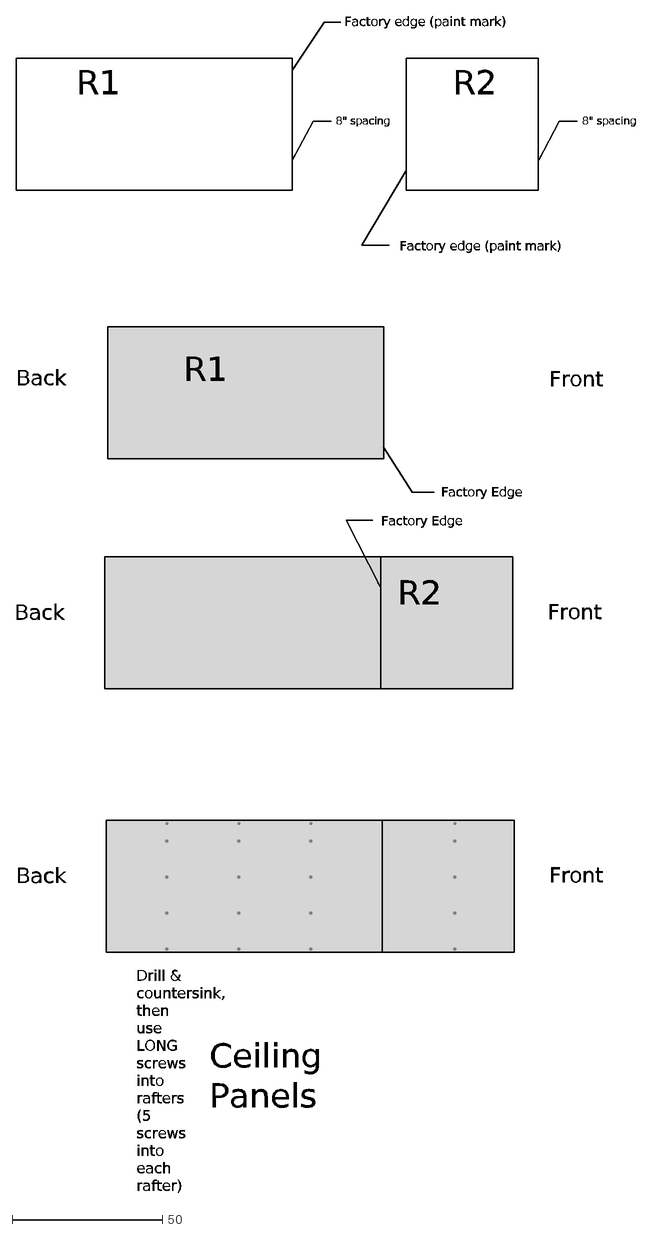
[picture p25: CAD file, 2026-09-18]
Interior_Panels/images/ceiling_panels.dxf
R1
R2
Factory edge (paint mark)
Front
Back
Factory Edge
Drill & countersink, then use LONG screws into rafters (5 screws into each rafter)
8" spacing
Ceiling Panels

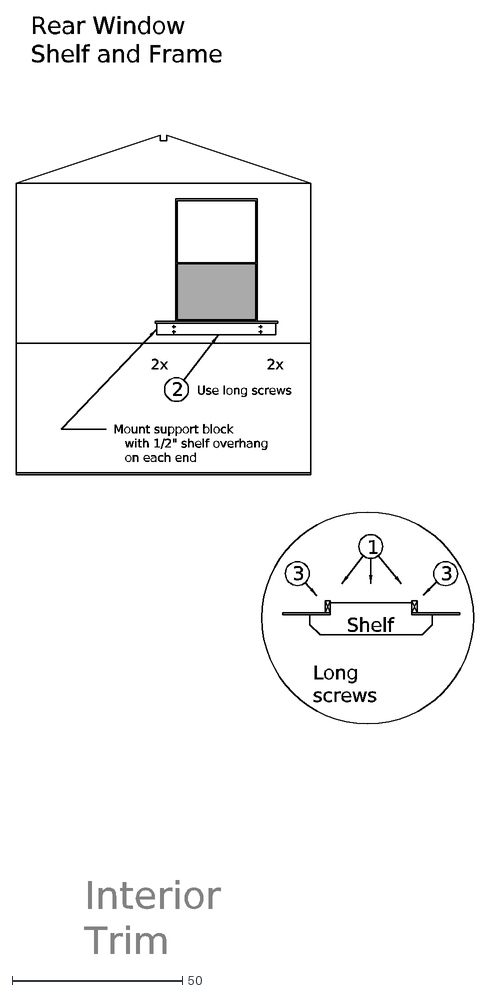
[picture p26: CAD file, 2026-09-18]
Interior_Trim/Images/rear_window.dxf
1
2
2x
3
Rear Window Shelf and Frame
Shelf
Long screws
Use long screws
Mount support block with 1/2" shelf overhang on each end
Interior Trim

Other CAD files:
Cut_Lists/images/triangle_parts.dxf
Exterior_Trim/images/rear_window.dxf
floor_door/images/door_preparation.dxf
Front_Wall/images/front_wall_ada.dxf
Half_Roof/images/half_roof.dxf
Interior_Trim/Images/vent_cap.dxf
Misc/empty_dwg.dxf
Platform/images/platform.dxf
Rear_Wall/images/rear_wall.dxf
Roof/images/panel_options.dxf
Side_Walls/images/side_wall.dxf
Structural_Triangle/triangle.dxf
Exterior_Trim/images/front_window.dxf
floor_door/images/flooring.dxf
Interior_Panels/images/wall_panels.dxf
Roof/images/start-end.dxf
Exterior_Trim/images/back_corner.dxf
Exterior_Trim/images/triangles.dxf
Interior_Trim/Images/combo_trim.dxf
Interior_Trim/Images/front_window.dxf
SketchUp/Tiny_Home_Model_-_Iron_Cart_Removal.skp

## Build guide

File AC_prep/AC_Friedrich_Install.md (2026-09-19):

```{=typst}
#title-page[
  #text(32pt, weight: "bold")[Air Conditioner Installation]
  #v(1em)
  #text(24pt)[Friedrich Model CCW06B10C]
  #v(0.5em)
  #text(24pt)[6000 BTU Window A/C]
]
```

# Air Conditioner (AC) Prep and Install

## Tools needed

- 8mm wrench (or 5/16") and socket (socket set)
- Phillips screwdriver
- scissors to cut strapping
- white rolling cart

## Prepping the AC Unit

-   Cut strapping on the AC box. Pull up on the top of the box leaving the AC sitting on the box bottom

-   Check all corners, control panel, etc. for shipping damage. If damaged, reinstall box top, tape shut and leave a note on blue tape
    of the damage. The AC will be returned to Lowe's for replacement.

-   If the AC unit is in good condition, lift the unit and place on a white rolling cart.

-   Remove shipping tapes and tags from the AC

-   Plug in the AC and make sure it is operating. If not operating, put it back into the box for return/replacement from Lowe's, with a blue tape note

-   Remove all the installation pieces from the box.
    Not needed:
    - accordion side pieces
    - white metal bracket
    - white foam boards
    - install and operating manuals
    - bag of parts that also contains the 2 AA batteries

-   Set aside the remote, its batteries, and black foam pieces

-   Needed to install
    - R and L triangle brackets
    - package of machine screws & nuts (not battery bag)
    - roll of black foam insulation

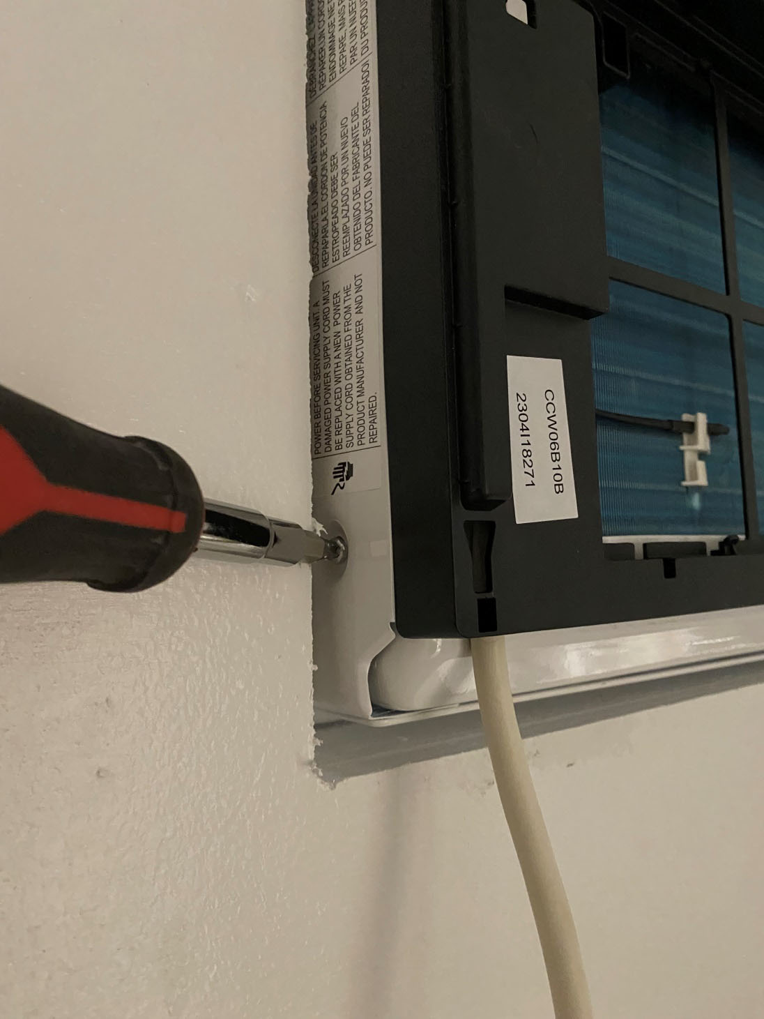
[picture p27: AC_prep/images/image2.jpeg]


-   Remove the Phillips screw located on the lower left side near the front, set aside

-   Open the front, white cover by pulling forward on the sides near the top. Lift and remove the cover.

-   Remove the air filter and set aside with the white cover

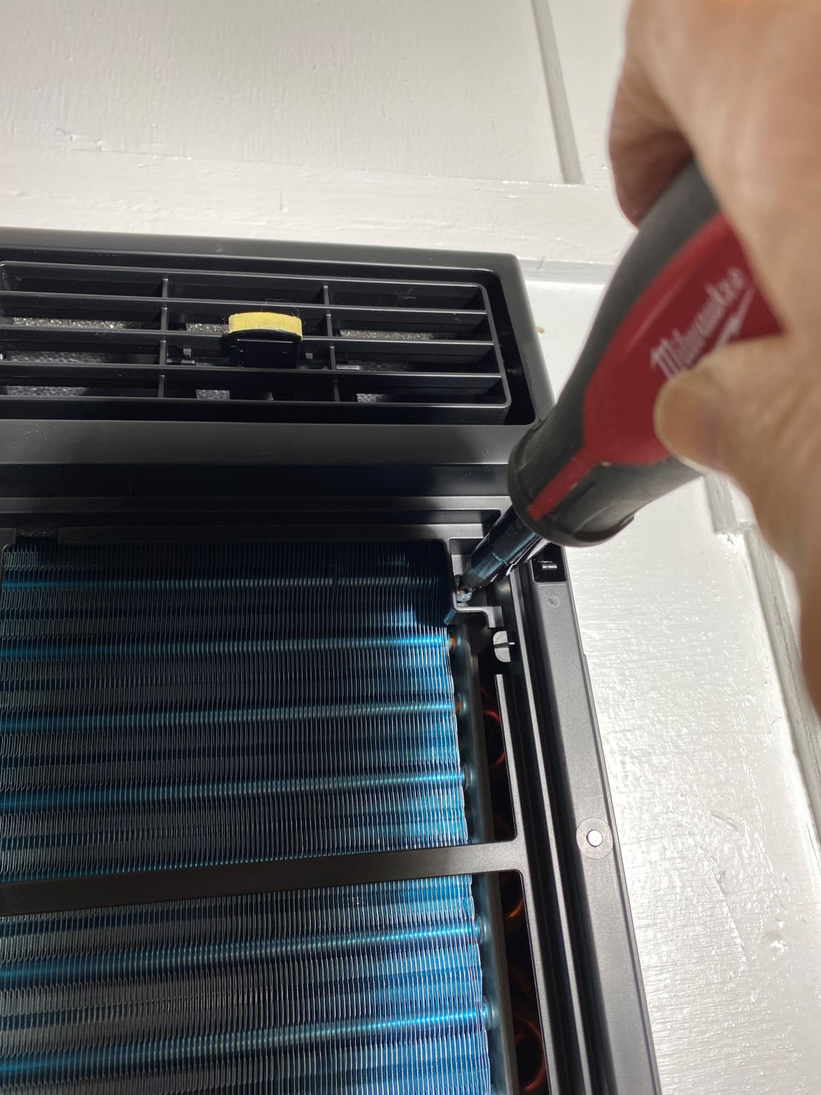
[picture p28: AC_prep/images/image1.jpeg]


-   Remove the 2 Phillips screws that hold the black front cover. The screws are about 2" from the top on either side (right side shown); set screws aside

-   Push outward on the black plastic cover at about 4" from the bottom on each side. This will release the clips holding in the lower part of the cover.

-   Once the lower clips are released, lift the black cover to release the top clips. The cover will remain attached by the wiring.

-   Fold the black cover over so it rests on the top.

-   Position the AC on the cart so it can be tipped up on the front, turn the AC so it is resting on the front being careful with the power cord
     and front cover wiring.

-   Once the AC is on the front, pull up on the outer shell of the AC. You may need to wiggle the outer cover to get it to lift up. Set
    aside the outer shell.

-   Turn the inner AC back on its bottom. Reinstall the black cover using the 2 screws (see photo).  Install the lower left side screw (see photo).

-   Install the air filter and white cover.  Note that the air filter has two projections at one edge. These are handles,
    and should face outward at the top.  Then, engage the bottom of the filter with the guides at the bottom of the opening, and then flex
    the top of the filter to tuck the upper corners behind the guides near the top of each side of the opening.

-   Place the inner AC part back in the bottom packaging. Replace box top and set unit aside to be installed just before the home is ready
    to leave the Hope Factory.

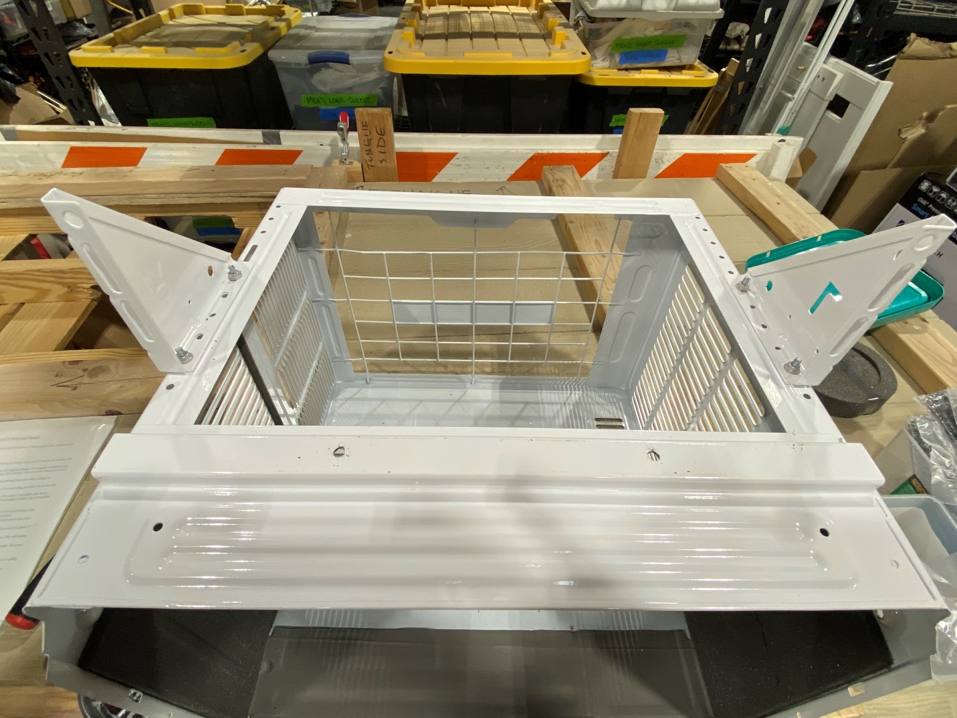
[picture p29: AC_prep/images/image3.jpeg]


-   Turn the outer part of the AC upside down. Install the R and L triangle brackets to the bottom of the unit using the four 5/16" (or 8mm)
    bolts and nuts. Insert the 5/16" bolts from inside the cover so the nut is installed on the bracket side. The front hole of the
    bracket should line up with the second hole in the cover closest to the front (see photo). The back hole in the bracket aligns with
    another hole in the AC cover. If installed with the nut inside the cover, the inner AC unit won't slide in later. Tighten the nuts securely.

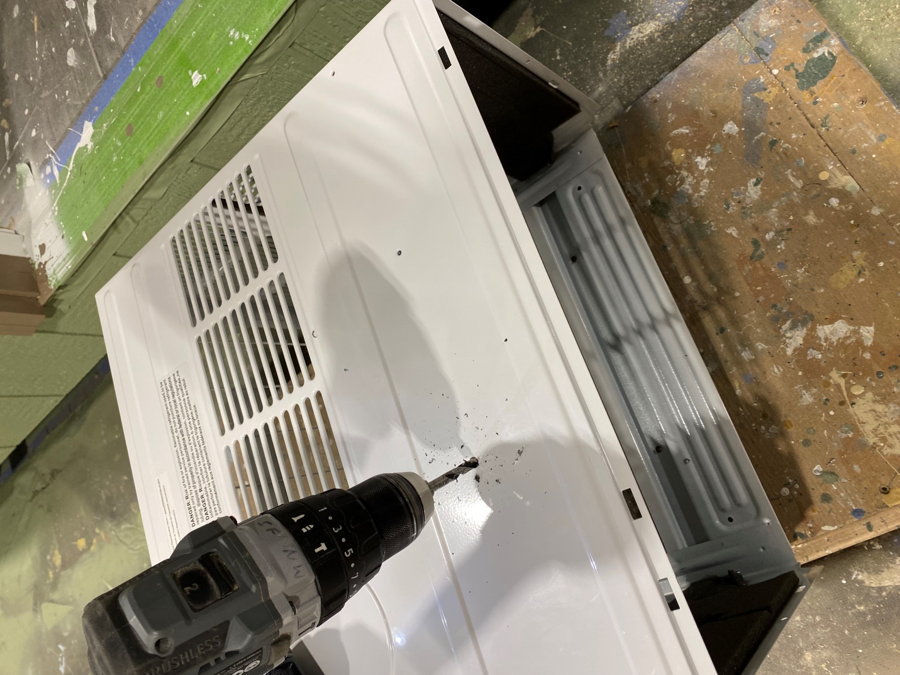
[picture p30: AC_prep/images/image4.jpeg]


-   Using a 3/16" bit and drill motor, drill two holes in the outer part of the AC cover. Drill through existing dimples on the top of the cover.
    At the bottom, drill both holes through the bottom support rail, approximately opposite the upper holes.

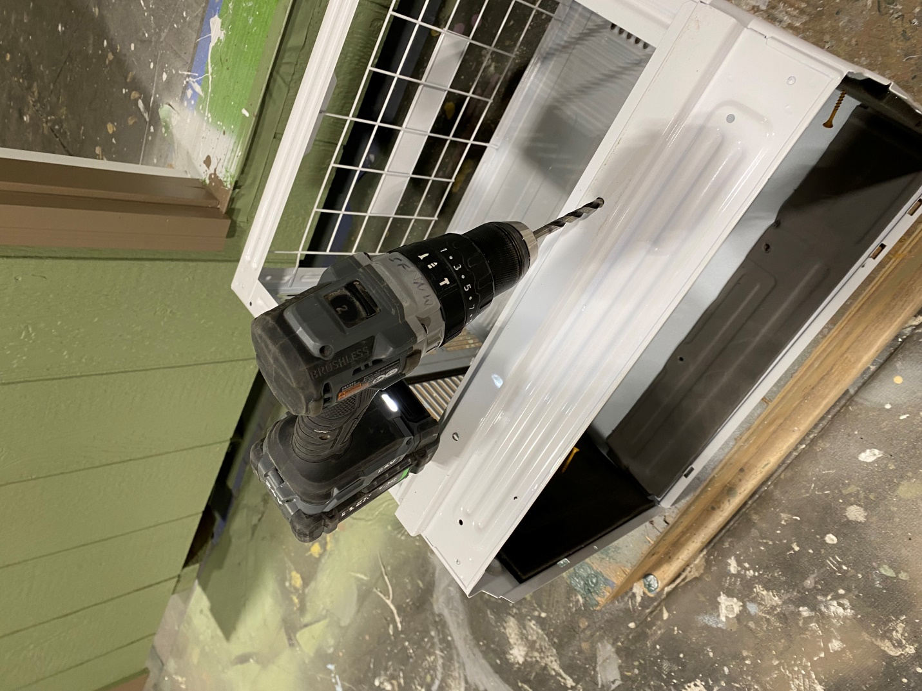
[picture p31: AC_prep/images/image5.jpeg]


## Installing the AC Shell

-  Tools needed

    - impact driver with ¼" hex driver bit (station 1) and Torx bit
    - Drill motor with spade bit
    - Sawzall with long blade

-  Supplies

    - 6 Simpson screws (station 1)
    - 1-5/8" tan (yellow) Torx screws
    - Wood shims

-  After the interior plywood is installed in the home, and A/C cutout is routed out from inside paneling

-  Using the spade bit in a drill motor, bore two holes in the siding from inside the building; one at the lower right
   and one at the upper left of the A/C opening.  Using the Sawzall, cut the siding even with the 2x4 framing up from the lower right starting hole
   and then left across the bottom of the framing.  Finally, saw down from the upper right and then across the top of the opening.
   This will allow the cutout to fall away from the saw when it comes free.  Trim the corners square where the starting holes were.

- Verify that the interior plywood and exterior siding are flush with the 2x4 frame opening. Trim as needed.  Clean out any sawdust in the opening.

- Slide the AC outer part into the back of the home, one person inside to support it and another outside to install the screws into the brackets

- Adjust side to side as needed. The front, bottom support rail of the AC cover rests on the 2x4 framing.

- Install 2 Simpson screws in the upper holes of the support brackets; one on each side. Install 4 Simpson screws in each bracket on the
  lower holes, 2 on each side.

`#pagebreak()`{=typst}

- Install two 1-5/8" tan screws through the bottom of the AC outer shell into the 2x4 framing.

- Insert shims between the top of the box and the 2x4 framing, and install two 1-5/8" tan screws through the top of the AC outer shell
  into the framing. Make sure the outer top part of the AC isn't bent by the screws.  Otherwise, the black front cover will not install correctly.

- Install larger foam weather stripping that comes with the AC along the bottom of the box.

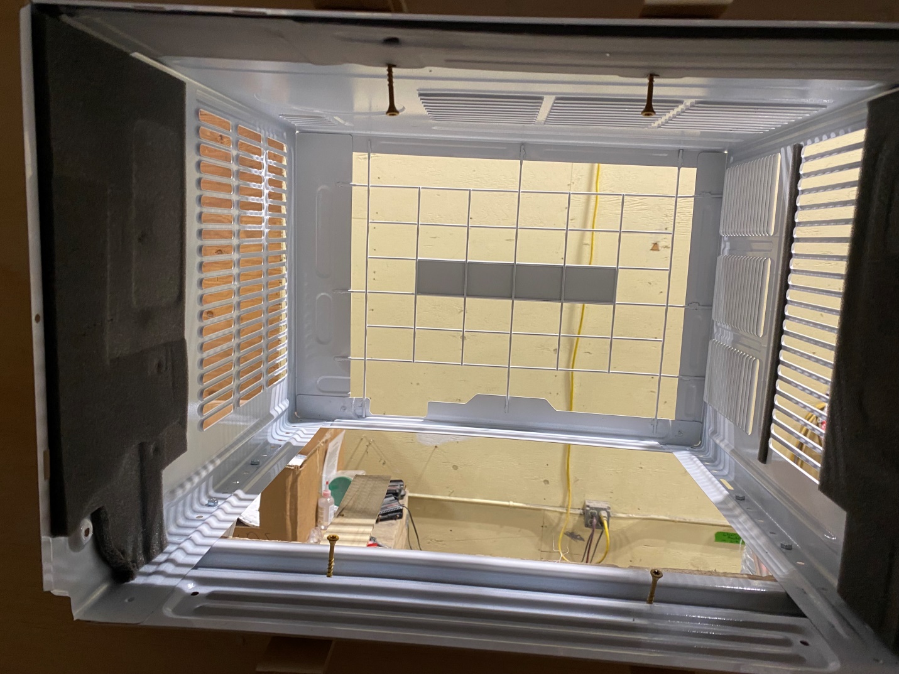
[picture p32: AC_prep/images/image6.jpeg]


This completes the installation of the AC outer unit. The exterior and interior trim can then be installed.

## Installing the AC inner unit

Tools -- Phillips screwdriver

- Move the AC inner unit inside the tiny home. Remove the cardboard box top and take the inner unit out of the box bottom.

- Open the white front cover, lift, remove and set aside along with the air filter.

- Remove the lower left side screw (see photo on page 2).

- Remove the two screws holding the black plastic cover. (see photo on page 3)

- Insert and slide the AC inner unit into the preinstalled outer cover being careful of the attached wiring to the black cover. The inner
  AC unit should slide fully into the cover so the holes on the lower left side line up. Install the single screw on the lower left
  side (see photo).  This is all that holds the inner and outer parts together.

- Install the black plastic cover by aligning the top clips and then aligning the lower right and left side clips. Tap the side clips to fully seat.

- Install the two screws in the black cover

- Re-install the air filter and white cover (insert bottom pins first and push in the top of the cover)

- Plug in the AC and verify it is working

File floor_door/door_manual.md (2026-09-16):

```{=typst}
#title-page[
  #text(24pt, weight: "bold")[Converting Steel Door]
  #v(1em)
  #text(24pt)[Installing ADA door]
]

#let imgCtr(path) = {align(center + horizon)[#image(path)]}
```
# Steel Door Conversion

To replace a standard threshold with an ADA-compliant threshold, here
are the steps:

1. Place the door (hinges up) on a flat work surface, with the
    threshold end hanging off.

1. Drive out the hinge pins, remove the latch-side plug and screw, and
    remove the door from the frame. Save the plug and screw for door reassembly at the end.
    Set the door aside.

1. Remove weatherstripping from all three sides of door frame.

1. Measure from the outside top of the door frame down along each side,
    and mark on the frame at 80-3/4”. Extend these marks onto the inside
    surface of the frame.

1. Install a cross brace on the door frame above the bottom hinge,
    using square-drive 1½” screws with big washers to secure the door
    frame. Position the brace so that the distance from the brace to the
    bottom of each door frame leg is the same.

1. Using a 2x4 block and a mallet, drive one end of the standard
    threshold out of the frame, and then gently pry it loose from the
    other side of the frame, leaving the bent staples in place. Remove
    the standard threshold assembly and save it for LIHI.

1. Pre-drill and countersink into the top brick-molding 1” in from each
    corner, and drive a 3” brown screw into the hole, to stiffen the
    corners.

1. Carry the frame to the back chop saw, and, with a helper, carefully
    position the frame so that you can cut one side of the door frame
    exactly at the mark (leave the mark). Reverse the frame, and cut the
    other side exactly on its mark.

1. Return the frame to the work table, and install the router guides on
    each of the door frame legs. (They are different, one is labeled
    “Hinge Side” and the other “Latch Side”).

1. Use the end-cut router from the black cabinet, whose depth has been
    preset. Carefully insert it into the guide while it is running, to
    begin the cut through the door-stop. Cut down just far enough to
    clear the bottom edge of the door-stop, and remove the router.
    Repeat on the other side

`#fullpage("images/door_preparation.dxf", layers:"2_Door")`{=typst}

11. Remove the routing guides, and place a tarp under the door frame
    legs. Using the rattle-can of Kilz primer, spray the cut surfaces.
    Allow to dry (30-60 min).

1. Using one of the pre-trimmed ADA thresholds (exactly 36” long),
    drill two clearance holes for \#6 drywall screws, about ¼” in from
    the ends, and 1½” from one side. Remove the burrs from the opposite
    side.

1. Position the threshold so that the inner edge of the threshold is
    flush with the inner (upper) edge of the door frame, and with the
    clearance holes down. Drive a 1¼” drywall screw into each of the
    clearance holes, being careful to drive them straight in or slanted
    a little towards the outside of the door frame, so that the
    door-stop does not split.

1. Remove the cross brace from the frame, and reinstall the door. Drive
    in the hinge pins, and secure the door with the plastic peg and
    thumb screw that you saved when you removed the door.

`#pagebreak();`{=typst}

# Installing a Door

## Tools/Materials
- Drill with countersink bit
- Screw gun
- Phillips-head drive bit
- T25 drive bit
- Shims
- Chrome T25 screws
- \#10 x 3" Screws (brown)
- Utility knife
- Pry bar
- Yellow clamps (2)
- Flexible Flashing (54" strip)
- Precut plywood filler 4½" x 37½".  Stored on shelf near door storage.

## Pre-checks
- Verify that the door has been modified with a ¼" thick ADA threshold.
- Verify that weatherstripping has been removed.
- Verify that the home's flooring extends only ¾" into the door opening
- Verify that the doorway opening is at least 37¾" wide at its narrowest point.  If not, ask for help.
- Verify that a separate flooring strip 3½" wide is installed in the doorway, flush with the outside of the siding.
- Verify that all labeling, bottom plastic protectors and hinge protectors have been removed.

`#pagebreak()`{=typst}

# DOOR INSTALLATION

## Prepare the door

- Free a door from the shipping pallet using a Phillips-head bit on a screw gun
- Unscrew plug retainer where doorknob will go, leaving the plug in place

## Prepare the opening

- Cut a 54" length of flexible flashing (Peel-n-Stick), and install it in the bottom of the doorway over the flooring strip, with about 8" running up each side of the opening, and half the width sticking outside the home. Do not cover any of the interior floating floor.
- Slit the corners of the flexible flashing, and fold the outer half of the flashing down and to the sides of the opening.
Press the flashing into the corners of the doorway.

`#imgCtr("images/door_preparation.dxf", layers:"3_Threshold")`{=typst}

`#pagebreak()`{=typst}

##  1. Install the door

- With 2 helpers, insert the bottom of door frame into the opening, leaving the top of the door leaning out from the building.
- Push the Locking plug into the doorknob hole to free the door
- Tilt the door frame upright into the opening, and tight against siding
- Make sure that the door frame is seated firmly on the bottom of the doorway.  **Do not step on the threshold** to seat the door.
  Use a prybar at the top corners if necessary to push the sides of the door frame down so that they are in contact with the flooring. 
- Helpers hold door frame tight against siding.  Use a clamp if necessary.
- Mark the screw locations with a pencil.

`#imgCtr("images/door_preparation.dxf", layers:"3.1_ScrewLocs")`{=typst}

`#pagebreak()`{=typst}

- Insert SHIMS as necessary to center the door in the opening and tighten any spaces
    - hinge side, place shims just above each hinge, centered vertically where each screw hole has been drilled
    - doorknob side, place two shims, one high and one low, centered vertically where screw holes have been drilled
    - Adjust side shims so the gap at the top is the same across door width

`#imgCtr("images/door_preparation.dxf", layers:"4_Shimming")`{=typst}
`#pagebreak()`{=typst}

##  2. Adjust and secure door frame
- Open & close door - it should not hit door frame on the side opposite the hinges (\~1/8" gap)
- Screw door frame to the opening on the hinge side
    - open the door
    - make sure door molding is tight against the siding
    - install 3" (brown) screws in each pre-drilled hole, starting at the top
- Screw door frame to the opening on doorknob side
    - top 1^st^
    - bottom 2^nd^
    - screws must go through shims, so that the door frame is not distorted
- If space above the door is narrow, use shims to make it even, if large then use a piece of 3/4" plywood, and then shims
- Insert shims 8-10" in from each side to fill space between top of door frame and the plywood or doorway framing
- Install screws as for the sides.

`#pagebreak()`{=typst}

## 3. Strengthen door latch plate
- insert shims both above and below the latch hole
- adjust shims above and below latch hole so the gap between door and door jamb is approximately 1/8" 
- Drill with countersink bit about 1" above and below the latch hole, as shown in the drawing
- Angle drill towards outside of the home, to assure that screws will go into the framing
- Install 3" screws in both drilled holes, and through the shims.  Make sure that the screw heads are sunk below the surface of the door frame.

`#imgCtr("images/door_preparation.dxf", layers:"5_Strike Plate")`{=typst}

`#pagebreak()`{=typst}

## 4. Finishing

- Install three silver screws into the holes in the metal threshold.  Do not overdrive these screws; it will distort the threshold.
- Remove one of the Phillips-head screws from each hinge, replace with 3" silver screw from kit. Discard the short screw.
- Trim off the protruding ends of the shims flush with the wall plywood. Use a box knife to score the shim, and then snap it off.
- Trim off the flexible flashing flush with the outer edge of the door trim (brickmold) on both sides of the door.
- Using a piece of 2" trim as a guide, cut the flexible flashing beneath the threshold, leaving only the upper 2" exposed.

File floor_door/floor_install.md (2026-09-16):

```{=typst}
#title-page[
  #text(36pt, weight: "bold")[Floor Installation]
]
```

# Floor Installation

## Preparation
- Clean interior with blower, twice, including window frames and A/C cutout
- Collect tools and material:
  - 4½ to 5 boxes of flooring; use ripped planks if available
  - Knee pads, safety glasses, ear protection, gloves
  - Black marker, pencil, tape measure, utility knife, speed square, blower
  - Flooring cutter, jig saw, mallet, tapping blocks, small pry bars, tapping bar
  - Spacer strips of flooring
  - Blue masking tape
- Verify that there is a limit line in the doorway, to show how far the flooring should extend.  This line should be ¾" from the inside of the wall framing to the line.  If it is not there, draw one.
- Tape spacer strips to the the starting side wall and the back wall, using blue tape.  These spacer strips should rest on the sub-floor, and are used to ensure space between the flooring and the walls.

`#pagebreak()`{=typst}

## First Row – next to side wall on door side of home

- Assemble first row from three full lengths (or use 3 ripped pieces from a previous floor).
    - The wide gray tongue on the long edge should face the interior of the home
    - Trim off the gray tongue from the short edge that will face the back wall.
    - Engage short edges, and align exactly, and, using a block to protect the flooring, tap the joints together with a mallet.
- Place this string of flooring against the side wall, using blocks to assure space. Measure from the end of the string to the limit line.
    - Cut last length to this dimension.
    - Mark the last length of flooring where it must be cut out, and use a speed square and black marker to draw lines for the cutout.
    - Use a jigsaw to cut out the corner behind the door, as shown in the diagram.
- Use spacers against the walls to insure ¼” gap

## Intermediate Rows
- For even numbered rows, start with 2’ length; add 2 full lengths, and then use remainder of cutoff at the door end.  For odd numbered rows, start with a full length.
- For odd numbered rowsm, trim off the gray tongue from the short edge of the first piece where it faces the wall.  Use a spacer to insure ¼” gap from the back wall
- Tilt each plank up about 30°, and engage the short edge with the flooring already placed, leaving just enough gap along the
long edge for the thin gray tab. Then tilt the previous plank and the new one up just enough to tap the new plank in to engage the previous row. 
  Tap the joint with a tapping block and mallet to seat the plank.  When correctly engaged, the new plank will lie flat on the floor,
without any springiness.
- Trim last length to match limit line in doorway (¾” towards outside from inside of interior wall) One of these finishing lengths will need a corner cut out where it meets the doorway.
- For rows that meet the front wall instead of the doorway, reverse the last plank (or partial plank) so that its wide locking tabs face
the starting wall and the front wall.  Place the last plank against the front wall, and mark where it overlaps the brown surface of
the previous plank in that row.
- Cut the plank at the mark, and then install it normally.  The wide gray tab that was against the front wall now slides under the previous plank, so that when you tap it into place, there will be ¼" of space between the finished floor and the front wall.

`#horizontal-center("images/flooring.dxf", layers:"FloorTiles,Notes")`{=typst}

`#pagebreak()`{=typst}

## Last Row
- Measure distance from brown edge of last intermediate row to side-wall in several places.  If the measurement varies more than ¼”, cut each piece so that there will be ¼” gap between the floor and the wall.  Otherwise, use the minimum width for all three pieces.
- Using the table saw set up for this, rip pieces to the required width above.  Save the remaining partial pieces for the next floor, if they are wider than 3"; otherwise, discard them.
- To complete assembly, use the small pry bars as hooks to engage the last row with the rest of the floor, and then either tap the planks together using the tapping bar, or else use the small pry bars to apply force.  The flooring should lie flat when the joint is seated correctly.
- If the last row pieces were all the same width, and you have 3 left-over full-length cutoffs, wrap them with blue tape, and save these as a starter row for the next home.

## Doorway
- Place a 3” strip of flooring across the doorway, flush with the outside of the building.  Nail it in place with 3 or 4 finish nails.
his will be secured with flexible flashing when the door is installed.  The strip can either be a single 36” piece, or be made up from scraps interlocked together (e.g. 4 x 9” = 36”).

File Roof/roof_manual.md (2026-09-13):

```{=typst}
#title-page[
  #text(36pt, weight: "bold")[Roofing]
  #v(1em)
  #text(24pt)[Material Preparation]
  #v(0.5em)
  #text(24pt)[Roof Installation]
  ]
```

`#set text(14pt)`{=typst}

# Material Preparation
  The preparation steps here are intended to make roof installation easier by minimizing the number of trips that installers need to make up and down the steps of the skybridge scaffolding.

## Tar Paper
 - Cut 4 lengths at 13'4".  Line up the front edge of the roll with the front of the workbench, and roll out enough tar paper to reach
the stop at the far end of the workbench.  Then lay a straight-edge cutting guide lined up with the left ink line on the workbench at the right end,
near the roll of tar paper.  Cut with a razor knife.  Roll each length and secure with blue tape.
 - If the end of a roll is too short, add a second piece long enough to reach 13'4" and then another 12", to allow for overlap between the two parts.

## Metal Flashing
 - We need two end pieces and two eave coverings, which will be in two parts.
 - The end flashing is 117" long.  Cut from a 10' stick, and then cut the outer edge only at 58½".  The outer edge is the one with a ½" flange.
 Do not cut through the flat half of the flashing.
 - Each eave requires two pieces: a 10' solid piece, and a 40" piece.  Together, these will span the length of the eave.
 - Bundle these 6 pieces together and secure with a bungee-cord loop around them.

## Shingle Prep
  To insure that seams between shingles do not line up and permit water to penetrate the roof, we create start and end shingles
of different lengths.  In between, for each course, we need 3 full-length shingles.  The length of the start plus end shingles is 42".
We will create two sets of start and end shingles, one for each side of the roof.

  We cut shingles to length using the "shingleator", a large cutter.  Shingles must always be placed with the gravel side down on this cutter,
to make the cuts cleanly.

  In warm weather, the tar strips may soften and melt.  To avoid ruining shingles that might stick together in this situation, we always stack
shingles alternating face down and face up.  This minimizes the likelihood that shingles will be damaged as they are pulled apart during installation.

`#pagebreak()`{=typst}

### First 8 Rows -- Making the Start/End Shingles
 - Cut 3" off a shingle to start. (There is a mark on blue tape to the right of the cutter blade for this.)  The 3" piece is scrap.
 - Line the remaining shingle up with the stop at the left end of the shingle cutter, and place a second shingle next to it on the cutter.
 - Cut the second shingle.  The two adjacent pieces to the left of the cutter knife are a start/end pair.
Start two piles with these, gravel side down.
 - Move the remaining piece to the stop, and place a whole shingle up against the edge of this piece. Cut this shingle.
 - The two pieces left of the cutter are a start/end pair for the second half of the roof.  Start two piles with these, gravel side down.
 - Repeat the process using the scrap and a whole shingle, this time placing the shingles gravel side up.  Alternating shingles in this way
reduces the problem of them sticking to each other in warm weather.
 - Continue the sequence for a total of 2 sets of 10 pairs, stacking the pieces alternately gravel side down and gravel side up.
When the scrap width is less than 3" discard it, and begin again, trimming 3" off a whole shingle.  This should occur after
5 rows of start/end pairs have been cut for each side of the home.
 - Separate the top 2 pairs in each set and use them for the next two steps.
 - Place a separator flag on top of the left (start) stack and pile the right (end) stack on top of the left.  Using two pink plastic wrappers,
wrap this bundle, and mark it with "1-8" using yellow crayon.
 - Repeat for the remaining two stacks. This creates a start/end bundle for each side of the roof.

`#align(center)[#rect(stroke: none)[#image("images/start-end.dxf", width:70%, layers:"0")]];`{=typst}
`#pagebreak()`{=typst}

### Row 9
 - This row needs the top 1½" cut off, so that the remaining shingle reaches just to the edge of the vent block openings.
 - Clamp a T-square to the back edge of the work table, pressing the short part of the T against the edge of the table.
 - Place each shingle face down under the T-square clamped to the work table, and line up the inner edge of the upper black adhesive strip with the T-square.  Using a box knife, cut the shingle lengthwise, and save the narrow strip for packaging.
 - Cut 6 full shingles down in this way, stacking 3 shingles alternately gravel-side down and gravel-side up. Add two narrow strips after the 3rd
 shingle.
 - Cut two start/end pairs down the same way, stacking each pair on top of the full-length shingles.
 - Mark each pile with "9" using yellow crayon, and bundle each stack using pink plastic wrappers.

### Row 10 -- Final Row
 - This row needs the top half cut off, so that its top edge matches the top edge of Row 9, and does not obscure the vent block opening.
 - Place each shingle face down under the T-square as above, but line the shingle up so that the bottom edge of the lower adhesive strip is
 even with the T-square edge.
 - Cut 6 full shingles down with the box knife, stacking these in the same way as Row 9. Cut two start/end pairs down the same way.
 - Mark each pile with "10" using yellow crayon, and bundle each stack using pink plastic wrappers.
 - The cutoffs from the 6 full shingles can be used for the Starter Course, below.

### Starter Course
 - This row uses special single-layer shingle material.  We need 14 pieces for a full roof.  Some of these can be left-over cutoffs
from the Final Row, above.  The rest are prepared by tearing a single-layer shingle in half lengthwise, along the perforation.

### Ridge Cap
 - These 30 to 33 small shingles are supplied as tear-offs, 3 to a sheet.
 - We need 11 sheets.

### Ridge Vent
  - If there is no scrap length of this material, retrieve a full 20' roll and unroll most of it on the workbench.  Line up the left end
with the stop at the end of the workbench, and flatten the material out all the way across the workbench.  There is a mark on the bench to
indicate where to cut the vent; it should be 161½"
  - If there is a scrap length, place it on the workbench up against the stop on the left, and unroll an additional length of material from
another roll.  Butt this up against the scrap length, and cut the roll at the mark at the right end of the bench.  Save the left-over piece
for the next vent.

`#pagebreak()`{=typst}

# Roof Installation

## Setting up

 - Close the drain stopper on the bottom of the air compressor (under) the shelves in the middle of the building).
 - Turn on air compressor.  There is a switch on the power strip strapped to a shelf corner leg above the compressor.
 - Unlock the nailers from the skymobile.
 - Add 3 drops of air gun oil into the compressed air connector on the framing nailer, and attach the air hose to it.
 - Collect all the prepared roofing material, and stack these on a cart in reverse order of use, so that the top items are the first to be installed:
 	- Tear-off Cap shingle set
	- Row 10 Shingles
	- Row 9 Shingles
	- 2 sets of Row 1-8 Start/End Shingles
 	- Starter Row shingle bundle
 	- Tar paper rolls
 	- 4 Fascia Boards with 18½° cut on one end.  You need 2 left-hand and 2 right-hand pieces
 	- 4 Soffet Boards (1x6) precut with 18½° bevel on one end

 - Separately, carry bulky items to the Skymobile, and put them on the bottom shelf:
 	- Metal Flashing bundle
 	- Ridge Vent
 	- Rolls of Flexible Flashing
 	- 2 or 3 bundles of full-length shingles (unload these onto the Skymobile hoist platform)

- Load a panel cart with pre-cut ¾" plywood, and wheel it to the work area.
- There should be framing nails, roofing nails, staples, and hurricane clips on the skymobiles
- Locate a plastic bag of shingle dust on the skymobile; it will be needed at the very end of roof installation.

`#pagebreak()`{=typst}
 
## Plywood Deck
 - There are two options for each half of the deck, as noted in the Material Preparation section: either 2 equal-width sheets, or 3 unequal pieces.
 - In the first option, the sheets line up with the center rafter; in the second, the seams do not.
 - In the second option, use three hurricane clips on each seam, evenly spaced, to insure that the roof deck is a single plane.  If the plywood pieces cannot be made to line up because of bowing, ask for help from the factory manager.
 - Position the plywood tight against the 1x8 white board at the bottom of the half roof.  Line up the ends of the roof with the end rafters.  The plywood may not extend all the way to the outer edge of the rafters; a difference of ½" is acceptable.
 - Use the pattern board to mark where to nail into the rafters under the plywood; use the screw heads on the white board and the visible end of the rafter at the peak as references.
 - Use framing nails to nail the plywood to the rafters every 8", at these marks.
 - Repeat on the other side of the home.

`#align(center)[#rect(stroke: none)[#image("images/panel_options.dxf", width:70%, layers:"Framing,Plywood 1,Plywood 2")]];`{=typst}

`#pagebreak()`{=typst}

## Fascia Boards
 - With one person holding the fascia board from the roof and another on a ladder, position one fascia board on the back
of the home so that it is flush with the top of the plywood, and its upper end is exactly on the parting line between the
two 1x6 boards that form the ridge beam.  Using panel nails, nail fascia board to the rafter behind it.
 - Line up the second fascia board on the other side of the roof at the back of the home so that it is flush with the roof deck
and so that the center seam is tight.  Nail this board to the rafter behind it, with 2 nails an inch from each end, and one nail
every 8" - 10" between.
 - After installing soffits (below) repeat these steps on the front of the home.

## Soffets
 - From a ladder, use a pencil to mark the position of each of the cross blocks; mark on the outside or bottom edge of the fascia.
 - From a ladder, position each soffet board so that it is tight against the ridge beam (white boards at the peak) and against the T1-11 siding.
If the soffet is too wide, mark where it needs to be trimmed, and trim on the table saw.  There is a sled that will allow you to adjust
the angle of the cut from one end to the other, so that this cut can be made safely.
 - Using panel nails, nail the soffet into the cross blocks between the end rafter and the rafter resting on the end wall.

## Metal Flashing
 - Prepare the coil nailer. Add 2-3 drops of gun oil into the compressed-air fitting, and connect the air hose to the coil nailer.
 Load short roofing nails into the coil magazine, after adjusting the coil platform to the upper position.
 - At one eave, place a 10' length of metal flashing against the edge of the white board flush with the outer edge of the rear fascia board,
and nail through the eave whiteboard into the rafters, using the coil nailer.
 - Place a short piece of flashing against the edge of the white board flush with the outer edge of the front fascia board and overlapping
the long flashing.  Nail this piece through the whiteboard into the rafters, and nail once through the end of the short flashing
(this nail will show through the whiteboard, but that cannot be helped.)
 - Place one of the long pieces of metal flashing that has been partially cut in the middle so that it extends over the peak from one eave
to the other, and overlaps the end of the eave flashing.  Overlap the vertical parts of the flashing at the peak.  If one end hangs over
beyond the eave flashing, trim it with metal shears.
 - Nail the end flashing to the roof decking below, about 1¼" back from the outer edge of the flashing.
 - Repeat on the other end of the roof.

`#pagebreak()`{=typst}

## Flexible Flashing
- At each eave, peel the backing paper off the first foot or two of a roll of flexible flashing, and position the
  flashing nearly even with the end flashing, and about ¼" up from the outer edge of the eave flashing.  Press this
  section down, and then, with a helper, roll out more material from the roll, set the flashing approximately where you
  want it, and then pull the brown paper out sideways from under the flashing, pressing the flashing into place as you
  go.
 - Cut the flexible flashing to length at the other end of the eave, and press the last length down onto both the metal flashing and the whiteboard.
 - Repeat on the other eave.
 - At the corner on one side of the house, start a line of flexible flashing up the end of the roof toward the peak, and extend
 this all the way over the peak and down the opposite side of the roof, ending with a full overlap of the horizontal run of flexible flashing.
 - Repeat on the other end.

## Tar Paper
 - Find two roofing gauges (probably on the skymobiles), to measure the overhang of tar paper and shingles.
 - Unroll a length of tar paper on the lower part of the roof, and position it so that the tar paper extends 1" beyond
 the metal flashing on each end of the roll, and 1" below the eave flashing.  The roofing gauges make checking the overhang easier.
 - Staple the tar paper to the roof plywood: 3 rows of staples about 12" apart, one near the top of the sheet, one in the middle,
 and one about 3" above the bottom of the sheet, to avoid stapling into the metal flashing.
 - Unroll a second length of tar paper and position it again with 1" overhang on each end, and lined up at the top with the upper edge
 of the plywood, keeping the vent openings clear.  This sheet will overlap the lower tar paper sheet.
 - Staple this sheet in the same manner as the lower sheet.
 - Repeat on the other side of the home.

`#pagebreak()`{=typst}

## Shingles
 - Underlay Course (Starter Row)
     - Use single layer starter shingles.
     - Starting at the front of the home, position a starter shingle parallel to the eave edge hanging over 1" beyond the front fascia
       and 1" below the eave edge. (These should line up with the tar paper.)
    - Nail 3 places about 2" below the top edge of the shingle.
    - Similarly position 2 more starter shingles, maintaining the 1" overhang at the eave, and butted up against the previous shingle.
      Nail these in place.
    - Position a 4th starter shingle overhanging the rear fascia by 1" and extending 1" below the eave edge.  Nail it in place.
    - Cut a small piece of scrap to fill in the 2"-3" gap, and nail that in place.
    - Repeat on the other side of the home.
    - Position a starter shingle running up the rear edge of the roof, overlapping the shingle at the eave by 1½", and hanging 1" beyond the
      outer edge of the rear fascia. Nail it in place.
    - Repeat, running a row of these starter shingles all the way over the peak, and ending at the eave row on the other side.
      The last shingle in this row should overlap the eave shingle row by 1½"; trim the last one as necessary.
    - Similarly, place and nail a row of starter shingles at the front of the roof.
 
- First 8 Courses
    - Separate the start and end shingles, keeping them in the same order.  Count the first 8 pieces and separate them from the second 8.
The first start shingle should be a long one, so if that is not so, either swap the starts and ends, or turn both groups over.  Then the top start shingle should be long and the first end shingle should be short.
    - Review the pieces to determine which end is factory-cut and which was cut on the Shingleator.  Factory edges should hang ove the roof edges,
      while the Shingleator edges should butt up to the whole shingles in each row.
    - Set the first start shingle so that it extends 1" beyond the outer edge of the front fascia board and 1" below the eave edge.
 Nail it in 3 or 4 places, setting the nails just above the black tar strip.
    - Using standard (double-layer) shingles, set three full shingles, each butted up against the previous one, and each extending 1" below the eave edge.  Nail these in place.
    - The first end shingle should then fill the space left in this row, and extend 1" beyond the outer edge of the rear fascia board. Nail it in place.
    - For each succeeding row, set the start shingle so that its lower edge lines up with the cutout pattern in the shingle under it, and with a 1" overhang of the front fascia.  Set three full shingles next, also lined up with their bottom edges even with the cutout pattern on the shingles below them.  The ending shingle for the row should then fill the remaining space in that row at the back of the home.
    - There should be no nail heads visible, except in the 8th row, where they will be covered up in the next step.  If there are any, that is a mistake.  You will have to come back and caulk them after the shingling is complete.

- 9th Course
    - Using the shingles trimmed down for this course (marked "9"), position the start shingle overhanging the front fascia by 1", as before,
but for this row, align the **top** of the shingle with the top edge of the plywood (or tar paper).  Nail the start shingle down.
    - Position and nail down the 3 full shingles for this row, each butted against the previous one, and with the top even with the edge of the plywood.
    - The end shingle for this row should fill the space left, and hang over the rear fascia by 1".

- 10th Course
    - Using the half-height shingles, position the start shingle so that it hangs over the front fascia by 1" and is even with the top edge
of the plywood.  Nail it in place, setting the nails about 1" below the top edge of the shingle.
    - Position and nail down the 3 full-width shingles for this row, each butted against the previous one, and with the top even with the edge of the plywood.
    - The end shingle for this row should fill the space left, and hang over the rear fascia by 1".
     
## Ridge Vent
- Once both sides of the roof are shingled, install the roof vent.
    - Remove the remaining coil of short roofing nails from the coil nailer, reset the coil platform to its lower position,
and insert a coil of longer roofing nails.
    - Prepare the long section of ridge vent, by caulking a foam plug into the space between the two honeycomb sections.
Spread a line of exterior caulk on the orange side of the foam plug, and press this into the space at one end of the ridge vent.
This end will hang out over the rear of the home.
    - Spread two lines of exterior caulk on the under side of the vent, following the stitching that holds the pink fabric to the vent.
    - With a helper, fold the vent partly (to make is stiffer) and position this section of vent so that it is centered side-to-side on the ridge
and hangs over the rear of the home about 2" beyond the fascia (1" longer than the shingles.)  Press down to make sure the caulk adheres
to the shingles, and nail on each side of the vent about 1" in from the edge and about 12" apart.
    - If there are three pieces of vent, install the remaining long one next.  Caulk along the seams, butt this piece against the one
      already installed, center it side-to-side, and nail it in place.
    - Trial-fit the remaining piece of vent, to make sure it extends about 2" forward from the front fascia, and trim it if necessary.
      Prepare it as for the rear section, including inserting a plug at the forward end of the ridge. 
    - Caulk this piece as described above.
    - Position this piece of vent so that it butts against the previously installed section of vent, and is centered on the ridge.
    - Nail it in place.

## Cap Shingles
- If these tear-off shingles are not already separated into three 13"x13" pieces, fold each one along the perforations and tear them into this size.
- Starting at the rear of the home, place a cap shingle even with the end of the ridge vent and centered over it from side to side.
- Nail in two places, about 2" in from each side and on the side of the black adhesive stripe away from the end of the home.
- Overlap the next cap shingle so that it covers the adhesive stripe and the dark-colored transition area on the previous one
  and is centered side-to-side over the ridge vent. Nail it in place.
- Repeat for a total of 14-16 cap shingles.  This should bring you near the middle of the ridge.
- Begin again at the front of the home, setting the first cap shingle even with the end of the ridge vent, and overlapping cap shingles
  until you reach the shingles from the rear of the home.
- Install the last shingle of the front half so that it overlaps the last one from the back half.
- Cut one more shingle just below the adhesive line, and install the short piece over the seam between the front and rear halves of the cap.
Nail this final cap shingle in four places.
- Caulk these four nail heads, being sure that the caulk seals onto the shingle material on all sides of the nail.  To improve the look, sprinkle a little of the shingle dust on each caulk spot, so that in blends in with the color of the rest of the roof.

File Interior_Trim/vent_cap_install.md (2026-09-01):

---
no-title-page: true
---

# VENT CAP INSTALLATION

1.  Cut two 11½" 2x4 blocks (jenga blocks) in half to yield the 5½"
    support blocks.

2.  Preset 2 brown screws in the center of each block, as shown opposite.

3.  Position the T-shaped guide against the trim on the back wall, and
    mark along the white ridge boards where three of the four support
    blocks should go. Reverse the guide, placing the T against the trim
    on the front wall, and mark the fourth block position.

4.  Position a support block crosswise on the vent blocks with its edges
    at the pencil marks, and use a spirit level to verify that the block
    is approximately parallel to the floor. If it is not, insert a shim
    between the support block and the vent-block.

5.  Drive the two screws into the white ridge boards. This is a **lot**
    easier if one person holds the block (and any shim) in place while
    the second person drives the screws in.

6.  Similarly, install the other three support blocks.

7.  Position the long drill pattern against one side of the 96" plywood
    piece, matching the end of the pattern with the end of the
    plywood. Mark the locations for 6 holes, as shown in the diagram
    opposite. Drill, countersink, and preset 3" brown screws in these 6
    places.

8.  With two people, position this vent cap on the blocks, starting at
    the rear of the home. The rear edge of the vent cap should touch
    the rear wall trim, and be centered on the white ridge
    boards. The front edge of the vent cap should be half-way onto the
    mounting block at the front. Drive one screw most of the way into
    the rear mounting block.

9.  Check that the front of the vent cap is centered; then drive both
    screws fully into the rear mounting block.

(More on next page)

`#fullpage("Images/vent_cap.dxf", layers:"0,Dimensions")`{=typst}

10. While one person continues to support the vent cap, the other person
    drives the two screws in the middle of the vent cap into their
    mounting block, and then finally drives the two screws at the front
    of the vent cap into their mounting block.

11. Measure the distance from the front edge of the installed vent cap
    to the front wall trim, and cut the shorter piece of
    plywood to this length.

12. Mark, drill, countersink, and preset 4 screws in this piece, as
    shown in the diagram on the previous page.

13. With two people, position this plywood piece so that it butts
    against the long vent cap previously installed, and make sure the
    two pieces form a straight line. Drive in the screws at the joint
    between the two pieces of the vent cap, and then drive in the screws
    near the front wall.

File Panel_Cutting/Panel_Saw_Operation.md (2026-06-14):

```{=typst}
#title-page[
  #text(36pt, weight: "bold")[Panel Saw]
  #v(1em)
  #text(16pt)[Panel Saw Operation] \
  #text(16pt)[Roof Panels] \
  #text(16pt)[Exterior Panels] \
  #text(16pt)[Interior Panels]
]
```

# Panel Saw Operation

1. The panel saw can cut in two directions: horizontally or
   vertically. The operation is slightly different for these two kinds
   of cuts, so it is important to keep in mind which one you are
   performing.

1. In all cases, let the saw do the cutting; do not force it through
   the material, or the material through the saw. Check each piece of
   paneling for staples: running one staple through the saw will chip
   a carbide tooth, and soon the blade will be worthless.

1. Before loading the first panel onto the saw carriage, TURN ON the
   dust collector. The switch for this is behind the saw frame on the
   left, where it will be inaccessible once you load a panel onto the
   saw.

1. For horizontal cuts, pull the two black knobs on the saw turntable
   toward you, and rotate the table so that the arrow labeled FEED
   points to the left. When you release the locking knobs, they should
   snap into place, and the table should not rotate any further. Then,
   set the height of the cut, either with a jig or by using the
   (hidden) scale at the left of the saw table. Lock down the carriage
   by tightening the black handles on each round guide rail.

1. For vertical cuts, pull the two black knobs on the saw turntable
   and rotate the table so that the arrow labeled FEED points
   DOWN. Loosen the locking handles on the guide rails, so that the
   saw table is free to move vertically, and raise it all the way up.

`#pagebreak()`{=typst}

# Roof Panels

1. The material for the exterior is ¾" CDX plywood. Neither side is
   very pretty, but one is usually worse. That side should face you
   when sawing roof panels.

1. You will only need to make vertical cuts for this process. Set a
   block to act as a saw stop for 77 ¾"

1. Cut 4 panels for each home, placing them on an orange panel
   cart. Generally, put a maximum of 8 panels on a cart.

1. Secure the panels to the cart with a strap before moving the cart.

`#pagebreak()`{=typst}

# Exterior Panels

1. The material for the exterior is T1-11 siding. It is fairly
   flexible, and requires some care to make sure it is kept flat as it
   is being sawed.

1. You will cut two homes' worth of panels at once, and should place
   two orange panel carts by the panel saw.

1. Cut all panels from 96" to 93½" using the jig labeled "T1-11
   Exterior Panel 93½".  The jig has feet labeled 1 and 5, to be
   placed in the saw carriage's slots 1 (unlabled) and 5. Ensure blue
   tape marks line up.

1. Make sure the saw is set for vertical cuts, and that the saw table
   is all the way up and the vacuum is on. Place a panel (good side
   away from you) on the panel saw rollers on the left carriage, and
   slide the panel into the saw until it touches the panel-stop.

1. Turn on the saw (green button), place a foot on the panel OUTSIDE
   the left guide rail, flattening the panel, and lower the saw table
   to cut the panel. When you reach the bottom, have one person pull
   the panel away from the blade as another pulls the off-cut up to
   free the blade, and turn the saw off. The off-cut is trash.

1. Remove the panel, and place it on one of the panel carts.

1. Each home needs 8 solid panels and 2 panels with windows cut out of
   them. When cutting panels for two homes, load one cart with 12
   panels and one with 8.

1. There is a separate jig for window cutouts. For this process, you
   will need a router, a drill with a spade bit in it, and a broom and
   dustpan. (also two clamps which live in the jig)

1. Move the 12-panel cart you have designated for window panels up
   fairly close to the jig, and bring the other cart next to it.

1. Place a panel from the 12-panel cart on the jig, right side up, and
   with the tongue against the stop. (The tongue is the thinner edge
   extending the not-pretty side of the panel). Make sure the panel
   slides under the blocks at the jig's closed corner, and seats both
   along the long tongue edge and at the top of the panel. Clamp the
   panel using the fixed clamps, and also use 2 clamps where it says
   CLAMP on the jig.

1. Bore an access hole where it is indicated by two arrows on the jig,
   and route out the window.

1. Unclamp the panel and place it on the 8-panel cart.

1. Repeat steps 10-12 four times. You should end up with a total of 8
   solid panels and 2 window panels on each home-panel cart. Re-secure
   these panels to their cart.

1. Sweep up as much sawdust as possible and vacuum the jig.

`#pagebreak()`{=typst}

# Interior Panels

- The material for the interior is 15/32" plywood. The good side goes
  against the carriage when sawing.

- You will need one orange panel cart for each home's panels, and one
  extra one, to hold panels temporarily.

- Follow the **Interior Panels Cut List** laminated sheet which details
  the cuts that will be made.

- Horizontal cuts: There are jigs to set the saw table height for each
  panel size. To use one, set the end marked DOWN on the yellow tabs
  at the bottom of the saw frame between the two guide rails, and then
  lower the saw table until the bottom edge of the table rests on the
  ledge of the jig. The words "tuck under bottom of saw carriage"
  should NOT go under the table, but rest in front of the saw
  table. Lock the saw table in place, and remove the jig.
  Make all the horizontal cuts described on the cut list first.

- Vertical cuts: Insert the correct panel-stop with the feet between
  the feed rollers on the right carriage of the panel saw, so that
  slot numbers match and the blue tape on the panel-stop matches the
  blue tape on the panel saw carriage.

- All markings should be made in PENCIL, and about a foot in from the
  top-left corner.

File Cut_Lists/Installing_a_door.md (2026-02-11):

---
no-title-page: true
---

# Installing a door – checklist (rtfm)

## Prepare:
- Reinforce door trim corners – brown screws
- Be sure to remove plastic feet from bottom of door frame
- Flexible flashing across bottom of opening and 8" up each side (see instruction manual)

## Install:
- Tilt door into opening, bottom first. (Remove plug holding the door shut first.)
- Shims to align door frame with steel door
- Parallel across top of door
- Parallel on latch side of door
- \#10 Screws to anchor frame to building. Shim behind door frame at each location:
  - above top hinge
  - high on latch side of frame
  - above bottom hinge
  - low on latch side of frame
  - above middle hinge
  - two screws, above and below latch cutout. See instruction book for positioning. Aim for 1/8" gap between door and frame on this side.
  - two screws up through top of door frame. Use plywood to fill most of the opening.
- Three screws through flooring into platform. Use 3" plated screws to match ADA threshold

## Finish:
- Remove one screw from each hinge, and replace with 3" plated screw.
- Trim visible flexible flashing from either side of exterior door trim and from under threshold.
- Trim all shims to be even with interior plywood walls
- Remove weatherstripping from sides and top of door frame, and save these.
- If wiper comes off the bottom of the door, remove it completely, and save with other weatherstripping.

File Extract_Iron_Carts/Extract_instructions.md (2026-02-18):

```{=typst}
#show heading.where(level: 2): it=>{ set text(size: 18pt, weight: "regular"); align(center, block(above: .5em, below: 1em)[#it])}

#title-page[
  #text(36pt, weight: "bold")[Extracting Iron Carts]
  #v(1em)
  #text(24pt)[Instructions]
]
```

# Removing Iron Carts from under a Home

This is an inherently simple process, but the chances for a mishap are fairly high.  Given that the weight of a finished home is around 4000 pounds, extreme care is needed when performing this operation.

## Safety Precautions
- Identify the team: front-jack, rear-jack, assistants.
- Warn all other personnel to remain 15 feet away from the operation
- Remind all team members to stay on their feet during the extraction.  No one is to be on their knees once the home is lifted to begin the extraction.

`#v(36pt)`{=typst}

## Prepare

- Collect tools: two hydraulic jacks, the cart with triple blocks and 4x4 stands, orange straps with hooks to pull the carts out, and 4 auto dollies.
- Position jacks so that the center of each jack is lined up side to side with the joint line of the front or rear paneling, and so that the two square load pads are just inside the siding.  These load pads should make contact with the double 2x6 framing of the platform.  It is important that you do not try to raise the home by applying force to the bottom edge of the siding (which overhangs the framing).
- At the rear, position the 4x4 stands at either corner of the home.  In the next step, they will be positioned precisely, but having them near the right position allows the person running the jack to see how high to raise the rear of the home.
- Position triple blocks under the iron carts, so that they are about 18" from the end of the skids, and centered side-to-side on those skids.  Wrap the extraction ropes to one side of each triple block, so that when the carts roll out, they do not run over the ropes.
- Have auto dollies nearby.  It is embarrassing if you have to run off to fetch these at the point where you will need them, because the home will be precariously perched on a raised jack without a lot of support.
- Communication between the front and rear jack managers is essential, so that the home remains stable.  **Never** allow the home to be raised on both jacks at the same time.

`#fullpage("images/01_Prepare.pdf")`{=typst}

## Raise the rear

- Announce loudly "Back Going Up", and get acknowledgment from the front-jack person.
- Make sure that the jack handle is rotated clockwise, to close the hydraulic valve and allow the jack to raise the home.  Repeatedly operate the handle to raise the rear of the home just far enough to make it possible for helpers to slide the 4x4 stands under the home.
- Position each stand so that the 4x4 post is just inside the siding; this will allow the platform frame to rest on the posts as the jack is lowered.

`#horizontal-center("images/02_Rear_Raised.pdf"); #pagebreak()`{=typst}

## Lower rear of home onto stands

- Announce loudly "Back Going Down", and get acknowledgment from the front-jack person.

- Once the stands are in position, have the helpers move away from the home, and then cautiously rotate the jack handle counterclockwise to lower the home.  This is easier to control if you grip the jack handle where the foam rubber liner covers the handle.
- When the home is resting solidly on the two posts, call out to the front, saying "Back is on the posts".

`#v(72pt); #horizontal-center("images/03_Rear_Dropped_onto_Posts.pdf"); #pagebreak()`{=typst}

## Raise the front

- When the rear is solidly on the two 4x4 posts, start to raise the front of the home.
- Announce loudly "Front Going Up"
- The front only needs to be raised a few inches, so that the skids no longer rest on the iron carts.  Do not raise it further, so that the flanges at the front of the cart will help to guide the path of the cart as it is extracted.
- Have two helpers hook the ends of the extraction straps to the front of each iron cart, one hook on either side of the skid flanges, and pull the cart straight out from under the home. If the cart path is not straight, the rear flanges will bind up on the skid, and make it very difficult to pull the cart out without pulling the home off the rear stands.
- The carts can then be taken to the materials area for reloading.

`#horizontal-center("images/04_Front_Raised.pdf"); #pagebreak()`{=typst}

- Verify the position of the front triple blocks, making sure that they are centered side-to-side under the skids, and about 18" from the end of each skid.  This will leave room for an auto dolly to be placed between the end of the skid and the triple block in the next step.

`#horizontal-center("images/05_Carts_Removed.pdf"); #pagebreak()`{=typst}

# Drop front onto triple blocks

- Once the triple blocks are in place, announced "Front Going Down", and get acknowledgment from the rear jack operator.
- Lower the front of the home onto the blocks, leaving the jack just in contact with the frame, but not bearing any of the weight of the home.  This will provide additional stability in the next step.
- Position the two front auto dollies under the front ends of the skids, about 4" back from the end of the flat bottom of the skids.
- When the front is resting solidly on the triple blocks, call out to the rear saying "Front is on the blocks.

`#horizontal-center("images/07_Lowered_onto_Front_Triple_Blocks.pdf"); #pagebreak()`{=typst}

## Raise rear, remove posts

- When the  front is solidly on the blocks, begin to raise the rear.
- Announce loudly "Back Going Up", and get acknowledgment from the front-jack operator.
- Raise the rear just far enough that helpers can remove the two 4x4 stands from the corners of the home.
- Verify the position of the rear triple blocks, making sure that they are centered side-to-side under the skids, and about 18" from the end of each skid.  This will leave room for an auto dolly to be placed between the end of the skid and the triple block in the next step.

`#horizontal-center("images/08_Rear_remove_Posts.pdf"); #pagebreak()`{=typst}

- Have helpers move out of the way.
- Announce loudly "Back Going Down", and get acknowledgment from the front-jack operator.
- Lower the rear of the home by releasing the hydraulic pressure in the jack, turning the jack handle gently counterclockwise.  Leave the rear jack just in contact with the platform frame, but not bearing any of the weight of the home.
- Position the two rear auto dollies under the rear ends of the skids, about 4" forward from the end of the flat bottom of the skids.
 - When the home is resting solidly on the triple blocks, call out the front saying "Back is down on the blocks.

`#horizontal-center("images/09_Rear_lowered_onto_Triple_Blocks.pdf"); #pagebreak()`{=typst}

## Raise front, remove triple blocks

- When the rear of the home has been lowered onto the triple blocks, announce "Front going up", and get acknowledgment from the rear-jack operator.
- Raise the front of the home just a few inches, so that helpers can pull the front triple blocks out from under the skids.
- Verify that the auto dollies are positioned about 4" inward from the end of the flat bottom of each skid, and centered side-to-side, so that when the home is lowered, each skid will rest evenly in the center of its auto dolly.

`#horizontal-center("images/10_Remove_Front_Triple_Blocks.pdf"); #pagebreak()`{=typst}

## Drop front to final position

- Have helpers move out of the way.
- Once the front blocks have been removed and the helpers are clear of the home, lower the front jack all the way, so that the skids are resting on the front auto dollies.
- Call out to the rear, saying "Front is on the dollies".

`#horizontal-center("images/11_Front_Dollies_in_place.pdf"); #pagebreak()`{=typst}

## Raise rear, remove triple blocks

- When the front of the home is down on its auto dollies, announce "Back going up".
- Raise the rear just a few inches, so that helpers can pull the rear triple blocks out from under the skids.
- Verify that the auto dollies are positioned about 4" inward from the end of the flat bottom of each skid, and centered side-to-side,
 so that when the home is lowered, each skid will rest evenly in the center of its auto dolly.

`#horizontal-center("images/12_Remove_Rear_Triple_Blocks.pdf"); #pagebreak()`{=typst}

## Drop rear to final position

- Have helpers move out of the way.
- Once the front blocks have been removed and the helpers are clear of the home, announce "Back going down", and get acknowledgment from the front-jack operator.
- lower the rear jack all the way, so that the skids are resting on the rear auto dollies.
- Announce "Back is on the dollies".
- Pack up the 4x4 stands, the triple blocks, and the iron cart extraction straps into the storage cart.
- Return jacks and cart to storage location.

`#horizontal-center("images/13_Home_in_Final_Position.pdf")`{=typst}

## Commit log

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2025-03-12 Added temp screws below door on front wall; cleaned up drawings on platform and rear wall; larger font for all docs, in manual-template.docx
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2025-03-12 Formatting changes; recovered final step to install bottom board next to doorway.
2025-05-07 Added Quality Check heading and item about protruding screws on bird blocking.
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2026-01-10 Revised per process change on door prep, since several items duplicate work done in previous door prep, and added instructions to ensure that the door frame sits firmly on the bottom of the doorway.
2026-01-14 Added Word docs representing Cut Lists. These should end up as Markdown, with a .docx only to include the revision date.
2026-01-14 Add miscellaneous instructions so that they are more generally accessible
    [Triangle_screws.dxf, Upper_Step.dxf, empty_dwg.dxf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]
2026-01-14 Cut_Lists: manual cleanup & editing of markdown files.
    Among others:
    - Added markdown headers (#, ##) to all pages.
    - Added headers to all tables since GFM auto-promotes the first row to
    header if there isn't a header.
    - Replaced "smart" single & double quotes with simple ones:
    sed -i -e 's/[“”]/"/g' -e "s/’/'/g" *.md
    - Added images/Structural_Triangle_Parts.png extracted
    from Structural_Triangle_Parts.docx
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2026-01-26 render/go: make usable with podman instead of docker, too.
    Also make usable in SELinux context by specifying `z` option to the
    volume-mount.
    Both changes motivated by @dk-means AlmaLinux 8 setup.
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2026-02-03 render/go: make repeated runs emit identical PDFs.
    Typst defaults to embedding the current wall time in the generated
    PDF, which means that if it is run repeatedly on the same input it
    will appear to emit changed PDFs, which vary only in their embedded
    timestamps. This commit forces the "current time" to be the input's
    modification time so that if nothing else changed, the PDFs bits will
    be identical across re-runs.
    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
2026-02-11 Typst default page size is A4, which when printed on US 8.5x11 paper, just eliminates the footer. Specified 'us-letter' as default
2026-02-12 Create GitHub releases containing PDFs, rather than checking them in to the repo. (#11)
    Git is a (very) non-optimal way to manage generated data, especially when it's large.
    As an example, a checkout of the repo right now is 208MB large, with 128MB just for `.git` (i.e. for the 80MB of "current" data, we're storing an extra 40MB of obsolete .docx/.pdf/etc.). The longer the repo lives, and therefore the more edits land, and therefore the more versions of rendered PDFs are checked in, the larger this overhead will become. It's already not awesome to check out a new clone of the repo from GitHub (45s on my >1Gbps connection).
    This PR removes checked-in generated PDFs from the repo and replaces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
2026-02-13 Restore font face & size, and margins settings. (#12)
    When the typst-header.typ file switched from being used as a
    "header" (in addition to pandoc's default typst template) to being the
    entire typst template for pandoc (see #7 edit to `render/go` replacing
    `-H` with `--template`), we lost the propagation from
    `pandoc-defaults.yml` to typst configuration. This commit restores
    that.
    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
2026-02-13 Eliminate spaces from directory and file names in the repo. (#15)
    Why? Spaces make dealing with paths on the command-line and one-off
    scripting unnecessarily challenging.
    [Triangle_screws.dxf, rafter_dimensions.dxf, triangle.dxf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]
2026-02-13 Rename to avoid two outputs named interior_panels.pdf (modulo case). (#17)
    Hopefully will fix the failure in
    https://github.com/sfnw-dev-owner/process-manuals/actions/runs/21996384137/job/63557394439
2026-02-13 Pull pandoc/typst from GitHub's ghcr.io instead of hub.docker.com. (#19)
    Motivation is that currently the lion's share of time spent in release
    creation is pulling this image. Internet suggests github action
    runners have faster connectivity to ghcr.io than to docker hub (makes
    sense), so trying it out.
    Also made a silly correction to AC_prep/AC_Friedrich_Install.md to
    trigger action kickoff.
2026-02-14 Revision of README.md (#16)
    * Revision to track pandoc/typst formatting
    * Added URL for release area
    * Proofreading changes from review
2026-02-14 Revisions to Readme (#20)
    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
2026-02-14 Render PDFs on PRs, too, not just on commit to main. (#21)
    While commit to main will still trigger (live-forever) Releases, on
    PRs the generated PDFs have a limited lifetime (<=90d). This PR makes
    it so that PDFs are generated and a comment posted to the PR thread
    for reviewers to see the impact of the PR.
    Also trigger both PR & main workflows on edits to any file that
    impacts rendering (previously a spurious edit would have to be made to
    an .md file to e.g. trigger a new release after editing one of these
    other files, like typst-header.typ.
    render/all now explicitly pulls the docker image to avoid N parallel
    render/go processes from all fighting to pull the same layer files.
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2026-04-17 Lengthen Vent Cap (#40)
    * Improve clarity of cut list
    * Changed vent-cap installation to extend full length of the interior
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2026-06-12 Dkm door jamb (#52)
    * Added screw icon (#50)
    * Clarified door jamb reinforcement (#47)
    * Exterior trim: updated to reflect that window trim top piece is already precut to length. (#48)
    ---------
    * Finally trying to merge in change to door jamb reinforcement (#51)
    * Clarified door jamb reinforcement (#47)
    * Exterior trim: updated to reflect that window trim top piece is already precut to length. (#48)
    ---------
    * Fourth try to get updated drawing into GitHub
    ---------
2026-06-14 Cleanups: drop stale entries & files, document Misc/empty_dwg.dxf. (#54)
    This deletes:
    - Misc/Steel_Door_Conversion.docx, obsoleted by floor_door/ada_door_conversion.md
    - Outdoor_Steps/Upper_Step.dxf, no longer used
    - Many entries in .gitignore that (no longer) refer to files that ever exist.
    Also added a Misc/README.md to explain the use of the remaining
    Misc/empty_dwg.dxf file.
    [Upper_Step.dxf]
2026-06-14 Revision to catch up with current practice with 9" flooring widths (#53)
2026-06-14 Migrated Panel_Cutting/Panel_Saw_Operation.docx to MarkDown. (#57)
    Also made a bunch of editorial changes in the process to reflect how
    panels are cut nowadays.
    Removed the out-of-date interior panel cut list in favor of referring
    to the separate laminated sheet from
    Cut_Lists/Interior_Panels_Cut_List.md
2026-07-05 Door Alter and Install revised for clarity, with new drawings for locations of screws (#65)
2026-08-15 Interior_Panels_Cut_List.md: move E2 to follow H to avoid losing the off-cut in the general discard pile. (#74)
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2026-08-20 Workflow: create a release for any run on main, and drop paths filter. (#77)
    Previously a commit that only changed embedded images (like #76) would
    fail to trigger a release because of the paths filter. That filter was
    likely (I no longer definitively remember) introduced back when most
    of the repo was old-style .docx's and .pdf's managed elsewhere. I
    don't think we get any benefit from it anymore so propose to remove
    the paths filter.
    The workflow would further only create a release when run as the
    result of a push (on main). This PR will make it so that a release is
    created for manually-dispatched workflow runs (on main), as well.
    Finally, this PR updates .gitignore to reflect the split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
2026-08-29 render/ updates to support rendering DXF inputs. (#80)
    Includes a new render/example-dxf.md demonstrating this support using
    Interior_Trim/Images/rear_window.dxf which is not otherwise wired in
    to Interior_Trim yet (that'll be next).
    Continues the journey of #78.
    [rear_window.dxf]
2026-08-29 Delete obsolete Structural_Triangle/ DXFs. (#81)
    Per @dk-means email:
    > Triangle_screws.dxf was an abortive attempt to show where the preset
    > screws should go when someone is preparing a structural triangle for
    > installation. Steve came up with a better representation, and drew it
    > on the triangle jig, which is what we use today.
    >
    > rafter_dimensions.dxf was a study to confirm the fit between the
    > rafters and the structural triangles after we had completed the
    > redesign of those triangles. I may have used it once to create a
    > rafter template, but it is not trustworthy now. (I think we are at
    > Rev 2.1 on that template.)
    Deleting to make it easier to see what's going on while worki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
    [Triangle_screws.dxf, rafter_dimensions.dxf]
2026-08-29 Cut_Lists/Structural_Triangle_Parts.md: move to the DXF world. (#83)
    Replaces the checked-in PNG with its DXF source and references that
    from the markdown.
    Required a fix to render/dxf.lua where it assumed a raw inline always
    had the #image(...dxf) at the top level (and broke on this .md because
    of the nesting).
    Furthering #78.
    [triangle_parts.dxf]
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2026-08-30 Interior_Trim/interior_trim.md: convert embeddings .pdf's -> .dxf's. (#85)
    There are mild spacing differences (which I don't think are worth
    chasing down), and significant improvement to some of the
    renderings. The latter is due to dropping `mogrify -trim` from the
    previously-manual pipeline, since that rasterizes (poorly). This is
    particularly visible on page 17 "Front Window Shelf and Frame".
    First real win of #78.
    [combo_trim.dxf, front_window.dxf]
2026-09-01 Migrated vent-cap instructions to dxf-image model (#90)
    [vent_cap.dxf]
2026-09-01 Conversion to dxf-image model. Furthers #78 (#92)
    [side_wall.dxf]
2026-09-02 Conversion to dxf-image model. Furthers #78 (#93)
    [platform.dxf]
2026-09-02 Exterior Trim manual migrated to DXF model. (#95)
    [back_corner.dxf, front_window.dxf, rear_window.dxf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]
2026-09-03 Half Roof manual migrated to DXF model (#97)
    [half_roof.dxf]
2026-09-13 Updated instructions for generating PDF images (#98)
    * Updated instructions for generating PDF images
    * Corrected length of corner boards
2026-09-13 Dkm readme (#99)
    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
2026-09-13 Revisions to roof instructions, including migration to qcad drawing files (#101)
    [panel_options.dxf, start-end.dxf]
2026-09-15 Dkm qcad debug (#102)
    * Stripped-down PDF non-print bug
    * Bugfix: dxf file contained NaN for text angle. Removed
    [panel_options.dxf]
2026-09-16 Floor and Door manual conversions to DXF model (#103)
    * Floor and Door instructions migrated to DXF model
    * Removed extraneous PDFs after rename of containing directory
    [door_preparation.dxf, flooring.dxf]
2026-09-16 Migrated Rear Wall to DXF model (#104)
    [rear_wall.dxf]
2026-09-16 Dkm front wall (#105)
    * Migrated Front Wall manual to DXF model.
    There is a display bug that clobbers the nailgun icon for "no nail here"
    * Migrated Interior Panels manual to DXF model
    Furthers #78.
    [ceiling_panels.dxf, front_wall_ada.dxf, wall_panels.dxf]
2026-09-18 Drop repointToClipart in favor of encoding correct paths in the .dxf's. (#107)
    Originally DXF files' source of truth was outside this repo, so they
    pointed to an absolute directory on David's machine, so the rendering
    pipeline here rewrote clipart paths to work in the repo. Now that
    DXF's source of truth is this repo, we can make them point at the
    files in the repo.
    The .js and .lua changes here were made manually; the rest (the .dxf
    files) were automatically edited using:
    git grep -l '/home/means/Documents/TinyHomes/icons/' -- '*.dxf' |
    while IFS= read -r file; do
    depth="$(dirname "$file" | awk -F/ '{print NF}')"
    prefix=$(printf '../%.0s' $(seq "$depth"))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
    [ceiling_panels.dxf, door_preparation.dxf, front_wall_ada.dxf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]
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2026-10-29 Anchor the half-roof manual's notes to the model, sized in paper inches
    Notes (model/notes.py) are now specified in inches on paper and placed by
    points of the figure with standard stand-offs: beside() a point, as a
    callout() on a leader, a tool aimed() at a joint, a dimension() between
    two points, a circled() number, a title(). Components can name anchors
    (a rafter's tip, tail and bore) that figures hang notes on.
    Half_Roof/half_roof.md is the first manual drawn this way: its figures
    are one table in figures/half_roof.py (parts and their styles, tools,
    notes), with every note anchored to a rafter, block, board or inset of
    the drawing; roof.py no longer carries its annotations or the old
    dr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
2026-10-29 Anchor the platform manual's notes to the model
    Platform/platform.md's figures are one table in figures/platform.py:
    nail guns aimed at the joists' ends on the rims, clamp callouts and the
    pencil marks at the inner joists, the bracket marks from the rule in
    platform.py (bracket_marks: alternate sides of each skid from the front,
    inside at both doubled joists), the SAVE blocks as tools, callouts on
    the foam and blocks, the router line from the frame's extent. platform.py
    no longer carries annotations. (Its joist comments had the ends swapped:
    the rear is at Y = 0, as house.py places the walls.)
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2026-10-29 Anchor the exterior trim, door and floor manuals' notes to the model
    The exterior trim, door and floor figures become one table per manual
    with paper-inch notes placed off the model's geometry (figures/
    exterior_trim.py, figures/door.py, figures/floor.py). The *_manual
    functions, the old window/corner/gable/floor/door drawing code and the
    SketchUp views in doors.py move out of the model modules; exterior_trim
    gains alignment_block_at(corner), and Extent accepts other Extents.
    notes.arc draws the "flip" arrows for the rear window's precut boards.
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2026-10-29 Name the roof's remaining magic numbers in dimensions.py
    The rafter layout (doubled rafters 8"/11" in from the ends, five inner
    rafters on 24" centers from 30"), the angle plates' and cross blocks'
    positions down the slope, the end-bay rule (a bay 20" or narrower takes the
    shorter blocks and batts: roof.middle_bay) and the vent blocks' spacer
    length are now named and cited. The plates and cross blocks were placed
    from the DXF's origin, whose rafter tips were at 4.54: they're now 4 1/2
    (as the manual says) and 12 5/8, 26, 39 3/8 from the tips, a 1/25" shift.
    The cap-shingle loops count the shingles a half needs instead of 99.
    dimensions.py's docstring says how to read a citation of a deleted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
2026-10-31 Front wall corner: print the nail count from the model; prune TODO.md
    The front wall's window corner gets the same CORNER_NAILS (5) as the
    other corners, so the manual prints it from the model like the rear
    corners instead of saying 4.
    TODO.md: the "known differences from the old figures" are all the
    model's wins and need no record; the corner-nail question is settled;
    the first-wall brace is still used (on after the first side wall, off
    before the second), so the item to drop it goes; the lhs_jig item is done
    in the previous commit; and the triangle-screws item now says what it
    means (the preset screws' positions are to be corrected).
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2026-10-31 roof-blocking: the vent jig's middle clamp hangs below the jig's edge; the vent block clamp's tail points away from the worker
    The middle clamp was square to the slope at the jig's middle, its bar
    through the jig; it grips the jig's lower edge now, the bar hanging down
    the slope beside the rafter, as the old figure had it. The vent block
    clamp's fixed jaw goes on the block, its bar out beyond the ridge.
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2026-10-31 render: the crew's silhouettes are hidden a cell at a time, standing upright; figdiff drew mirrored icons upside down
    A silhouette was hidden by the whole outline of any solid in front of any
    part of its box, tilted to face the eye: a wall behind a climber's head
    wiped the climber, and a ladder's rails wiped the climber between them.
    Now the silhouette stands upright at its feet, its box is tested a cell at
    a time, and the icon is clipped to the cells nothing is in front of.
    figdiff's rasterizer turned a mirrored icon 180° besides flipping it.
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2026-11-02 Draw the tool and like-this/not-like-this insets from the model; drop the clipart traced from the old pages
    The 24 ptu_* and tu_* icons were pictures of things the model has or
    can make: the screws, hex screw, bar clamp and nail are the model's own
    parts in a parallel view (figures/insets.py); the blocks flush or
    stepped, tight or gapped, centered or not, in line or not are a few boxes
    each; the mallet, nail gun and driver are the clipart the repo already
    had; the raising crew are tilt-up's cut-out silhouettes, so the renderer's
    person-icon occlusion goes; the plywood carrier is a small new part.
    tu_hand.png (no hands in the gap) stays: nothing in the model draws a
    hand.
2026-11-02 Fastener insets at one scale, so a short screw looks short; the stud bay's screws poised above the plate
    Every fastener inset now shows the same 3-1/2" field, so the 1-1/2" screw
    beside the 3" one is half its length rather than told apart by thread
    density alone. This needed the renderer's stacked-view occlusion
    narrowed: views sharing a camera hid each other's parts, so the long
    screw's inset hid most of the short one's; only views stacked in the same
    rect do now. The secure-walls stud bay shows its four screws above the
    bottom plate where they go, not only their heads in it.
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2026-11-02 TODO.md: drop funky board #16, the front wall's brace, which the factory no longer uses
